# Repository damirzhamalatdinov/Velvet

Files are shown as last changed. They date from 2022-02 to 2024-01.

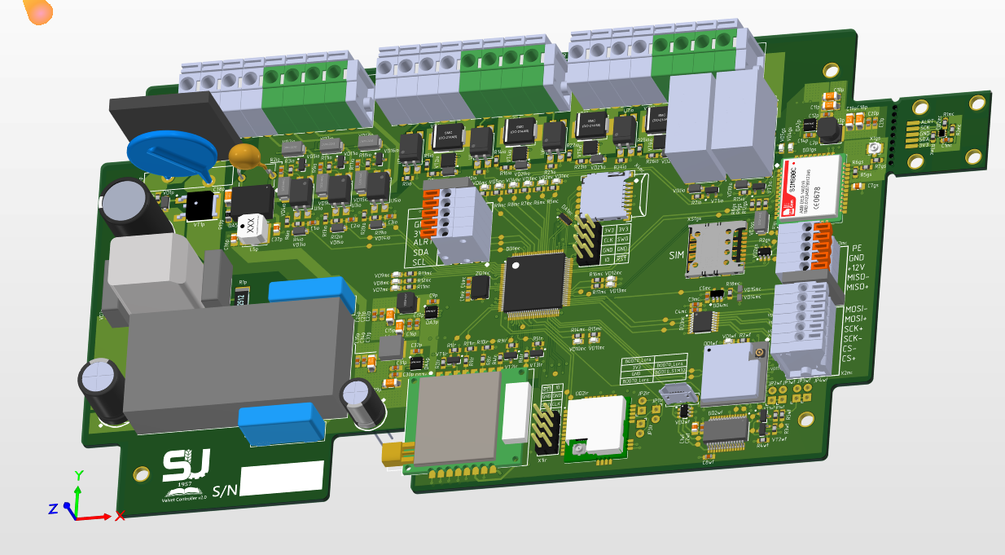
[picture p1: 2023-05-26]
Hardware_fabrication/Velvet Controller v2.0/3dview.png

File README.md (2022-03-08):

# Velvet
Репозиторий с файлами системы бесстресового взвешивания на базе STM32 (Далее: Velvet)
___
## 3D
Содержит 3D модели и сборки для системы бесстрессового взв.
* Velvet ADC - 3D модели и сборки АЦП Velvet.
* Velvet Controller - 3D модели и сборки контроллера Velvet
___
## Docs
Содержит сопутствующую проектам документацию.
* Velvet ADC - документация касающаяся АЦП Velvet
* Velvet Controller - документация касающаяся контроллера Velvet
___
## Software
Содержит исходные коды для контроллера
* Velvet Controller - исходные коды прошивки контроллера Velvet
___
## Software_release
Содержит бинарные файлы для прошивки контроллера Velvet
* Velvet Controller vX.X dd.mm.yyyy - бинарные файлы
___
## Hardware
Cодержит проекты печатных плат.
* Velvet_v1.1-2021(revised for PCB) - переработанный проект платы контроллера бестрессового взвешивания. 
    >Основная цель - актуальная библиотека компонентов. 
* Velvet ADC - проект схемы АЦП Velvet.
* Velvet Controller - проект схемы контроллера Velvet
___
## Hardware_release
Содержит файлы для производства и заказа печатных плат.
* Velvet ADC vX.X dd.mm.yyyy - файлы для производства АЦП Velvet
    * Velvet ADC Gerber vX.X dd.mm.yyyy - Gerber и NC Drill файлы
    * Velvet ADC BOM vX.X dd.mm.yyyy - список компонентов для закупа
* Velvet Controller vX.X dd.mm.yyyy - файлы для производства контроллера Velvet
    * Velvet Controller Gerber vX.X dd.mm.yyyy - Gerber и NC Drill файлы
    * Velvet Controller BOM vX.X dd.mm.yyyy - список компонентов для закупа
___
*При необходимости следует добавить папку "3D" для хранения исходных кодов*

*При необходимости следует добавить папку "Software" для хранения исходных кодов*

*При необходимости следует добавить папку "Файлы для производства и заказа" для хранения файлов для производства ПП и заказа комплектующих*

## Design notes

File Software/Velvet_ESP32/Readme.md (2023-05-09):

### Velvet_ESP32_STM_UART
   Проект ESP32_STM_UART предназначен для реализации протокола общения между микроконтроллерами ESP32 и STM32
с использованием интерфейса UART. Проект содержит файлы ESP32_STM_UART.h и Settings_ESP.h.
Структура проекта
 *main.cpp*
 *ESP32_STM_UART.h*
 *ESP32_STM_UART.cpp*
 *Settings_ESP.h*

**Протокол общения**
    Протокол общения между устройствами STM и ESP32 описан в документации проекта.
Протокол общения между устройствами представляет собой набор команд, передаваемых по UART. Команды от STM32
содержат определенные значения, указывающие на тип команды и ее параметры. Команды от ESP32 являются ответами на
соответствующие команды от STM32 и содержат информацию о выполнении команды и ее результатах.
В библиотеке ESP32_STM_UART реализованы методы для обработки входящих команд, отправки их на STM32, а также для
обработки ответов от STM32. Кроме того, библиотека содержит дополнительные методы для работы с UART, такие как
настройка скорости передачи данных и установка пинов для подключения интерфейса UART.
Для работы с библиотекой необходимо создать объект класса ESP32_STM_UART и вызвать методы для обработки команд и
отправки ответов. Подробная документация по каждому методу доступна в соответствующих файлах с исходным кодом.

## Инструкция к проекту.
    Для того чтобы собрать проект первым делом необходимо установить PlatformIO IDE. 
Если вы используете VSC установите расширение **PlatformIO IDE**. По завершению установки 
в левой боковой панели должна появиться иконка *PlatformIO IDE*. Кликните и откройте папку с проектом 
**Open project** или **Pick Folder**.
Если сделано правильно в нижней панели появится галочка **PlatformIO:Build Project**. Нажмите на нее и по завершению 
сборки проекта появиться сообщение 
============================== [SUCCESS] Took 12.48 seconds ========================== 

## Doxygen
# Инструкция по запуску doxygen
    Для начала необходимо установить doxygen на ОС. Если вы используете Ubunutu введите следующие команды в терминал:
*sudo apt update*
*sudo apt install doxygen*
    После этого откройте файл **Velvet_ESP32_STM_UART/docs/doxygen/doxygen_confing_2**
Замените следующие строки 
INPUT     = "**/full/path/to/project**/Velvet_ESP32_STM_UART"
OUTPUT_DIRECTORY       = "**/full/path/to/project**/Velvet_ESP32_STM_UART/docs/doxygen/output"
Как замена пути к проекту будет произведена перейдите в Velvet_ESP32_STM_UART/docs/doxygen/ 
и запустите команду в терминале **doxygen doxygen_confing_2**. В результате выполнения команды 
создается папка Velvet_ESP32_STM_UART/docs/doxygen/output. Перейдите в неё, затем в папку html. 
Запуститt файл index.html в браузере.

    Ссылка к инструкции по установке Doxygen https://www.doxygen.nl/manual/install.html

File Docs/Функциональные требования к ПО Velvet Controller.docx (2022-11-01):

# 1 ВВЕДЕНИЕ

Peggy Tracker создаётся для отслеживания геолокации крупного скота во время выпаса

## 1.1 Назначение данного документа

Данный документ определяет требования к встраиваемому программному обеспечению системы Velvet Controller, для исключения ошибок проектирования программного обеспечения, которые могут вызвать систематические отказы. Данный документ является входной информацией для документов «Архитектура программного обеспечения», «Описание программного обеспечения» и для непосредственной реализации программного обеспечения.

## 1.2 Термины, определения и сокращения

Встраиваемое программное обеспечение - программное обеспечение, непосредственно реализующее функции управления устройством, как правило, записанное в энергонезависимое ПЗУ устройства и заменяемое с помощью специальных программно-аппаратных средств.

ПО – программное обеспечение.

МК – микроконтроллер.

ТЗ – техническое задание.

ЦСМ – централизованная система мониторинга.

## 1.3 Рекомендации к ознакомлению

Перед ознакомлением данного документа рекомендуется изучить техническое задание (Техническое задание Velvet) и технические проекты (Технический проект Velvet Controller, технический проект Velvet ADC) на устройство Velvet Controller и Velvet ADC, а также следующие ссылки:

## 1.4 Назначение разработки

ПО разрабатывается для Velvet Controller на базе микроконтроллера STM32F407.

Структурная схема устройства Velvet Controller представлена на рисунке 1.

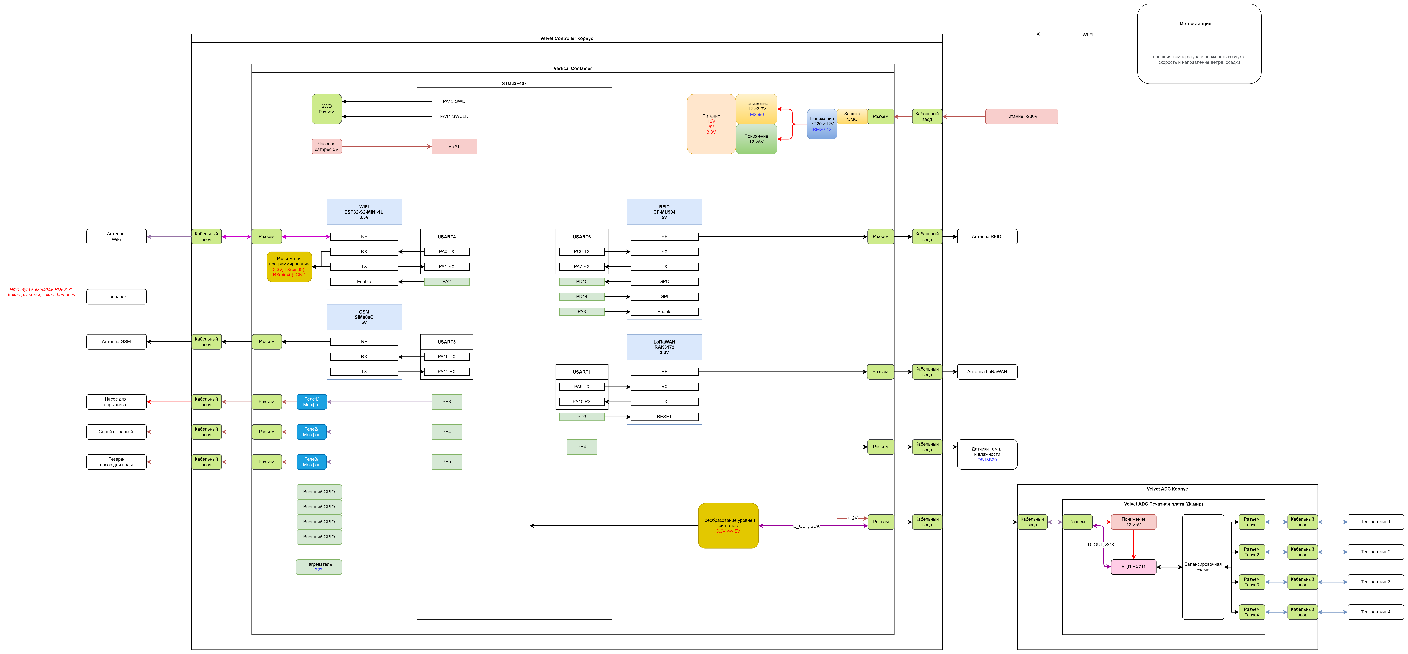
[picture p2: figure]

Рисунок 1.1 - Структурная схема устройства Peggy Tracker

МК STM32F407 содержит в себе ядро ARM Cortex M4. МК содержит до 1MБ Flash памяти программ и до 192КБ ОЗУ, 12 битный АЦП, SPI, I2C, I2S, UART интерфейсы.

# 2 Общие характеристики устройства

Задачей системы является идентификация КРС по RFID метке, фиксация веса КРС и отправка по протоколам Wi-Fi/GSM/LoRa, опрыскивание КРС по заданному алгоритму, мониторинг питания и климат контроль устройства Velvet. Первоначальный запуск системы осуществляется с участием человека, а дальнейшая работа происходит автоматически.

## 2.1 Функции, выполняемые устройством

Удаленное обновление ПО устройства.

Идентификация КРС при помощи RFID меток.

Измерение веса КРС при помощи дополнительного модуля АЦП Velvet ADC.

Опрыскивание КРС медицинскими препаратами.

Опрыскивание КРС краской.

Взаимодействие с сервером посредством Wi-Fi.

Взаимодействие с сервером посредством LoRa.

Взаимодействие с сервером посредством GSM.

Управление подогревом устройства.

## 2.2 Основные ограничения

1) Язык программирования C. Ограничение среды программирования применяемых МК.

## 2.3 Зависимости и влияние

Среда разработки STM32 Cube IDE или любая другая совместимая с микроконтроллерами STM32.

Для программирования МК может быть применен любой софт поддерживающий программатор ST-Link v2 или J-Link.

# 3 Определение требований

1) Программный код должен гарантированно выполняться за определённое время.
1) Необходимо обеспечить надежный алгоритм доставки сообщений до сервера.
2) Необходимо предусмотреть автоматическую перезагрузку устройства в случае зависания.
3) Необходимо предусмотреть удаленное обновление прошивки микроконтроллера.

## 3.1 Требования к функционированию МК

### 3.1.1 Удаленное обновление ПО устройства

Т.к. основной алгоритм ПО Velvet Controller исполняется на контроллере STM32F407 необходимо предусмотреть удаленное обновление ПО данного контроллера посредством Wi-Fi. ПО контроллера должно загружаться с удаленного сервера по HTTP протоколу. После получения бинарного файла необходимо подсчитать контрольную сумму CRC во избежание ошибок при передаче. Полученный файл должен быть загружен во Flash память контроллера STM32F407.

### 3.1.2 Идентификация КРС при помощи RFID меток

Для считывания RFID меток устройство имеет на борту модуль RFID CF-MU904.

Данный модуль подключен к МК STM32F407 через интерфейс USART6 и 3 GPIO. Один из GPIO управляет питанием модуля, два других используются для обмена событиями между контроллером и модулем.

Когда животное входит в зону видимости антенны RFID метка должна быть считана. Контроллер должен расшифровать ID животного и проверить CRC.

### 3.1.3 Измерение веса КРС при помощи дополнительного модуля Velvet ADC

Когда животное встает на платформу тензометрические датчики изменяют сигнал на своих выходах. Данный выходной сигнал оцифровывается высокоточных 24-х битным АЦП встроенным в Velvet ADC. Velvet Controller должен постоянно опрашивать значение сигнала на выходе Velvet ADC. Если животное было верно идентифицировано модулем RFID, вес можно считать корректным. Возможно применение дополнительных ограничивающих факторов для наиболее полной валидации данных Velvet ADC.

### 3.1.4 Опрыскивание КРС медицинскими препаратами / краской.

Когда животное на платформе корректно идентифицировано и взвешено, необходимо запросить с сервера информацию об опрыскивании. Сервер должен вернуть тип опрыскивания: краска или препарат; объём препарата / краски для опрыскивания. Если сервер вернул эти данные, то необходимо начать опрыскивание. Необходимо постоянно проверять валидно ли взвешивание животного и не вылит ли заданный объём препарата. Если опрыскивание прервано по одному из условий, то необходимо отправить на сервер объём вылитого препарата / краски.

### 3.1.5 Взаимодействие с сервером посредством Wi-Fi.

Для взаимодействия с сервером на борту Velvet Controller установлен модуль ESP32-S2-MINI-1U. Данный модуль связан с МК STM32F407 по интерфейсу USART4. МК STM32F407 может перезагрузить модуль ESP32-S2-MINI-1U при помощи входа ENABLE модуля.

Обмен данными с сервером реализуется по протоколу HTTP.

ESP32-S2-MINI-1U должен иметь возможность обновить ПО STM32F407.

### 3.1.6 Взаимодействие с сервером посредством LoRa.

Для взаимодействия с сервером на борту так же имеется модуль RAK3172. Модуль подключен к МК через интерфейс USART1. Модуль может быть выключен и включен входом RESET модуля. Модуль RAK3172 может быть использован только для отправки данных на сервер. При этом необходимо наличие шлюза LoRa внутри радиуса действия передатчика RAK3172. Шлюз должен выполнять функцию инкапсуляции данных полученных по LoRa в пакеты для сервера.

Пакеты LoRa должны обязательно содержать аппаратную контрольную сумму CRC. CRC должен проверяться на стороне шлюза.

### 3.1.7 Взаимодействие с сервером посредством GSM.

Для взаимодействия с сервером на борту также имеется модуль GSM SIM800C. Модуль подключен к контроллеру по USART3. Модуль поддерживает взаимодействие с сервером по сотовому протоколу 2G. Обмен данными может быть двусторонним.

### 3.1.8 Управление подогревом устройства.

На борту Velvet Controller присутствует датчик температуры DS18B20 и реле для управления нагревательным элементом. Данные датчика температуры должны считываться раз в минуту, должна производиться проверка CRC. В зависимости от показаний датчика включается или выключается нагреватель.

Температура внутри корпуса не должна опускаться ниже -20⁰C. с гистерезисом +-2⁰С.

# 4 ЛИСТ РЕГИСТРАЦИИ ИЗМЕНЕНИЙ

№ п/п | Пункт и вносимое изменение | Ф.И.О. внесшего изменения | Подп. | Дата
1 | Инициация | Байгуаныш С. | | 06.06.2022г.

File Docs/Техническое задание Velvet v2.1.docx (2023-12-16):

СОДЕРЖАНИЕ

# 1 Назначение

Предназначен для применения в составе системы автономного взвешивания и опрыскивания крупного рогатого скота Санта-Барбара.

# 2 Требования к функциональному составу

Возможность подключения от одного до четырех мостовых тензометрических датчиков.

Возможность балансировки сопротивления датчиков.

Вход для антенны WIFI диапазон 2.4ГГц.

Вход для антенны GSM.

Вход для антенны RFID 868МГц.

Вход для антенны LoRa 868МГц.

2 выхода для коммутации нагрузки постоянного тока 9-36В, 10А.

2 выхода для коммутации нагрузки переменного тока 220В 2А.

2 входа для подключения датчиков типа геркон.

Вход для подключения датчика дальности.

Система подогрева печатной платы.

Вход для питания от источника постоянного тока 9-36В.

Вход для программирования микроконтроллера STM32.

Вход для программирования микроконтроллера ESP32.

Слот для подключения micro SIM карты.

Слот для подключения micro SD карты.

3 светодиодных индикатора для программных задач.

Индикация наличия питания 9-36В.

ЭМС по ГОСТ 30804.6.1-2013.

# 3 Требования к интерфейсам

Отсутствуют.

# 4 Требования к цепям измерения и управления

## 4.1 Аналоговые входы

К аналоговым входам должны подключаться до четырех мостовых тензометрических датчика. Схема подключения приведена ниже:

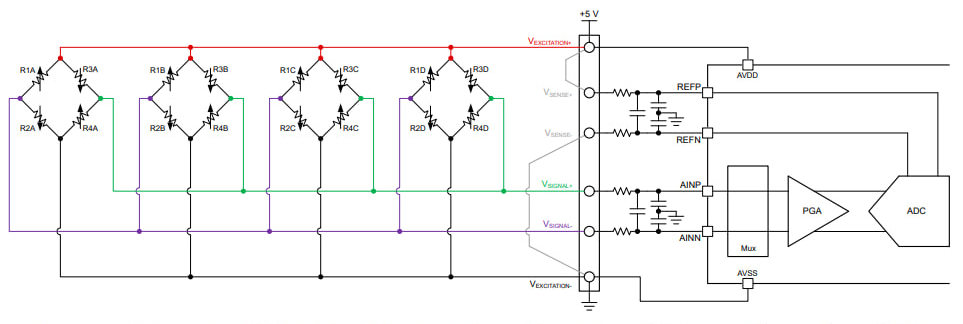
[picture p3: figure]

Рисунок 1 – схема подключения тензометрических датчиков

К аналоговых входам будут подключаться тензометрические датчики Zemic H8C-C3-500KG. Необходимо учесть возможность подключения датчиков по 4-ёх и по 6-ти проводной схеме подключения

## 4.2 Дискретные выходы:

Параметры дискретных выходов для коммутации нагрузки постоянного напряжения: напряжение нагрузки 9-36В, ток нагрузки продолжительно 10А, максимальная частота переключения 0.5Гц.

Параметры дискретных выходов для коммутации нагрузки переменного напряжения: номинальное действующее напряжение 220В, ток 2А, максимальная частота переключения 0.5Гц.

## 4.3 Дискретные входы

Логический ноль 0…4В

Логическая единица 9…24В

Диапазон питающего постоянного напряжения 9-36В.

# 5 Требования к схемотехническим решениям

Схемотехника изделия должна быть разработана согласно блок схеме на рисунке ниже.

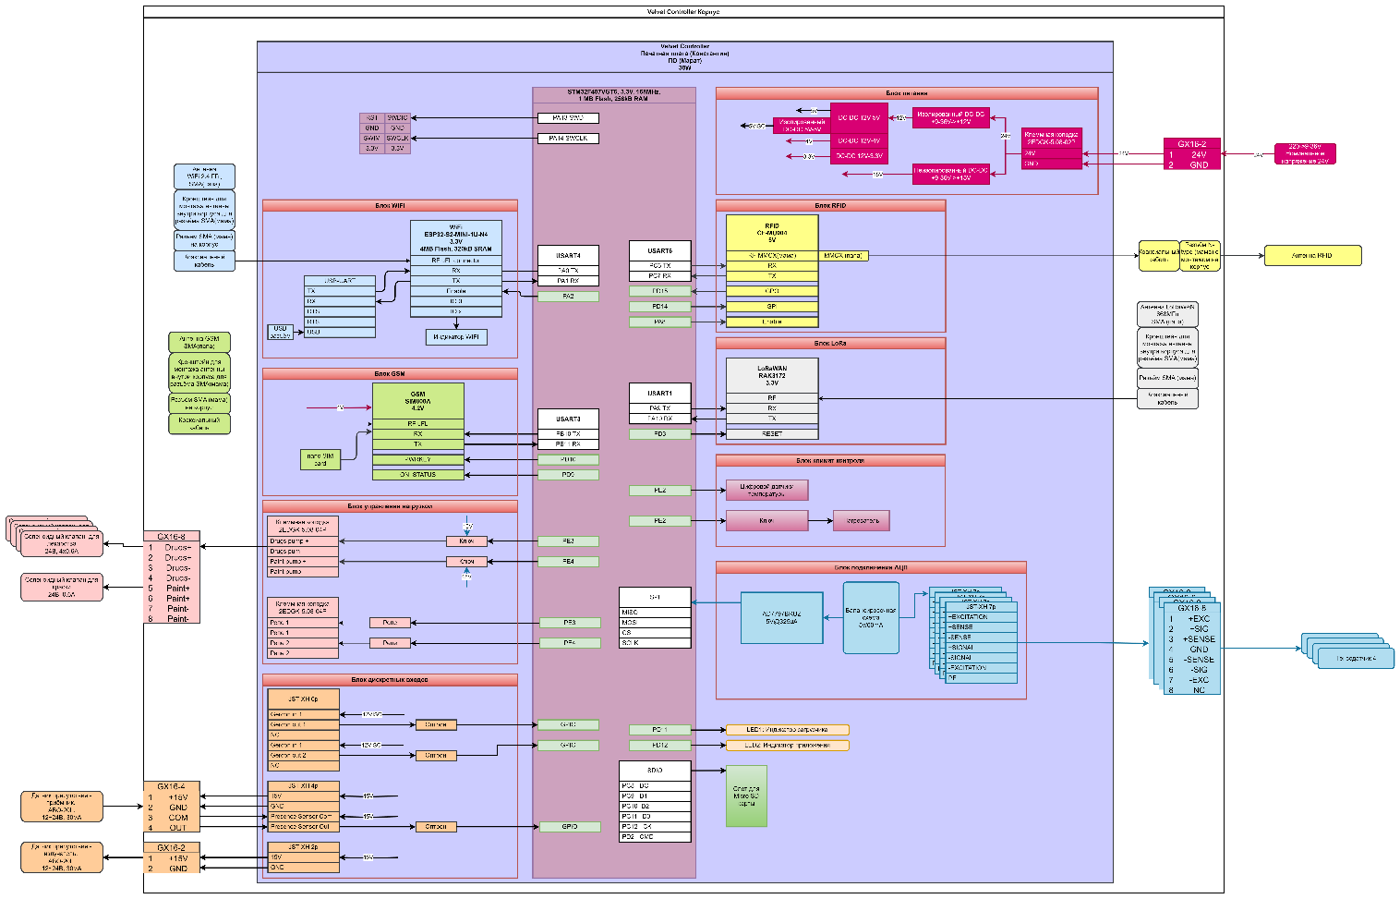
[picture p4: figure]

Рисунок 2 – Структурная схема Velvet v2.1

## 4.4 Питание

Питание может осуществляться от источника постоянного напряжения 9-36В.

Вход для источника постоянного напряжения должен быть защищен от обратного включения полярности. Вход питания 9-36В должен быть защищен от помех как порт электропитания постоянного тока по ГОСТ 30804.6.1-2013.

Наличие питания должно отображаться светодиодным индикатором зеленого цвета.

Подключение питания к корпусу должно осуществляться через разъём GX16-2. Питание от корпуса должно подключаться кабелем к печатной плате при помощи клеммной колодки типа 2EDGK-5.08-02P прямого типа.

Цепи питания МК1 и МК2 должны быть изолированы от цепи питания 9-36В.

Для работы Velvet необходимо обеспечить следующие уровни напряжения: 3.3В, 4В, 5В, дополнительная изолированная цепь питания 5В, 15В для питания датчика присутствия, 24В для питания соленоидов.

## 4.5 Блок микроконтроллера

В качестве основного контроллера должен быть использован МК STM32F407VGT6 (далее МК1).

Для программирования МК должен использоваться интерфейс SWD. Разъём совместимый с TSW-104-07-F-D. При виде сверху распиновка разъёма должна соответствовать приведенной на рисунке ниже:

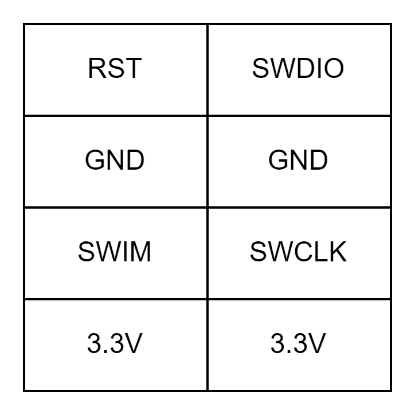
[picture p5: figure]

Рисунок 3 – разъём SWD для программирования МК1

Интерфейс SWD должен быть защищен как сигнальный порт по ГОСТ 30804.6.1-2013.

На передней панели необходимо вывести светодиодные индикаторы для отображения работы загрузчика (жёлтый) и основного приложения (красный).

## 4.6 Блок WIFI

Для подключения к сети интернет по технологии WIFI необходимо использовать модуль ESP32-S2-MINI-1U (далее МК2).

Необходимо обеспечить индикацию для модуля светодиодным индикатором, подключенным к свободному выходу общего назначения.

МК1 и МК2 должны быть соединены по интерфейсу UART.

Протокол передачи данных описан в документе «Протокол передачи данных ESP-STM».

Блок WIFI должен быть снабжён коаксиальным кабелем uFL <-> SMA (мама) для соединения с антенной, антенной с разъёмом SMA (папа).

МК1 должен иметь возможность перезагрузить МК2.

Для загрузки в память МК2 управляющей программы необходимо использовать преобразователь USB-UART с дополнительными сигналами DTR, RTS.

Предусмотреть возможность ручной установки уровней сигналов EN, IO0 МК2.

Необходимо установить вертикальный разъём типа Micro USB type B для подключения кабеля Micro-USB. Разъём представлен на рисунке ниже.

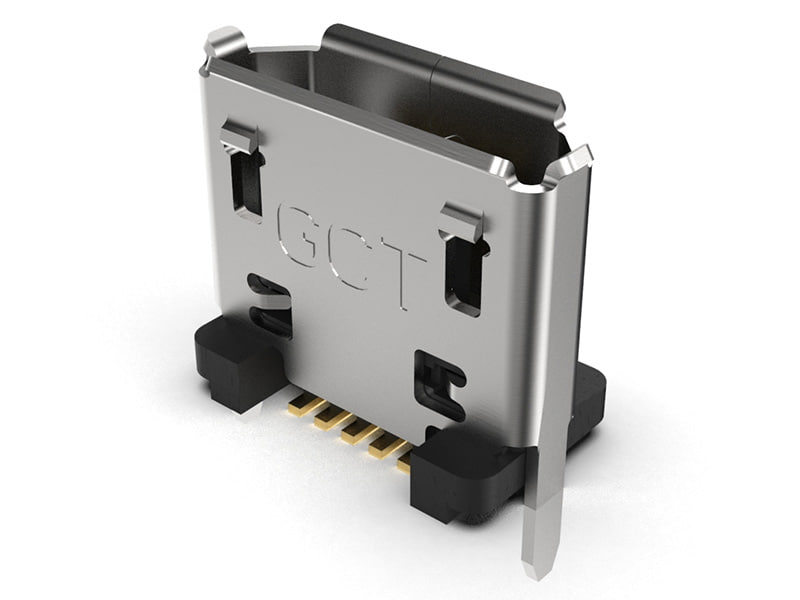
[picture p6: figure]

Рисунок 4 – разъём Micro USB type B

USB порт должен быть защищен как сигнальный порт по ГОСТ 30804.6.1-2013.

## 4.7 Блок GSM

Необходимо использовать модуль GSM SIM800A (далее модуль GSM).

Должна быть возможность установки SIM карты формата NANO.

SIM карта должна устанавливаться и выниматься без извлечения платы из корпуса.

МК1 должен быть подключен к GSM по протоколу UART. Сигналы модуля GSM должны быть согласованы с сигналами МК1. МК1 должен иметь возможность перезагружать модуль GSM.

Блок GSM должен включать антенну GSM с разъёмом SMA (папа) и кабельную сборку с разъёмами uFL и SMA (мама),

Слот подключения SIM карты должен быть защищен как сигнальный порт по ГОСТ 30804.6.1-2013.

## 4.8 Блок управления нагрузкой

Блок управления нагрузкой используется для коммутации питания соленоидных вентилей и опциональной нагрузки переменного тока.

Соленоидные вентили используются для подачи лекарства и краски под давлением через специальные форсунки. Клапаны нормально закрытые. Для открытия необходимо подать напряжение на их контакты. Питание для соленоидов должно подаваться через печатную плату Velvet. Силовые линии должны быть изолированы от внутренних сигнальных цепей и цепей питания МК1 и МК2 Velvet.

Напряжение питания соленоидов должно быть в диапазоне от 12В до 36В постоянного тока до 1А. Максимальная частота переключения 0.5Гц. На один выход может быть подключено до 4-ёх соленоидов параллельно. Общий максимальный ток при этом может достигать 4А.

Соленоиды должны подключаться к корпусу при помощи разъёмов GX16-8. Сигналы от корпуса к печатной плате должны подключаться кабелем с клеммной колодкой типа 2EDGK-5.08-4P.

В качестве опциональной нагрузки могут также использоваться двигатели переменного тока. Необходимо установить 2 дополнительных независимых релейных выхода для коммутации номинального переменного напряжения 220В, ток 2А с максимальной частотой переключения 0.5Гц. Подключение нагрузки к релейному выходу должно осуществляться через клеммную колодку типа 2EDG.

## 4.9 Блок дискретных входов

Контроллер должен иметь возможность считывать данные с 3-х цифровых датчиков:

- 2 геркона

- 1 датчик прерывания луча.

Подключение герконов к печатной плате должно осуществляться при помощи разъёма JST-XH 6pin.

В качестве датчика прерывания луча для детектирования животного в зоне действия используется датчик ABO-20L состоящий из излучателя и приемника. Напряжение питания датчика 12~24В, максимальный ток потребления 30мА. Для подключения излучателя к корпусу Velvet должен используется разъём GX16-2. Для подключения приемника должна использоваться кабельная сборка с разъёмом GX16-6 и разъёмом JST-XH. Приемник имеет релейный выход (режим работы NC/NO можно выбрать при помощи перемычек в датчике).

Схема включения датчиков прерывания луча:

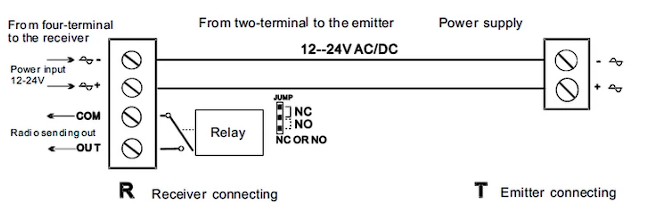
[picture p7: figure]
10pair/lot Access control system Anti-rain (fog) Active Infrared outdoor Beam Sensor With anti-RFI / EMI capability ABO-20L | AliExpress и еще 10 страниц — Личный: Microsoft Edge

Рисунок 5 – Схема включения датчика прерывания луча

Порты должны быть защищены от статики как сигнальные порты по ГОСТ 30804.6.1-2013.

## 4.10 Блок карты памяти

Для хранения логов и другой информации необходимо использовать съёмный накопитель информации - карту типа MicroSD.

Карта должна устанавливаться без извлечения печатной платы из корпуса.

Объём карты памяти до 4 ГБ класс 6.

Порт для установки карты должен быть защищен от статики как сигнальный порт по ГОСТ 30804.6.1-2013.

## 4.11 Блок климат контроля

Для обеспечения рабочего режима температуры модуля RFID требуется добавить систему климат контроля внутри корпуса.

Для измерения температуры должен использоваться цифровой датчик с максимальной абсолютной погрешностью измерения ±1⁰С.

Микроконтроллер должен иметь возможность сбрасывать работу датчика температуры.

Для обогрева воздуха используется нагреватель, устанавливаемый на печатной плате.

## 4.12 Блок LoRa

Блок LoRa построен на базе модуля RAK3172. Блок должен управляться при помощи UART интерфейса МК1. МК1 должен иметь возможность сбрасывать работу модуля LoRa.

Необходима возможность переключения уровней напряжения сигнала BOOT модуля RAK3172.

Подключение антенны к модулю аналогично блоку WIFI при помощи коаксиального кабеля uFL <-> SMA (мама).

## 4.13 Блок RFID

В основе блока RFID должен быть использован модуль CF-MU904 (868MHz).

Для подведения радиочастотного сигнала от корпуса к модулю должен использоваться коаксиальный кабель с разъёмами MCX (папа) <-> N-type (папа).

Сигналы модуля RFID должны быть согласованы с сигналами МК1

МК1 должен иметь возможность сбрасывать работу модуля.

МК1 должен иметь возможность задействовать дополнительные входы и выходы общего назначения модуля (GPI, GPO).

## 4.14 Блок АЦП

Блок АЦП должен обеспечивать подключение от одного до четырёх тензометрических датчиков по четырёхпроводной или шестрипроводной схеме.

Тензометрические датчики должны подключаться к устройству кабельной сборкой с разъёмом GX16-8 и разъёмом JST-XH.

В качестве АЦП рекомендуется использовать микросхему AD7797BRUZ.

Входы должны быть защищен от статики как сигнальные порты по ГОСТ 30804.6.1-2013.

# 6 Требования к конструктиву

В качестве корпуса устройства требуется использовать корпус Xiamen Yingxin Electric Technology Co., LTD YX-F10. Чертеж и общий вид представлены на рисунке ниже.

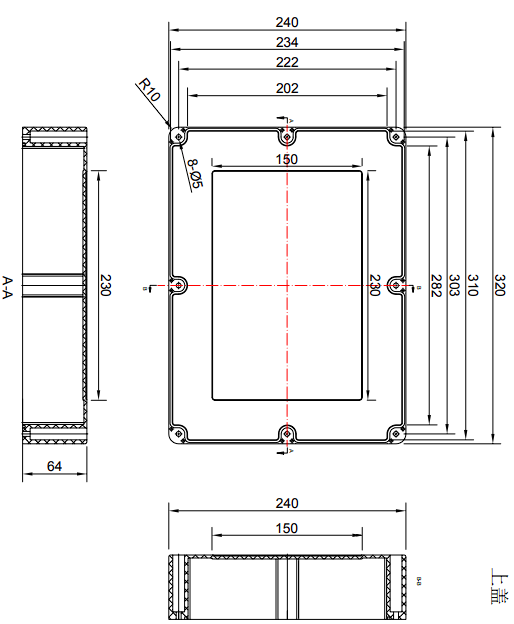
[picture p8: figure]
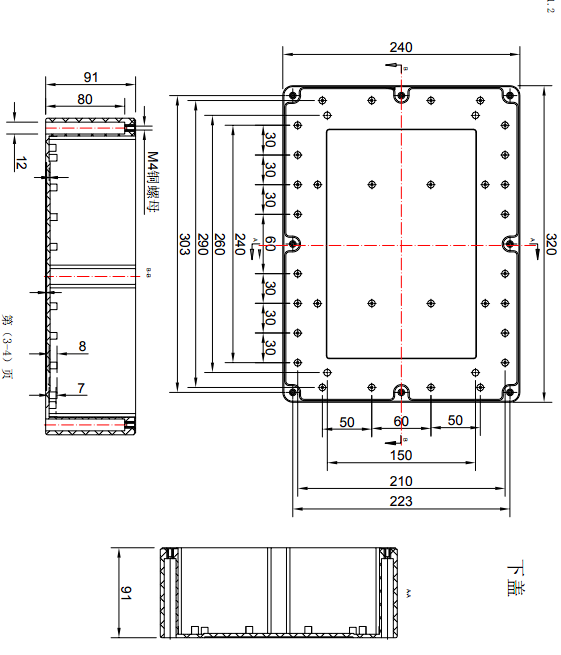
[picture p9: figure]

Рисунок 6 – корпус Velvet YX-F10

Печатная плата должна крепиться к основанию корпуса с использованием предусмотренных в корпусе углублений для винтов. Печатная плата должна монтироваться при помощи 6-ти винтов.

Velvet v2.1 должен включать в себя:

- печатная плата 1,
- корпус 1,
- комплект метизов для закрепления печатной платы в корпусе,
- кабельная сборка для подключения питания с разъёмом GX16-6 и клеммной колодкой 2EDGK-5.08-02P,
- кабельная сборка для подключения соленоидных клапанов с разъёмом GX16-8 и клеммной колодкой 2EDGK-5.08-04P,
- кабельная сборка для подключения приемника датчика присутствия с разъёмом GX16-4 и разъёмом JST-XH 4pin
- кабельная сборка для подключения излучателя датчика присутствия с разъёмом GX16-2 и разъёмом JST-XH 2pin
- 4 кабельные сборки для подключения тензометрических датчиков с разъёмом GX16-8 и JST-XH 7pin
- Радиочастотная кабельная сборка с разъёмом N-type (мама) и разъёмом MMCX (папа) для подключения антенны RFID
- 3 радиочастотные кабельные сборки с разъёмом SMA (мама) и разъёмом uFL для подключения антенн LORA, WIFI и GSM,
- 3 кронштейна для монтажа антенн с разъёмом SMA внутри корпуса
- антенна GSM 1,
- антенна LORA 1,
- антенна WIFI 1,

Разъёмы питания, датчика присутствия (приемник и излучатель), соленоидов, тензометрических датчиков должны располагаться по длинной стороне корпуса. Антенны необходимо располагать ближе к противоположной стенке.

На рисунке ниже представлена монтажная схема устройства:

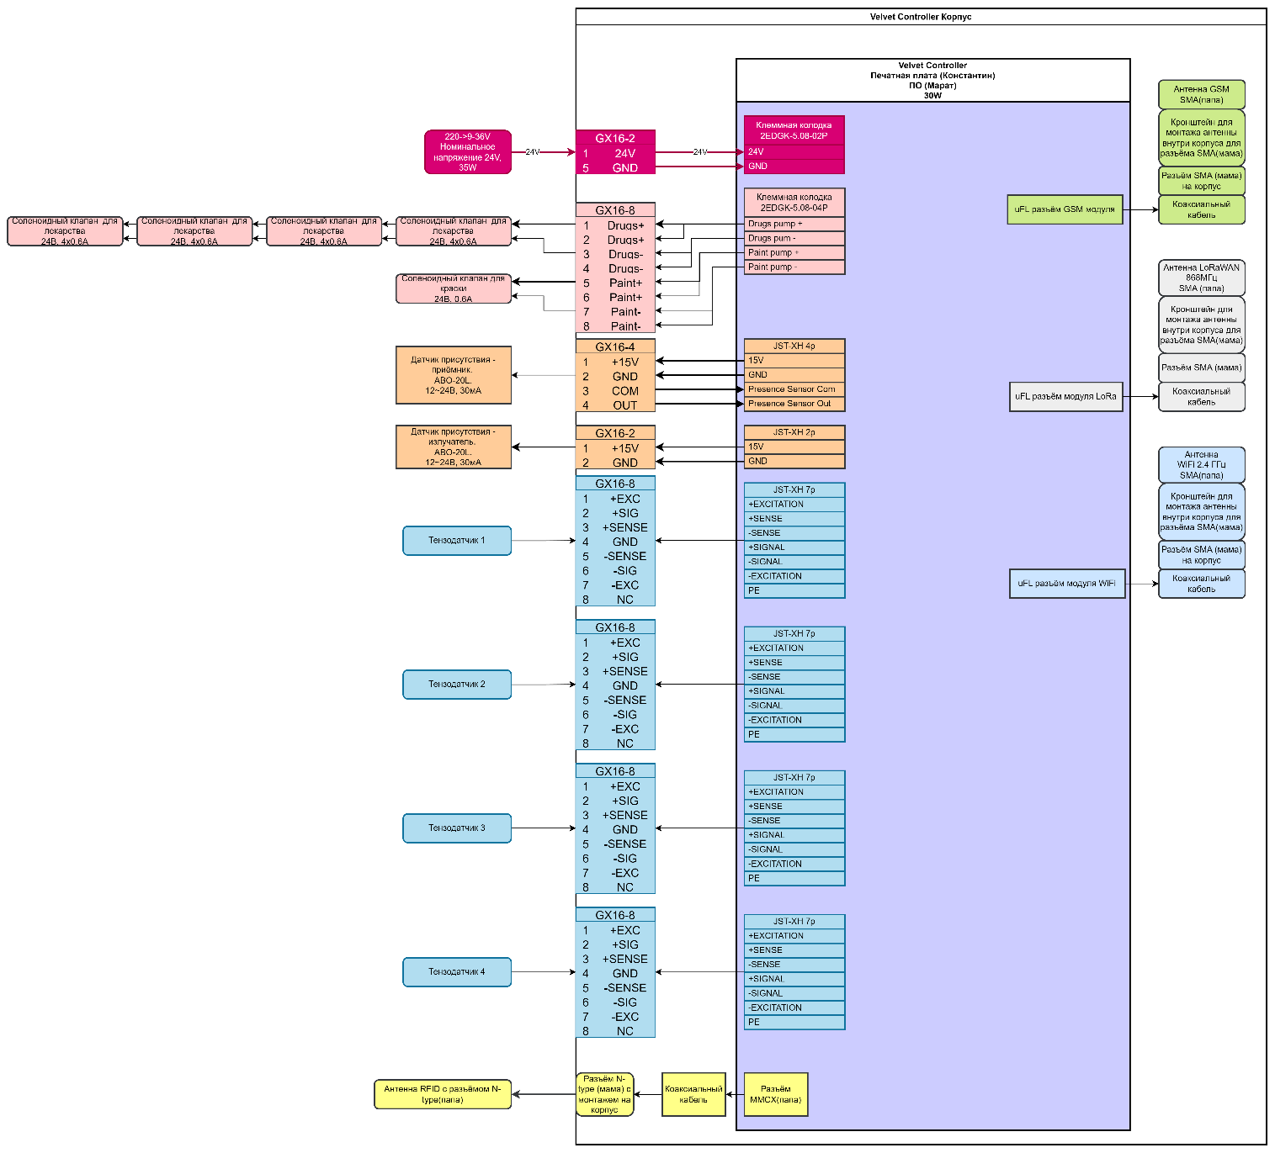
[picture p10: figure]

Рисунок 7 – монтажная схема Velvet

Для подключения тензодатчиков, датчиков присутствия и питания к корпусу рекомендовано использовать разъёмы типа GX16.

Для подключения сигналов тензодатчиков и датчиков присутствия от разъёмов GX16 к печатной плате рекомендовано использовать кабельную сборку с разъёмом типа JST-XH на одном конце.

Для подключения сигналов управления соленоидами и питания от разъёмов GX16 необходимо использовать провода с клеммными колодками типа 2EDGK-5.08.

В качестве антенн GSM, WIFI и LoRa необходимо использовать антенны с разъёмом типа SMA (папа) с внутренней резьбой. Для подключения антенн к печатной плате необходимо использовать кабельную сборку с разъёмом uFL и SMA (мама). Антенны должны фиксироваться внутри корпуса. Способ крепления антенн внутри корпуса на усмотрение инженера. Крепление должно обеспечивать простой демонтаж антенн в целях ремонтопригодности.

Для подключения антенны RFID необходимо использовать кабельную сборку типа RF316-03RP1-06BJ2-0152 с разъёмом N-type (мама) на одном и MMCX (папа) на другом конце. Разъём N-type должен быть вмонтирован в корпус устройства.

Требования к печатной плате:

1. Класс точности не выше 4
2. Толщина ПП 1.6мм
3. Количество слоёв не больше 4
4. Печатные платы, геометрия контактных площадок, а также взаимное расположение КП относительно друг друга должно быть оптимизировано под автоматический монтаж
5. Компоненты размещать на верхней стороне ПП, при необходимости возможно размещение компонентов, монтируемых автоматически на одной из сторон, а монтируемых вручную - на верхней или обеих сторонах. Допускается так же монтаж SMD компонентов на обеих сторонах ПП при условии примерно равного по плотности размещения компонентов на каждой из сторон ПП
6. Свободные от сигнальных цепей площади ПП на нижней стороне должны быть залиты полигоном, подключенным к заземляющей клемме внешнего питания модуля (PE).
7. На лицевой стороне печатной платы необходимо разместить изображение герба КазАТУ им.С.Сейфуллина.
8. Разъёмы на печатной плате должны быть промаркированы, контакты подписаны.

# 7 Требования к проектированию и сдаче проекта заказчику

1. 3 действующих, отлаженных образца изделия.
2. Комплект конструкторской документации, состоящий из:
  a. Схема электрическая принципиальная Э3 (PDF)
  b. Перечень элементов ПЭ3 (в формате XLSX – Microsoft Excel)
  c. Проект в Altium Designer с исходными файлами принципиальной схемы и печатной платы (Altium PCB project, Schematic documents, PCB document)
  d. Технический проект с описанием инженерных решений и обоснованием выбранных компонентов
  e. Файлы для производства печатной платы в формате Gerber и NCDrill
  f. 3d визуализация печатной платы в формате STEP в корпусе без крышки
  g. 3d визуализация печатной платы без корпуса в формате STEP и 2d проекции в формате JPG
  h. Изображение слоёв печатной платы в формате PDF
  i. Опционально в случае использования средств моделирования необходимо предоставить: симуляционные модели, результаты моделирования в виде графиков (JPG, PDF) либо другой подтверждающей документации
  j. 5 устройств Velvet Controller v2.1 в заявленной комплектации, готовые к монтажу на объекте.
  k. Сборочный чертеж печатной платы в формате PDF
  l. Сборочный чертеж устройства в формате PDF
  m. Руководство пользователя в формате DOCX – Microsoft Word

# 8 ЛИСТ РЕГИСТРАЦИИ ИЗМЕНЕНИЙ

№ п/п | Пункт и вносимое изменение | Ф.И.О. внесшего изменения | Подп. | Дата
1 | Инициация | Байгуаныш С.Б. | | 16.01.2023
2 | Внесение корректировок для Velvet v2.1 | Байгуаныш С.Б. | | 14.12.2023

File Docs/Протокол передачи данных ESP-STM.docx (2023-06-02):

Протокол передачи данных ESP-STM32

№ | Название команды, название запроса(ответа) | Направление передачи | Содержимое команды {номер команды, код ответа – 8 байт*} *- за исключением передачи прошивки ESP->STM и отправки массива данных с весами STM->ESP | Период отправки
1 | Check FW CMD | STM->ESP | {0x01, Version0, Version1, 0x00, 0x00, 0x00, 0x00, 0x00} | 60 с
| Check FW RSP, Restart STM | ESP->STM | {0x01, 0x01, 0X00, 0x00, 0x00, 0x00, 0x00, 0x00} | По запросу от STM
| Check FW RSP, Connection Error | ESP->STM | {0x01, 0x02, 0X00, 0x00, 0x00, 0x00, 0x00, 0x00} | По запросу от STM
| Check FW RSP, Response no update | ESP->STM | {0x01, 0x03, 0X00, 0x00, 0x00, 0x00, 0x00, 0x00} | По запросу от STM
2 | Bootloader ready CMD | STM->ESP | {0x02, 0x01, 0X00, 0x00, 0x00, 0x00, 0x00, 0x00} | При запуске Bootloader
| Bootloader ready RSP, Size of FW | ESP->STM | {0x02, 2B Size of FW, 0x00, 0x00, 0x00, 0x00, 0x00} | По запросу от STM
3 | Ready to receive data CMD | STM->ESP | {0x03, 0x01, 0X00, 0x00, 0x00, 0x00, 0x00, 0x00} | Запущен процесс прошивки
| Transmit data RSP | ESP->STM | {0x03, 256B FW Data, 1B Data Sum*} for(i=0;i<257;i++) sum+=data[i] | По запросу от STM
| Receive data error RSP | STM->ESP | {0x03, 0xFF, 0X00, 0x00, 0x00, 0x00, 0x00, 0x00} | Данные от ESP получены с ошибкой запрос повторной передачи
4 | Send Weight CMD Transmit prepare | STM->ESP | {0x04, 0x01, 0X00, 0x00, 0x00, 0x00, 0x00, 0x00} | После вставания коровы на весы. Каждую минуту
| Send Weight RSP Transmit prepare OK | ESP->STM | {0x04, 0x02, 0X00, 0x00, 0x00, 0x00, 0x00, 0x00} | По запросу от STM
5 | Send Weight CMD Transmit weight array | STM->ESP | {0x05, 8B cow ID, 4B ts – unix epoch 4B x 60 - weight float} | По приходу Send Weight RSP Transmit prepare OK
| Send Weight RSP Response OK | ESP->STM | {0x05, 0x01, 0X00, 0x00, 0x00, 0x00, 0x00, 0x00} | После успешной отправки данных на сервер
| Send Weight RSP Transmit Wifi error | ESP->STM | {0x05, 0x02, 0X00, 0x00, 0x00, 0x00, 0x00, 0x00} | После неудачной отправки данных на сервер
6 | Get Timestamp CMD | STM->ESP | {0x06, 0x01, 0X00, 0x00, 0x00, 0x00, 0x00, 0x00} | После инициализации STM
| Get Timestamp RSP Response OK | ESP->STM | {0x06, 4B ts – unix epoch 0x00, 0x00, 0x00} x – timestamp (uint32) | По запросу от STM
| Get Timestamp RSP Response Error | ESP->STM | {0x06, 0x02, 0X00, 0x00, 0x00, 0x00, 0x00, 0x00} | По запросу от STM

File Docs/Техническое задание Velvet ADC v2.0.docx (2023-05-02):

СОДЕРЖАНИЕ

# 1 Назначение

Предназначен для применения в составе системы автономного взвешивания крупного рогатого скота массой от 50кг до 2000кг с погрешностью ±2кг.

# 2 Требования к функциональному составу

Вход для подключения Velvet Controller совмещенный с линией питания 12В

Возможность подключения до четырёх мостовых тензометрических датчика

Возможность балансировки сопротивления датчиков.

Индикация наличия питания 12В

ЭМС по ГОСТ 30804.6.1-2013

# 3 Требования к интерфейсам

SPI интерфейс для подключения Velvet ADC

1. Скорость передачи данных не менее 1кБит/с
2. Максимальная длина кабеля 10м
3. Защита от статического электричества по ГОСТ 30804.6.1-2013
4. Транспортный интерфейс LVDS

# 4 Требования к цепям измерения и управления

## 1. Аналоговые входы:

К аналоговым входам должны подключаться до четырех мостовых тензометрических датчика. Схема подключения приведена ниже:


Рисунок 1 – схема подключения тензометрических датчиков

# 5 Требования к схемотехническим решениям

Схемотехника изделия должна быть разработана согласно блок схеме на рисунке ниже.

# 5.1 Питание

Питание может осуществляться от источника постоянного напряжения 12В.

Наличие питания должно сопровождаться индикацией наличия напряжения 12В. Цвет светодиодного индикатора – зеленый.

Подключение питания должно осуществляться через подпружиненную клеммную колодку. Кабель в корпус должен заводиться через кабельный сальниковый ввод с защитой от пыли и влаги.

Вход питания должен быть защищен от помех как сигнальный порт по ГОСТ 30804.6.1-2013.

Цепи питания микросхемы АЦП должны быть изолированы от цепи питания 12В.

Для работы Velvet ADC необходимо обеспечить следующие уровни напряжения: 5В для питания цифровой части АЦП, 5В для питания датчиков, 3.3В.

## 5.2 Блок АЦП

В качестве микросхемы АЦП должна использоваться микросхема AD7797BRUZ. Управление микросхемой осуществляется по интерфейсу SPI.

Управляющие сигналы подводятся к АЦП через блок подключения Velvet Controller. Для балансировки питания и снижения влияния проводов на результат измерения питание тензодатчиков должно балансироваться при помощи балансировочных резисторов. Необходима возможность установки подстроечных резисторов и резисторов с фиксированным номиналом в балансировочную схему. Необходима возможность измерения по четырех и шести проводной схеме подключения тензометрических датчиков.

# 5.3 Блок подключения Velvet Controller

Блок подключения Velvet Controller должен быть изолирован от внутренних сигнальных и силовых цепей Velvet ADC.

Блок подключения Velvet Controller должен обеспечивать связь по кабелю длиной до 10м.

Сигналы АЦП должны передаваться в Velvet Controller в виде дифференциальных сигналов.

Вместе с сигнальными жилами через кабель должно передаваться изолированное питание для Velvet ADC 12В

Кабель заводится в корпус через кабельный ввод, защищенный от влаги и пыли. Кабель подключается к печатной плате через винтовую либо подпружиненную клеммную колодку.

Интерфейс должен быть защищен как сигнальный порт по ГОСТ 30804.6.1-2013.

При реализации транспортного интерфейса рекомендуется следовать следующему руководству: Extending the SPI bus for long-distance communication (https://www.ti.com/lit/an/slyt441/slyt441.pdf) (Texas Instruments)

# 5.4 Блок подключения тензорезистивных датчиков

Блок должен обеспечивать возможность подключения до 4-ёх тензорезистивных мостовых датчиков.

Номинальное сопротивление каждого датчика составляет 350Ом.

Питание датчиков должно обеспечиваться опорным источником питания.

Абсолютная погрешность при измерении веса не должна превышать ±20кг (±1%) при температуре окружающей среды 20⁰C.

Максимальный измеряемый вес 2000кг.

Необходима возможность индивидуальной подстройки сопротивления каждого датчика.

# 6 Требования к конструктиву

В качестве корпуса устройства требуется использовать пластиковый герметический корпус Gainta G212MF. Схема приведена ниже.

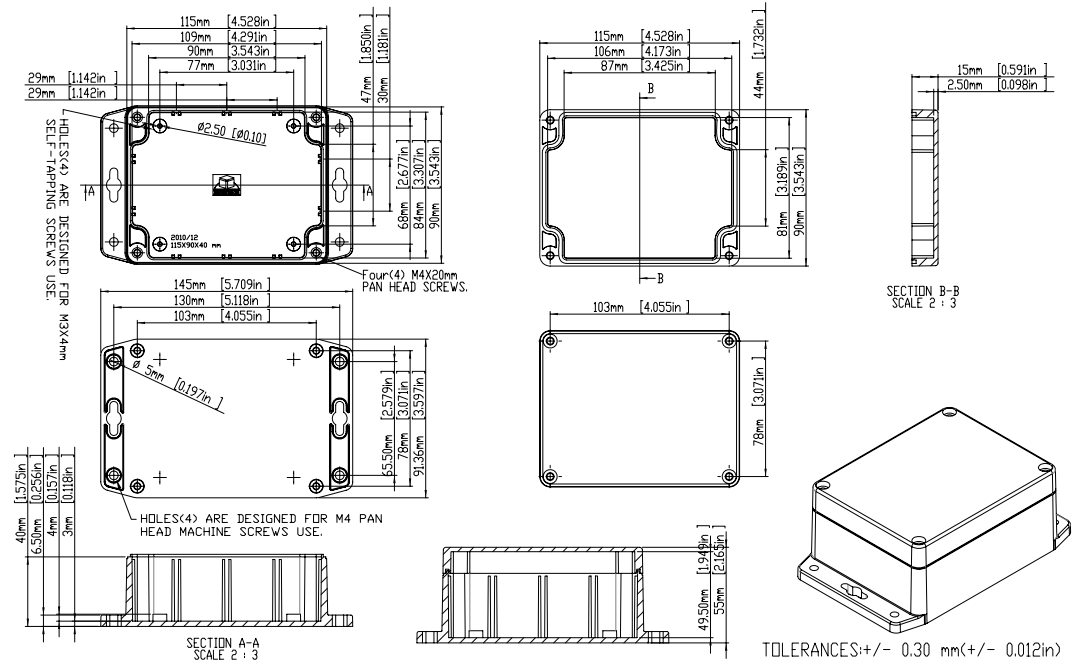
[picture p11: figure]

Рисунок 2 – корпус Velvet ADC

Печатная плата должна крепиться к основанию корпуса с использованием предусмотренных в корпусе углублений для винтов.

Velvet ADC должен включать себя одну печатную плату.

Для подключения тензорезистивных датчиков, кабеля для передачи данных и питания рекомендуется использовать авиационные разъёмы серии GX16.

GX16-8 для подключения тензорезистивных датчиков и цифрового интерфейса.

GX16-2 для подключения питания

Для подключения сигналов от разъёмов на корпусе к печатной плате рекомендуется использовать разъёмы серии 640456 или аналогичные. Чертеж вилки на плату представлен на рисунке ниже

Рисунок 3. Вилка на плату серии 640456

Требования к печатной плате:

1. Класс точности не выше 4
2. Толщина ПП 1.6мм
3. Количество слоёв не больше 4
4. Печатные платы, геометрия контактных площадок, а также взаимное расположение КП относительно друг друга должно быть оптимизировано под автоматический монтаж
5. Компоненты размещать на верхней стороне ПП, при необходимости возможно размещение компонентов, монтируемых автоматически на одной из сторон, а монтируемых вручную - на верхней или обеих сторонах. Допускается так же монтаж SMD компонентов на обеих сторонах ПП при условии примерно равного по плотности размещения компонентов на каждой из сторон ПП
6. Свободные от сигнальных цепей площади ПП на нижней стороне должны быть залиты полигоном, подключенным к заземляющей клемме внешнего питания модуля (PE)Для подключения цифровых
7. На лицевой или тыльной стороне печатной платы необходимо разместить изображение герба КазАТУ им.С.Сейфуллина.

# 7 Требования к проектированию и сдаче проекта заказчику

1. 3 действующих, отлаженных образца изделия.
2. Комплект конструкторской документации, состоящий из:

Схема электрическая принципиальная Э3 (Altium schdoc)

Проект трассированной ПП (Altium pcbdoc)

Перечень элементов ПЭ3 (MS Word)

# 8 ЛИСТ РЕГИСТРАЦИИ ИЗМЕНЕНИЙ

№ п/п | Пункт и вносимое изменение | Ф.И.О. внесшего изменения | Подп. | Дата
1 | Инициация | Байгуаныш С.Б. | | 17.03.2023

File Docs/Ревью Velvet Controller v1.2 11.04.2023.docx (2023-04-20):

# Диод VD2p

При 9В питании через диод потечет ток

(9В-2В) / 5600Ом = 1,25мА

Возможно слишком тусклое свечение

Установил резистор 1.8кОм мощностью 2Вт.

Ток будет составлять от 5мА до 20мА

# Входной фильтр питания

Хотелось бы посмотреть симуляцию в LTSpice при воздействии помех.

Кондуктивные:

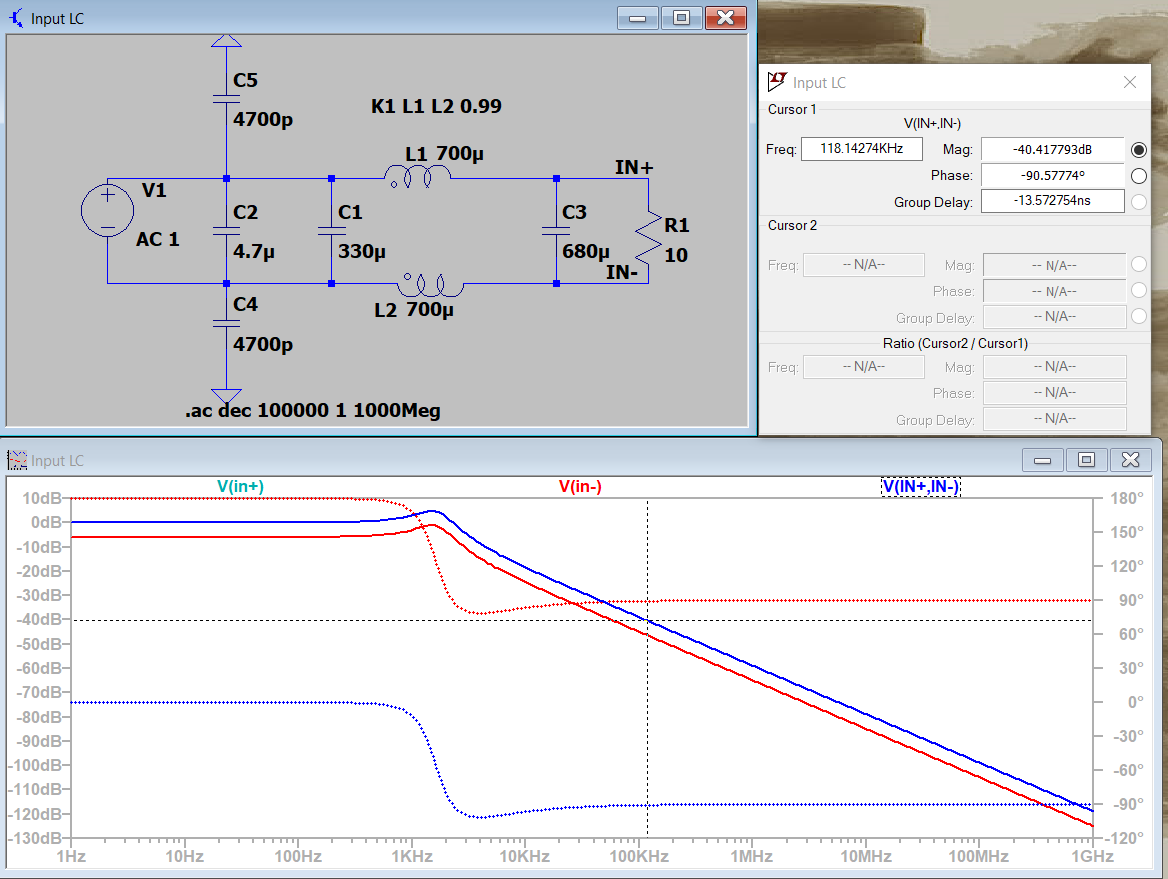
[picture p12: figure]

Входные:

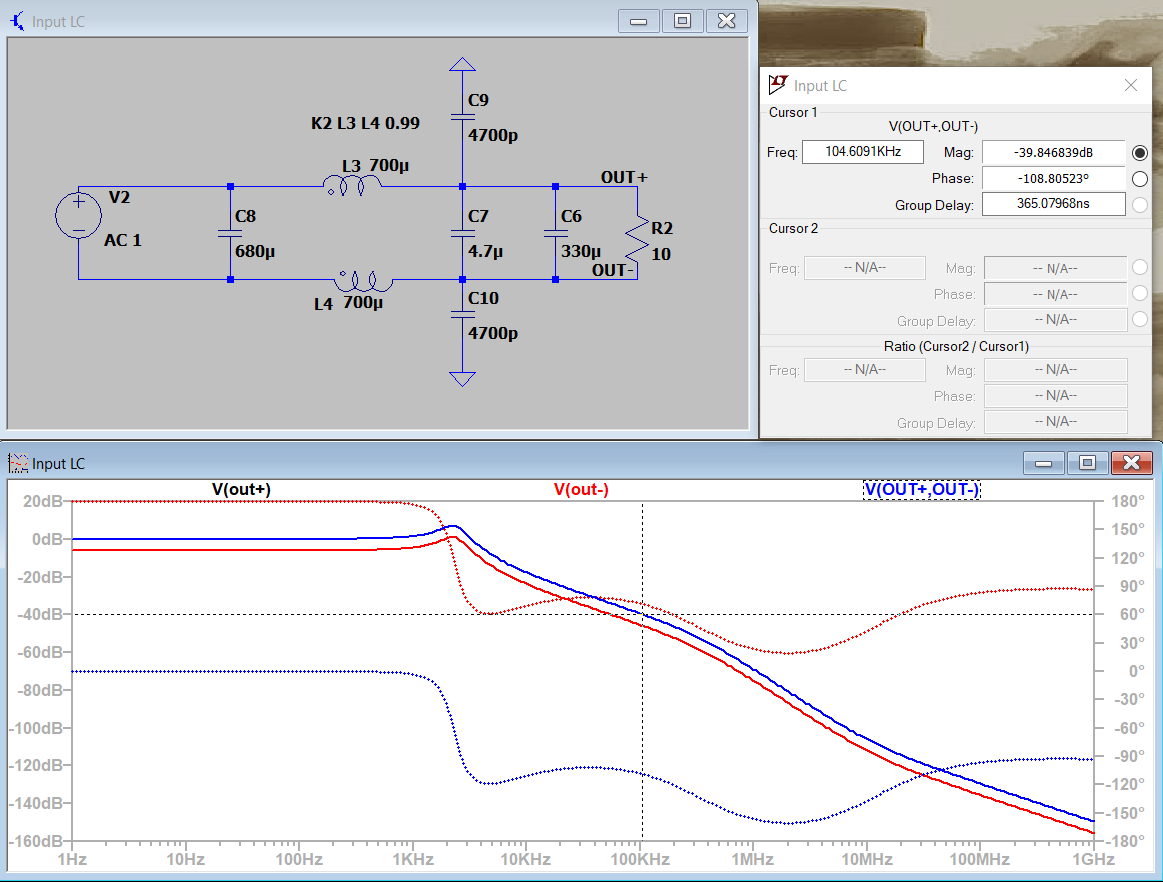
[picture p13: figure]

Компоненты фильтра рекомендованы производителем изолированного DC-DC, разрабатывал я его не сам.

# Конденсатор C25p

Не указан номинал

Обновил GRM1885C1H152JA01D

# Конденсатор C15p

Для DA2p были установлены 2 входных конденсатора -по 10мкФ, а для DA3p один, хотя отношение вход/выход у DA3p выше, чем у DA2p. Входные пульсации в схеме с DA2p будут в 2 раза меньше, чем в схеме DA3p.

Тоже самое справедливо для DA4p.

Нет, ты не прав. Номинал конденсаторов зависит от тока нагрузки. Чем больше ток нагрузки, тем выше номинал. Посмотри даташит на установленные DC-DC. Рассмотрим DC/DC 3.3V:

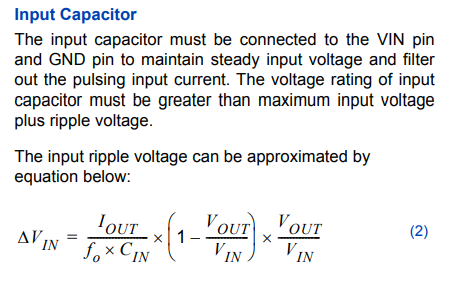
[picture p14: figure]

Вырезка из даташита к AOZ6663DI

Входное напряжение 12В, выходное 3.3В, частота DC-DC 750кГц, ток нагрузки 1А. Тогда при конденсаторе 10мкФ пульсации составят:

Давай поменяем входные данные: напряжение 4В, ток 2.5А. Тогда при том же конденсаторе получим пульсации:

Теперь понятна логика расстановки конденсаторов ?

# Конденсатор С39p

Не указан номинал

GRM1885C1H182JA01D

# Разъём X3mc

В структурной схеме указывали питание АЦП 9-36В, в ПЭ указано 12В с изолированное питание контроллера 12В. Это правильно?

Да, до АЦП пойдут изолированные 12В.

# C31r, C51r, C3wf, C4wf, C2wf, R1gs, C3gs, C7gs, C1io, C2io, C3io

Лишние точки соединения. Возможно не попадание в сетку

# Транзисторы VT2io, VT4io, VT5io, VT6io

Если на DOx_PWR будет подано максимальное допустимое напряжение 36В, то напряжение Vgs составит 18В. Максимальное допустимое напряжение Vgs для данных транзисторов составляет 20В. Возможно запас по напряжению недостаточен учитывая индуктивный характер нагрузки. Либо нужно защитить переход GS от скачков напряжения.

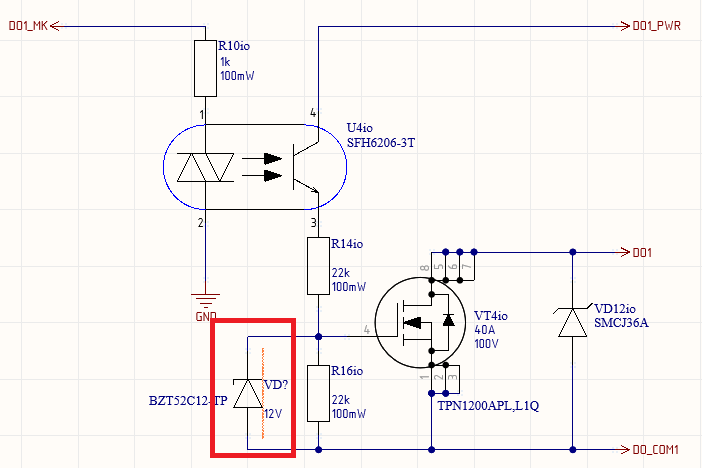
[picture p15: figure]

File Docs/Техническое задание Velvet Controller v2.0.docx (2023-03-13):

СОДЕРЖАНИЕ

# 1 Назначение

Предназначен для применения в составе системы автономного взвешивания крупного рогатого скота.

# 2 Требования к функциональному составу

Вход для подключения Velvet ADC совмещенный с линией питания 9-36V

Вход для антенны WIFI диапазон 2.4ГГц

Вход для антенны GSM

Вход для антенны RFID 868МГц

Вход для антенны LoRa 868МГц

2 выхода для коммутации нагрузки постоянного тока 9-36В, 10А

2 выхода для коммутации нагрузки переменного тока 220В 2А.

2 входа для подключения датчиков типа геркон

Вход для подключения датчика дальности

Система подогрева печатной платы

Вход для питания от источника постоянного тока 9-36В

Вход для программирования микроконтроллера STM32

Вход для программирования микроконтроллера ESP32

Слот для подключения micro SIM карты

Слот для подключения micro SD карты

3 светодиодных индикатора для программных задач

Индикация наличия питания 9-36В

ЭМС по ГОСТ 30804.6.1-2013

# 3 Требования к интерфейсам

SPI интерфейс для подключения Velvet ADC

1. Скорость передачи данных не менее 1кБит/с
2. Максимальная длина кабеля 10м
3. Защита от статического электричества
4. Транспортный интерфейс LVDS

# 4 Требования к цепям измерения и управления

## 4.1 Дискретные выходы:

Параметры дискретных выходов для коммутации нагрузки постоянного напряжения: напряжение нагрузки 9-36В, ток нагрузки продолжительно 10А, максимальная частота переключения 0.5Гц.

Параметры дискретных выходов для коммутации нагрузки переменного напряжения: номинальное действующее напряжение 220В, ток 2А, максимальная частота переключения 0.5Гц.

## 4.2 Дискретные входы

Логический ноль 0…4В

Логическая единица 9…24В

Диапазон питающего постоянного напряжения 9-36В.

# 5 Требования к схемотехническим решениям

Схемотехника изделия должна быть разработана согласно блок схеме на рисунке ниже.

## 4.3 Питание

Питание может осуществляться от источника постоянного напряжения 9-36В.

Вход для источника постоянного напряжения должен быть защищен от обратного включения полярности.

Наличие питания должно сопровождаться индикацией наличия напряжения 9-36В. Цвет светодиодного индикатора – зеленый.

Подключение питания должно осуществляться через винтовую клеммную колодку. Кабель в корпус должен заводиться через кабельный ввод с защитой от пыли и влаги.

Вход питания 12В должен быть защищен от помех как порт электропитания постоянного тока по ГОСТ 30804.6.1-2013.

Цепи питания контроллера должны быть изолированы от цепи питания 9-36В.

Для работы контроллера необходимо обеспечить следующие уровни напряжения: 3.3В, 4В, 5В, дополнительная изолированная цепь питания 5В.

## 4.4 Блок микроконтроллера

В качестве основного контроллера должен быть использован МК STM32F407VGT6 (далее МК1).

Для программирования МК должен использоваться интерфейс SWD. Разъём совместимый с TSW-104-07-F-D. При виде сверху сигналы на разъёме должны соответствовать приведенным на рисунке ниже:


Рисунок 1 – разъём SWD для программирования МК1

Интерфейс SWD должен быть защищен как сигнальный порт по ГОСТ 30804.6.1-2013.

На передней панели необходимо вывести светодиодные индикаторы для отображения работы загрузчика (жёлтый) и основного приложения (красный).

## 4.5 Блок WIFI

Необходимо использовать модуль ESP32-S2-MINI-1U (далее МК2).

Необходимо обеспечить индикацию для модуля светодиодным индикатором, подключенным к свободному выходу общего назначения.

МК2 должен быть снабжён коаксиальным кабелем uFL<->SMA(мама) для соединения с антенной устанавливаемой на корпус устройства.

МК1 должен иметь возможность перезагрузить МК2.

Для загрузки в память МК2 управляющей программы необходимо использовать преобразователь USB-UART с дополнительными сигналами DTR, RTS.

Предусмотреть возможность ручной установки уровней сигналов EN, IO0 МК2.

Для подключения кабеля USB необходимо установить вертикальный разъём типа Micro USB type B. Разъём представлен на рисунке ниже.


Рисунок 2 – разъём Micro USB type B

USB порт должен быть защищен как сигнальный порт по ГОСТ 30804.6.1-2013.

## 4.6 Блок GSM

Необходимо использовать модуль GSM SIM800C (далее модуль GSM).

Должна быть возможность установки SIM карты формата NANO.

SIM карта должна устанавливаться и выниматься без извлечения платы из основания корпуса.

Сигналы модуля GSM должны быть согласованы с сигналами МК1.

МК1 должен иметь возможность перезагружать модуль GSM

Подключение антенны к модулю GSM аналогично блоку WIFI.

Слот подключения SIM карты должен быть защищен как сигнальный порт по ГОСТ 30804.6.1-2013.

## 4.7 Блок управления нагрузкой

Блок управления нагрузкой используется для коммутации питания двигателей постоянного тока. Данные двигатели используются для приведения в движение насосов, перекачивающих жидкость из баков с краской и препаратом через форсунки.

Питание для насосов должно поступать на контроллер через отдельный разъём. Силовые сигналы должны быть изолированы от внутренних сигнальных цепей и цепей питания Velvet Controller.

Схема коммутации должна быть рассчитана на постоянное напряжение до 72В с током до 13А. Максимальная частота переключения 0.5Гц.

Нагрузка должна подключаться к печатной плате через винтовую клеммную колодку. Кабель в корпус должен заводиться через кабельный ввод с защитой от пыли и влаги.

В качестве нагрузки могут использоваться двигатели переменного тока. Необходимо установить 2 дополнительных независимых релейных выхода для коммутации номинального переменного напряжения 220В, ток 2А с максимальной частотой переключения 0.5Гц.

## 4.8 Блок дискретных входов

Контроллер должен иметь возможности считывать данные с 3-х цифровых датчиков:

- 2 геркона для определения наличия жидкости в ёмкостях с препаратом и краской.

- 1 датчик прерывания луча для детектирования животного в зоне действия.

Входные сигналы должны быть изолированы от внутренних сигнальных цепей и цепей питания Velvet Controller

Необходимо обеспечить питание датчиков изолированным от контроллера питанием +9-36В.

Датчики должны подключаться к печатной плате через винтовую клеммную колодку. Кабель в корпус должен заводиться через кабельный ввод с защитой от пыли и влаги.

Порты должны быть защищены от статики как сигнальные порты по ГОСТ 30804.6.1-2013.

## 4.9 Блок карты памяти

Для хранения логов и другой информации необходимо использовать съёмный накопитель информации - карту типа MicroSD.

Карта должна устанавливаться без извлечения печатной платы из основания корпуса.

Объём карты памяти до 4ГБ класс 6.

Порт для установки карты должен быть защищен от статики как сигнальный порт по ГОСТ 30804.6.1-2013.

## 4.10 Блок подключения АЦП

Блок подключения АЦП должен обеспечивать связь по кабелю длиной до 10м.0

Блок должен обеспечивать питание АЦП номинальным напряжением 12В.

В качестве микросхемы АЦП в Velvet ADC используется микросхема AD7797BRUZ управляемая по SPI интерфейсу. Сигналы АЦП передаются в виде дифференциальных сигналов.

Вместе с сигнальными жилами через кабель должно передаваться изолированное питание для Velvet ADC

Кабель заводится в корпус через кабельный ввод, защищенный от влаги и пыли. Кабель подключается к печатной плате через винтовую клеммную колодку.

Интерфейс должен быть защищен как сигнальный порт по ГОСТ 30804.6.1-2013.

При реализации транспортного интерфейса рекомендуется следовать следующему руководству: Extending the SPI bus for long-distance communication (https://www.ti.com/lit/an/slyt441/slyt441.pdf) (Texas Instruments)

## 4.11 Блок климат контроля

Для обеспечения рабочего режима температуры модуля RFID требуется добавить систему климат контроля внутри корпуса.

Для измерения температуры должен использоваться цифровой датчик с максимальной погрешностью измерения ±1⁰С.

Микроконтроллер должен иметь возможность сбрасывать работу датчика температуры.

Для обогрева воздуха используется нагреватель, устанавливаемый на печатной плате

## 4.12 Блок LoRa

Блок LoRa построен на базе модуля RAK3172. Блок должен управляться при помощи UART интерфейса МК1. МК1 должен иметь возможность сбрасывать работу модуля LoRa.

Необходима возможность переключения уровней напряжения сигнала BOOT модуля RAK3172

Подключение антенны к модулю аналогично блоку WIFI.

## 4.13 Блок RFID

В основе блока RFID должен быть использован модуль CF-MU904 (868MHz).

Для подведения радиочастотного сигнала от корпуса к модулю должен использоваться коаксиальный кабель с разъёмами MCX(папа)<->N-type(папа).

Сигналы модуля RFID должны быть согласованы с сигналами МК1

МК1 должен иметь возможность сбрасывать работу модуля.

МК1 должен иметь возможность задействовать дополнительные входы и выходы общего назначения модуля (GPI, GPO).

# 6 Требования к конструктиву

В качестве корпуса устройства требуется использовать корпус Gainta G373. Чертеж и общий вид представлены на рисунке ниже.

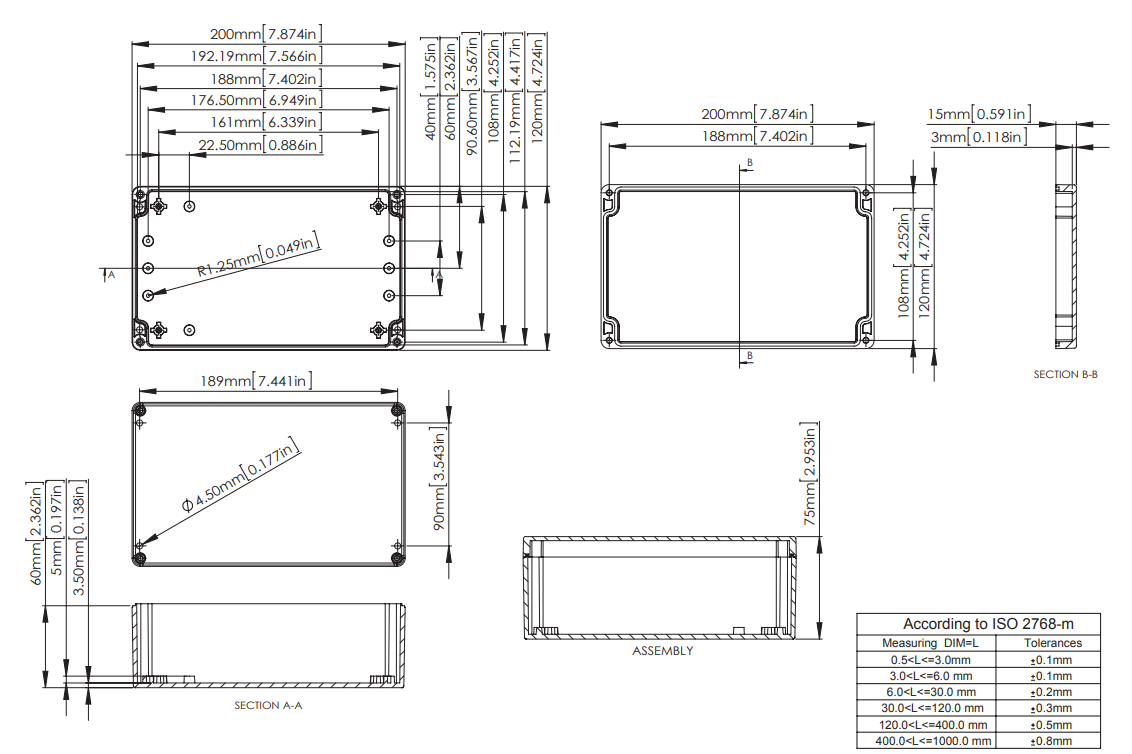
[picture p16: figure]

Рисунок 3 – корпус Velvet Controller Gainta G373

Печатная плата должна крепиться к основанию корпуса с использованием предусмотренных в корпусе углублений для шурупов.

Velvet controller должен включать себя одну печатную плату.

Для подключения источников к цифровым дискретным входам, датчиков температуры и АЦП рекомендовано использовать клеммные колодки с подпружиненными контактами типа KF141V.

Для подключения питания и потребителей к дискретным выходам рекомендовано использовать клеммные колодки типа KF142V.

Требования к печатной плате:

1. Класс точности не выше 4
2. Толщина ПП 1.6мм
3. Количество слоёв не больше 4
4. Печатные платы, геометрия контактных площадок, а также взаимное расположение КП относительно друг друга должно быть оптимизировано под автоматический монтаж
5. Компоненты размещать на верхней стороне ПП, при необходимости возможно размещение компонентов, монтируемых автоматически на одной из сторон, а монтируемых вручную - на верхней или обеих сторонах. Допускается так же монтаж SMD компонентов на обеих сторонах ПП при условии примерно равного по плотности размещения компонентов на каждой из сторон ПП
6. Свободные от сигнальных цепей площади ПП на нижней стороне должны быть залиты полигоном, подключенным к заземляющей клемме внешнего питания модуля (PE)Для подключения цифровых
7. На лицевой стороне печатной платы необходимо разместить изображение герба КазАТУ им.С.Сейфуллина.

# 7 Требования к проектированию и сдаче проекта заказчику

1. 3 действующих, отлаженных образца изделия.
2. Комплект конструкторской документации состоящий из:
3. Схема электрическая принципиальная Э3 (Altium schdoc)
4. Проект страссированной ПП (Altium pcbdoc)
5. Перечень элементов ПЭ3 (MS Word)

# 8 ЛИСТ РЕГИСТРАЦИИ ИЗМЕНЕНИЙ

№ п/п | Пункт и вносимое изменение | Ф.И.О. внесшего изменения | Подп. | Дата
1 | Инициация | Байгуаныш С.Б. | | 16.01.2023

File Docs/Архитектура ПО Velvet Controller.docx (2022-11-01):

# 1 Общие сведения

Для реализации автоматизированной системы взвешивания крупного рогатого скота Velvet Controller (далее Velvet) необходимо выполнить ряд требований:

- идентифицировать КРС при помощи RFID меток;
- измерять вес КРС при помощи дополнительного аппаратного модуля АЦП Velvet ADC;
- Опрыскивание КРС медицинскими препаратами.
- Опрыскивание КРС краской.
- Взаимодействие с сервером посредством Wi-Fi.
- Взаимодействие с сервером посредством LoRa.
- Взаимодействие с сервером посредством GSM.
- Управление подогревом устройства.

В требованиях к устройству нет пунктов, относящихся к обеспечению функциональной безопасности.

Программа для МК относится к встраиваемому программному обеспечению

Перед ознакомлением с данным документом рекомендуется изучить Техническое задание, Технический проект, электрические принципиальные схемы

# 2 Область применения

Данный документ определяет архитектуру встраиваемого программного обеспечения для МК, установленного в плате Velvet Controller, для исключения ошибок проектирования программного обеспечения, которые могут вызвать систематические отказы. Разработка данного документа упростит написание последующих документов, ускорит процесс разработки и поддержки программного обеспечения для МК.

# 3 Термины, определения и сокращения

Встраиваемое программное обеспечение - программное обеспечение, непосредственно реализующее функции управления устройством железнодорожной автоматики и телемеханики, как правило, записанное в энергонезависимое ПЗУ устройства и заменяемое с помощью специальных программно-аппаратных средств.

БПР – бесконтактное поляризованное реле;

ОЗУ/RAM – оперативное запоминающее устройство;

ПЗУ – постоянное запоминающее устройство;

ПО – программное обеспечение;

МК - микроконтроллер;

ТЗ – техническое задание.

# 4 Ссылочные нормативные документы

# 1 Аппаратные средства

Программное обеспечение предназначено для микроконтроллера STM32F407 фирмы ST Microelectronics. Это 32-ух битный микроконтроллер, с напряжениями питания от 1,8 В до 3.6 В, с флэш-памятью программ в 1МБ, модулями таймера, компаратора и др. Для подробного ознакомления с микроконтроллером рекомендуется изучить документ «STM32F405xx STM32F407xx Datasheet».

Взаимодействие с компонентами платы производится через порты ввода-вывода. Максимальный вытекающий ток – 25 мА.

Для программирования МК используется интерфейс SWDIO.

# 2 Внешние интерфейсы

ПО взаимодействует со следующими аппаратными интерфейсами и периферийными модулями МК: цифровой ввод-вывод с входным буфером на триггере Шмитта, таймер, UART. Также ПО взаимодействует со следующими элементами схемы Velvet Controller, подключенными к пинам МК: контакты реле (управление транзисторами через драйверы), светодиодная индикация, Wifi модуль ESP32-S2-MINI-1U, GSM модуль SIM800C, LoraWAN модуль RAK3172, RFID модуль CF-MU904.

Цифровой вывод используется для управления транзисторами выходных контактов и светодиодной индикацией, управления сбросом внешних модулей.

# 5 Логическая структура

## 1.1 Части программного обеспечения и их взаимосвязь

Проект состоит из основоного си-файла и нескольких библиотек. Основной Си-файл называется «main.c».

Непосредственно к main.c подключаются библиотеки weight (считывание веса), spray (управление опрыскивателем), climate (климат контроль), net (взаимодействие с сетью), rfid (считывание RFID меток).

Кроме полностью программных библиотек присутствуют библиотеки для работы с аппартной частью: adc (АЦП), gpio (порты ввода вывода), uart (последовательные порты).

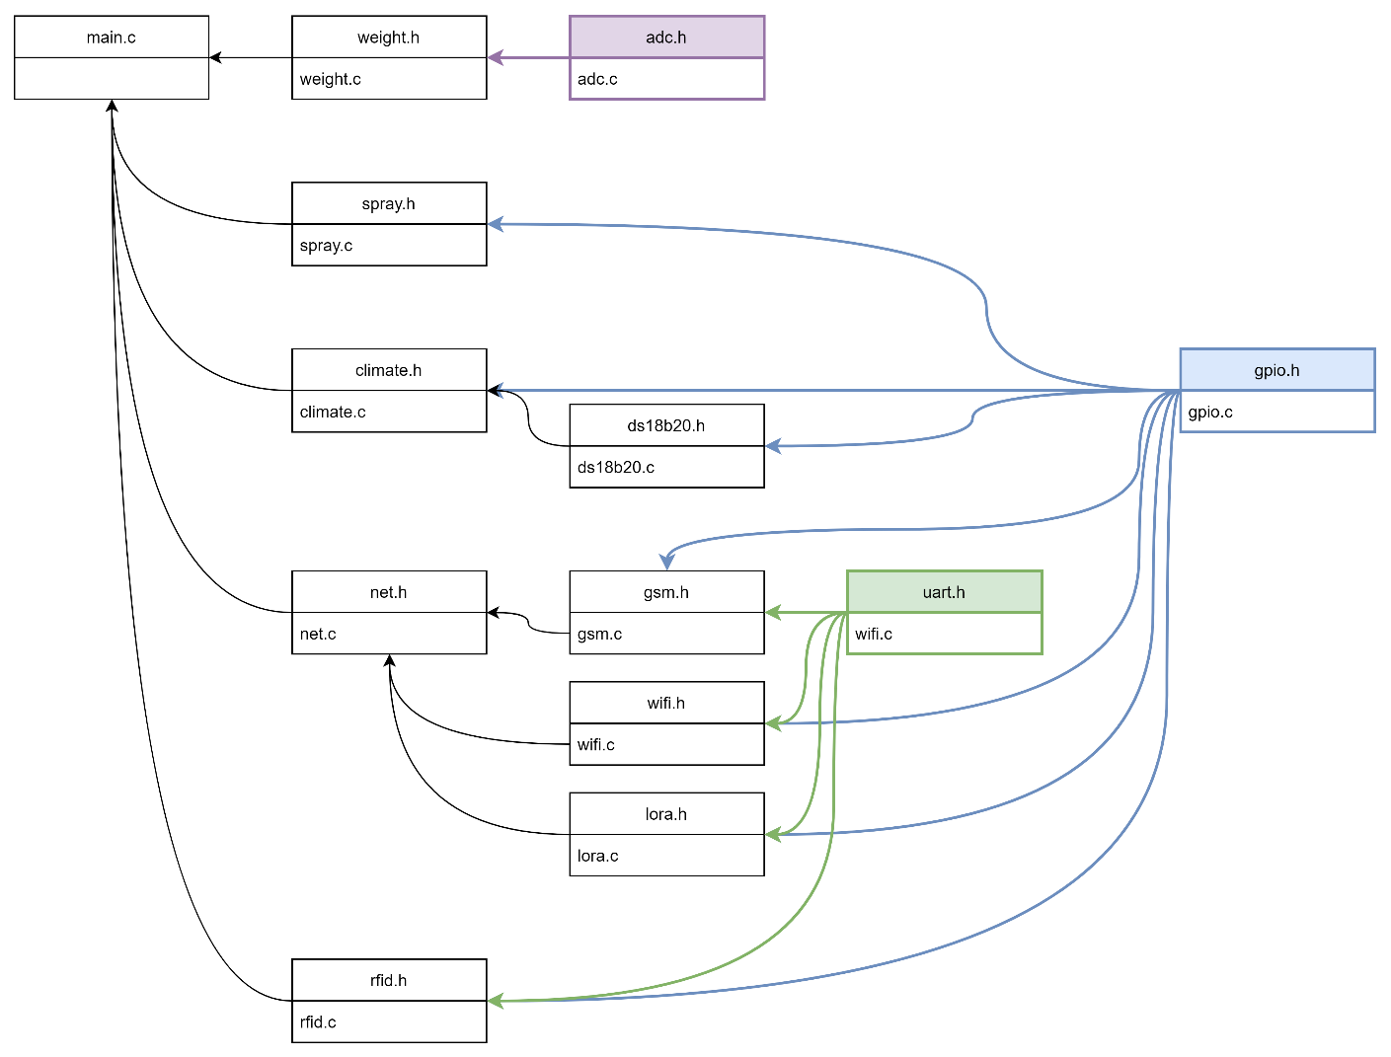
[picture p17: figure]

Рисунок 1 – части ПО Velvet Controller

Общий алгоритм работы программы реализован в функции main.

Алгоритм функции main приведен на рисунке ниже:

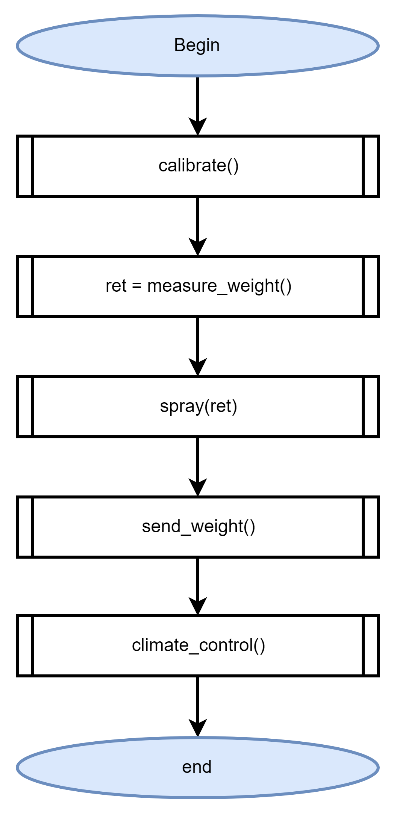
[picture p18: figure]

Рисунок 2 – алгоритм функции main

В функции main вызывается несколько библиотечных функций.

Функция measure_weight() – функция для получения веса. Алгоритм приведен ниже:

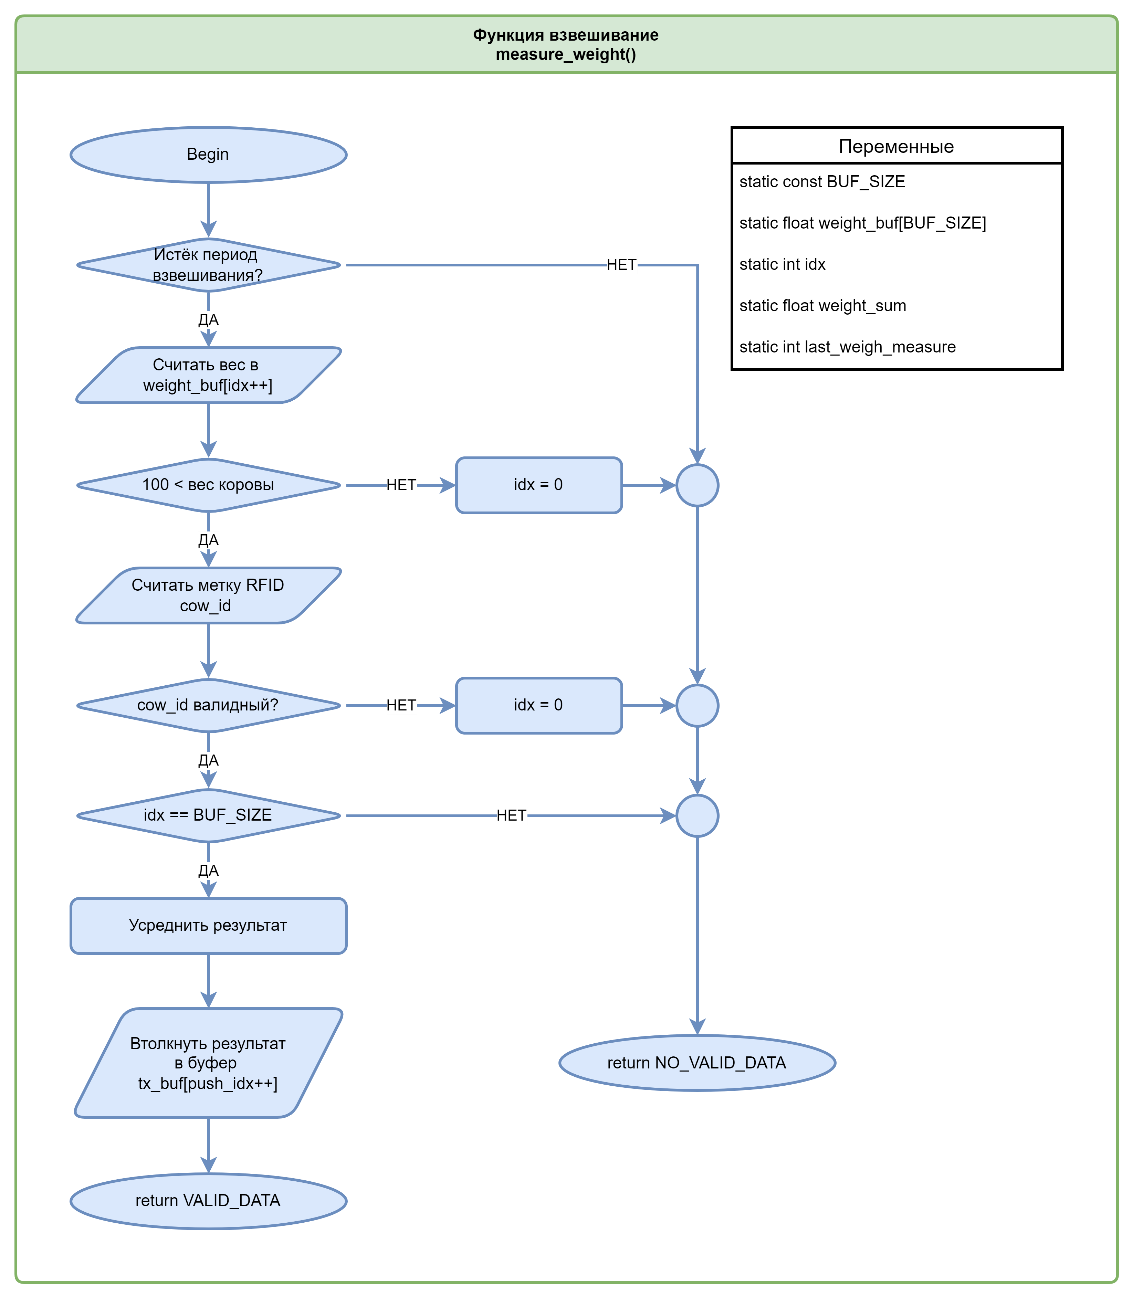
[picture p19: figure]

Рисунок 3 – алгоритм функции взвешивания measure_weight()

Функция spray() – функция для осуществления опрыскивания. Алгоритм приведен ниже:

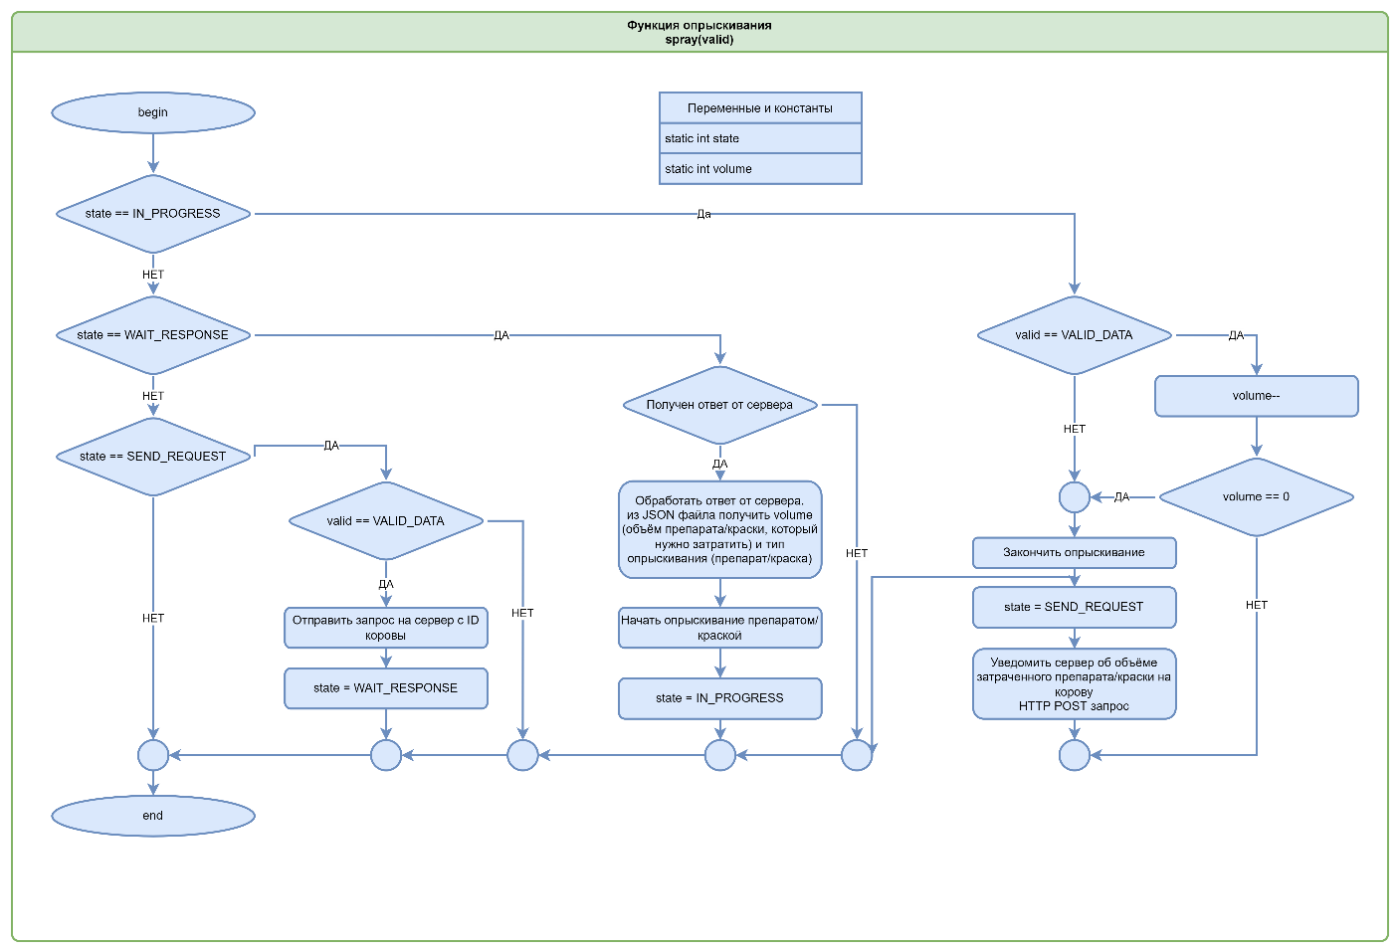
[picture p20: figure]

Рисунок 4 – алгоритм функции опрыскивания spray()

Функция climate_control() – управляет климатическими параметрами. Алгоритм climate_control() приведен ниже:

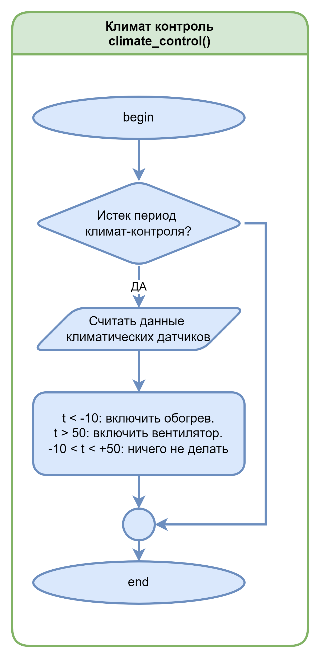
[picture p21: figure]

Рисунок 5 – Алгоритм функции climate_control()

Функция send_weight() – функция для отправки веса на сервер. Алгоритм функции представлен на рисунке ниже:

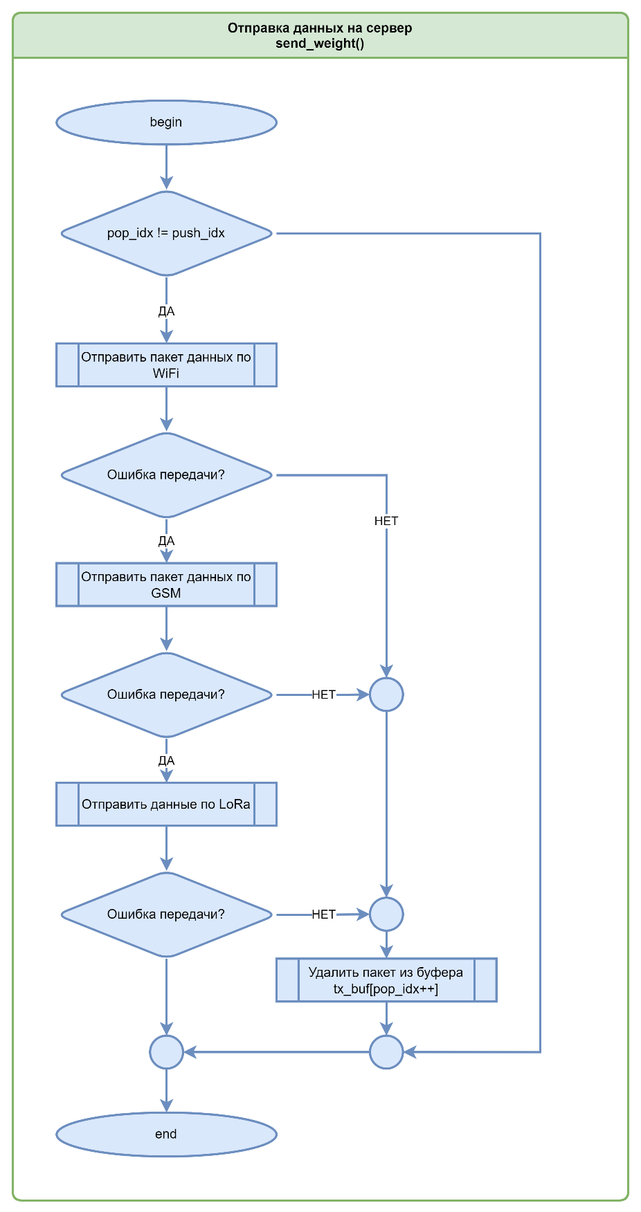
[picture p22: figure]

Рисунок 6 – алгоритм функции send_weight()

# Лист регистрации изменений

№ п/п | Пункт и вносимое изменение | Ф.И.О. внесшего изменения | Подп. | Дата
1 | Инициация | Байгуаныш С.Б. | | 04.10.2022

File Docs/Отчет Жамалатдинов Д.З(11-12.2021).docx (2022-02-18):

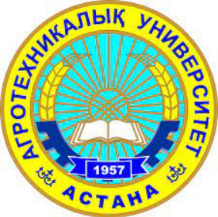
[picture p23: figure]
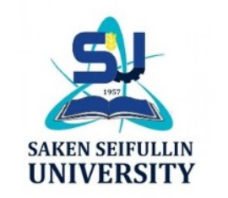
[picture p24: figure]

Казахский агротехнический университет

имени С.Сейфуллина “КАТУ”

Краткий отчет о текущей работе по проекту

Поставленные задачи:

1. Произвести анализ рынка и осуществить подбор аккумуляторных батарей для носимого трекера.
2. Разработка крепежных элементов, монтаж оборудования в имеющиеся корпуса, для сборки старой версии контроллера.
3. Разработка переходной платы между платой Arduino Uno и платой-модулем HX711 для подключения весов.
4. Разработка и печать герметичного корпуса для платы Arduino Uno с установленной на нее платой-модулем HX711.
5. Подготовка посадочных мест для всех компонентов принципиальных схем главной платы контроллера безстрессового взвешивания.

Результаты выполненных работ:

1. Произведен подбор аккумуляторных батарей разных типов и было выбрано несколько экземпляров для дальнейшего закупа и тестирования.
2. Были разработаны крепежные элементы, посредством их произведен монтаж компонентов в корпуса. 3D вид сборки показан на рисунке 1.

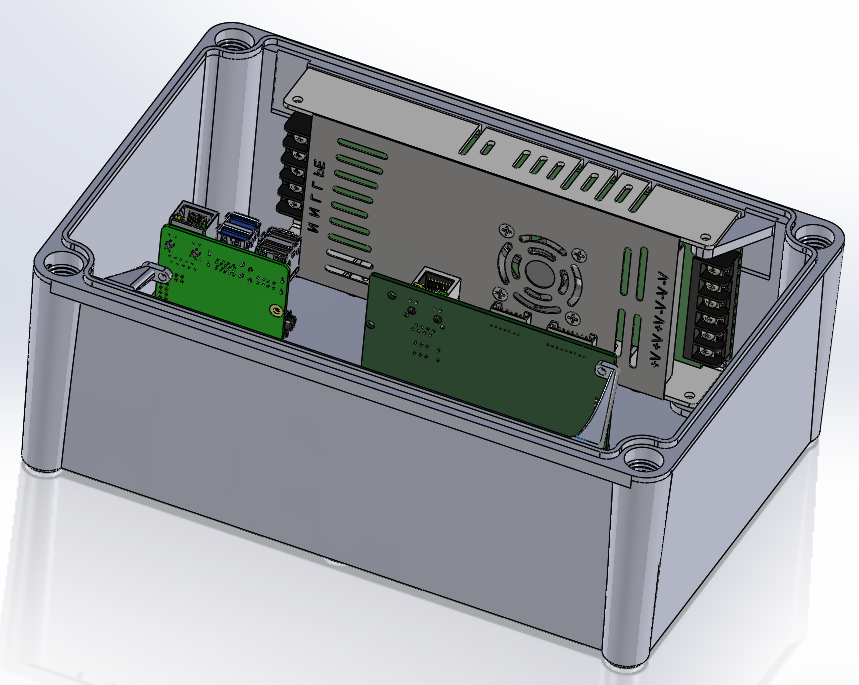
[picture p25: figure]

Рисунок 1 – 3D вид сборки контроллера старой версии

Фотография собранного контроллера показана на рисунке 2.


Рисунок 2 – собранный контроллер старой версии

3. Была разработана переходная плата, показана на рисунке 3.


Рисунок 3 – 3D вид переходной платы

4. Разработан и распечатан герметичный корпус для платы Arduino Uno и переходной платы. Общий вид в сборе показан на рисунке 4.


Рисунок 4 – 3D вид герметичного корпуса для плат Arduino Uno и HX711.

5. В настоящий момент ведутся работы по поиску, рисовке, формированию библиотеки с посадочными местами для компонентов принципиальной схемы контроллера безстрессового взвешивания, с целью их дальнейшего применения при разработке платы. По мере работы также перерисовываются принципиальные схемы с целью приближения к стандартам ГОСТ, а также однообразия изображений компонентов на схемах.

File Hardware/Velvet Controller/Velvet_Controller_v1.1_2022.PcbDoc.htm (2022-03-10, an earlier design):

Reporting Options

# File in Newer Format

Date | : | 09.03.2022
Time | : | 23:46:52
Filename | : | E:\User Data\Desktop\PROJECTS\Velvet_Controller_v1.1_2022 (09.03.2022 23-31-21)\Velvet_Controller_v1.1_2022.PcbDoc

Version | Warning
Release 17.1 | CAUTION - Support of waived violations
Release 17.1 | CAUTION - Support of object specific keepouts
Release 20.0 | CAUTION - Support of propagation delay for primitives

This file was generated by a later version of the software

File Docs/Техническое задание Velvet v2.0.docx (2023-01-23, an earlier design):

СОДЕРЖАНИЕ

# 1 НАИМЕНОВАНИЕ, ОСНОВАНИЕ, РАЗРАБОТЧИК И СРОК РАЗРАБОТКИ

1.1 Контроллер автоматизированной системы взвешивания крупного рогатого скота Velvet Controller (Далее по тексту «Velvet Contorller»).
1.2 Принятые сокращения:

АПК –аппаратно-программный комплекс;

МК – микроконтроллер;

КРС – крупный рогатый скот

АЦП – аналогово-цифровой преобразователь

# 2 ЦЕЛЬ РАЗРАБОТКИ, НАИМЕНОВАНИЕ И ОБЛАСТЬПРИМЕНЕНИЯ

2.1 Цель разработки: автоматизированный сбор данных о массе и управление опрыскивателем.
2.2 Полное наименование разработки – «Контроллер автоматизированной системы взвешивания крупного рогатого скота Velvet Controller» (далее по тексту «Velvet Controller»).
2.3 Velvet Contoller предназначен для считывания данных о весе КРС с АЦП «Velvet ADC».
2.4 Областью применения Velvet Controller являются автоматические весы и кормушки, оснащенные тензометрическими датчиками на животноводческих фермах.

# 3 ТЕХНИЧЕСКИЕ ТРЕБОВАНИЯ

# 3.1 Состав изделия

3.1.1 В состав Velvet Controller в общем случае должны входить:

- Плата Velvet Controller;

- Корпус Velvet Controller;

- Паспорт Velvet Controller.

3.1.2 Наличие в составе документации определяется договором поставки.

# 3.2 Требования назначения

3.2.1 Velvet Controller должен быть разработан для автоматических весов и кормушек оснащенных тензометрическими датчиками.
3.2.2 Velvet Controller должен включать:

а) Блок микроконтроллера (БМК) – предназначенный для работы часов реального времени; связи с внешними устройствами по протоколу WiFi, Lora, GSM, RFID;

б) Блок ввода-вывода (БВВ) – предназначен для подключения внешних устройств ввода вывода.

В) Блок съёмного носителя информации (БВН) – предназначен для хранения информации

в) Блок подключения к АЦП (БПАЦП) – предназначен для подключения «Velvet ADC»;

г) Блок управления питанием (БУП) – предназначенный для обеспечения питанием всех блоков Velvet Controller;

3.2.3 Упрощенная структурная схема Mary приведена в приложении А.

# 3.3 Требования к функциональной совместимости

3.3.1 Velvet Controller должен быть совместим с «Velvet ADC».
3.3.2 Корпус Velvet Controller должен иметь крепления совместимые c существующими автоматическими весами и кормушкой, для возможности монтажа в них.
3.3.3 Velvet Controller должен иметь выведенный на корпус разъём питания переменного тока 220В±10%.
3.3.4 Velvet Controller должен иметь возможность считывать RFID метки в частотном диапазоне 902~928МГц.
3.3.5 Velvet Controller должен иметь возможность считывать данные с АЦП «Velvet ADC».
3.3.6 Velvet Controller должен иметь возможность считывать данные с датчика типа «Геркон» для определения наличия жидкости в ёмкости в количестве 2 штук.
3.3.7 Velvet Controller должен иметь возможность управлять нагрузкой постоянного тока 24В 10А количестве 2 штук.
3.3.8 Velvet Controller должен иметь возможность считывать данные с датчика разрыва луча для детектирования появления КРС в зоне действия антенны RFID
3.3.9 Velvet Controller должен иметь индикатор на корпусе для отображения наличия питания.
3.3.10 Velvet Controller должен иметь индикатор работы модуля WiFi
3.3.11 Velvet Controller должен иметь индикатор для отображения работы загрузчика. При попадании в загрузчик индикатор должен включаться. При выходе из загрузчика выключаться.
3.3.12 Velvet Controller должен иметь индикатор для отображения работы основной программы. Индикатор будет использоваться программистом для отладки.
3.3.13 Velvet Controller должен хранить уникальный идентификационный номер (далее ID) и данные по беспроводному каналу должны сопровождаться c указанием ID и текущего времени.
3.3.14 Радиообмен сигналами может происходить в открытом виде.
3.3.15 На корпусе Velvet Controller должна быть скрытая кнопка принудительной перезагрузки.

# 3.4 Требования стойкости к внешним воздействиям

3.4.1 По воздействию климатических факторов при эксплуатации Velvet Controller, должен относиться к классу, в соответствии с Таблицей 1, и быть устойчивым к воздействию климатических факторов в соответствии с ГОСТ 15150-69.

Таблица 1 – Классификация оборудования по климатическим факторам

Наименование оборудования | Климатическое исполнение по ГОСТ 15150 | Виды и нормы воздействий климатических факторов
| | Верхнее значение рабочей температуры, С | Верхнее значение предельной рабочей температуры, С | Нижнее значение рабочей температуры, С | Нижнее значение предельной рабочей температуры, С | Характер изменения температуры предельной рабочей | Верхнее значение относительной влажности воздуха, % при температуре 25°С
Velvet Controller | У1.1 | 45 | 45 | Минус 40 | Минус 45 | Постепенное | 100%

3.4.2 Mary должен быть устойчивым к воздействию механических нагрузок в соответствии с таблицей 2.

Таблица 2 – Классификация оборудования по механическим факторам

Наименование оборудования | Диапазон частот, Гц | Виды и нормы воздействий механических факторов
| | Вибрация
| | Амплитудное значение ускорения, м/с, в направлении воздействия
| | Вертикальном | Горизонтальном
Velvet Controller | 1-55 | 2 | 2

3.4.3 Степень защиты, обеспечиваемая корпусом, по ГОСТ 14254– не менее IP54.
3.4.4 Mary должен быть стойким к воздействию электромагнитных помех с критерием функционирования «B» и соответствовать ГОСТ 30804.6.1.

# 3.5 Требования надежности, готовности и ремонтопригодности

3.5.1 Средняя наработка Velvet Controller (включая ПО) на отказ не менее 720ч (1 месяц) непрерывной работы.
3.5.2 Velvet Controller должен функционировать в непрерывном длительном режиме.
3.5.3 Средний срок службы до списания не менее 5 лет.
3.5.4 Среднее время восстановления работоспособного состояния не более 40 мин.

# 3.6 Требования безопасности

# 3.6.1 Требования к электробезопасности

3.6.1.1 По электробезопасности оборудование Velvet Controller должен относиться к II классу по ГОСТ МЭК 61140.
3.6.1.2 Электрическая изоляция электрических цепей Velvet Controller должна соответствовать требованиям ГОСТ Р МЭК 60664.1-2012.
3.6.1.3 Velvet Controller должен эксплуатироваться в соответствии с «Правилами техники безопасности при эксплуатации электроустановок потребителем».

# 3.6.2 Требования к функциональной безопасности

3.6.2.1 Требования к функциональной безопасности не предъявляются.

# 3.6.3 Требования к пожарной безопасности

3.6.3.1 Применяемые материалы должны быть трудногорючими по ГОСТ 12.1.044.
3.6.3.2 Уровень обеспечения пожарной безопасности людей в соответствии с п.1.2 ГОСТ 12.1.004.

# 3.7 Требования эргономики и технической эстетики

    3.7.1 Эргономика и техническая эстетика Velvet Controller должна соответствовать ГОСТ 20.39.108.
    3.7.2 Velvet Controller должен работать в полностью автоматическом режиме. Обслуживающий персонал должен участвовать только в устранении неисправностей и отказов.
    3.7.3 Конструкция Velvet Controller должна обеспечивать удобный монтаж.
    3.7.4 Устройства визуального контроля должны обеспечивать четкое и однозначное восприятие информации обслуживающим персоналом.
    3.7.5 Надписи должны иметь хорошо читаемые символы и быть контрастными.
    3.7.6 Металлические детали должны иметь защитные антикоррозионные покрытия (за исключением деталей, выполняющих функцию теплоотвода).
    3.7.7 Металлические детали, не имеющие гальванических покрытий, должны иметь лакокрасочные покрытия.
    3.7.8 На плате должен быть размещен герб КазАТУ им. С.Сейфуллина.

# 3.8 Требования к эксплуатации, хранению, удобству технического обслуживания и ремонта

# 3.8.1 Требования к условиям эксплуатации

  3.8.1.1 Технически Velvet Controller должен быть реализован без использования оборудования, требующего регулярной периодической замены.
  3.8.1.2 Окружающая среда не взрывоопасная.
  3.8.1.3 Гарантийный срок эксплуатации Mary должен быть не менее 1 года.
  3.8.1.4 Требуется описать процесс калибровки для достижения заявленных ТТХ.

# 3.8.2 Требования к хранению

  3.8.2.1 Условия хранения должны соответствовать в части воздействия климатических факторов «5» (ОЖ4) по ГОСТ 15150.
  3.8.2.2 Гарантийный срок хранения 1 год.

# 3.8.3 Требования к техническому обслуживанию

  3.8.3.1 БМК должен иметь собственные часы реального времени.

# 3.8.4 Требование к ремонтопригодности

  3.8.4.1 На месте эксплуатации Velvet Controller должен восстанавливаться путем замены на новый.
  3.8.4.2 В Velvet Controller должна быть исключена возможность разъединения при воздействии внешних факторов и (или) возможность неправильного соединения с периферийными устройствами.

# 3.9 Требования транспортабельности

3.9.1 Условия транспортирования должны соответствовать в части воздействия:

- механических факторов – группе «Ж» по ГОСТ 23216;

- климатических факторов – группе «5» (ОЖ4) по ГОСТ 15150.

# 3.10 Требования безопасности и охраны здоровья

  3.10.1 Общие требования безопасности должны соответствовать ГОСТ 12.2.007.0.
  3.10.2 При производстве должны выполняться требования техники безопасности по ГОСТ 12.3.008.
  3.10.3 Обеспечение специальной защитной одеждой, средствами индивидуальной защиты ног (специальная обувь) и другими предохранительными средствами согласно требованиям ГОСТ 12.4.011 и ГОСТ 12.4.103.
  3.10.4 Санитарно-гигиенические требования рабочей зоны должны соответствовать ГОСТ 12.1.005.
  3.10.5 Общие требования пожарной безопасности в производственных помещениях должны соответствовать Техническому регламенту «Общие требования к пожарной безопасности» и ГОСТ 12.1.004.

# 3.11 Требования стандартизации, унификации и каталогизации

  3.11.1 Комплектующие изделия Velvet Controller должны быть серийно производимые.
  3.11.2 Должна быть разработана карта замены, допускающая замену элементов одной серии или производителя на изделия другой серии или производителя.

# 3.12 Требования технологичности

  3.12.1 Обеспечить технологичность Velvet Conroller в соответствии с ГОСТ 14.201.
  3.12.2 Монтаж Velvet Controller должен производиться в соответствии с разработанным технологическим процессом на сборку МИ.

# 3.13 Конструктивные требования

  3.13.1 Конструкция Velvet Controller должна обеспечивать:

- удобство осуществления монтажа изделия;

- индикацию работоспособности в процессе эксплуатации.

- Масса Velvet Controller не должна превышать 3кг.

# 3.14 Требования охраны окружающей среды

  3.14.1 Контроль вредных выбросов при производстве Velvet Controller должен производиться по ГОСТ 17.2.3.02.
  3.14.2 ПДК загрязняющих веществ в атмосферном воздухе должно быть в соответствии с ГН 2.1.6.1338-03.

# 3.15 Требования к утилизации

  3.15.1 Перед утилизацией производится разукомплектование и демонтаж комплектующих изделий в соответствии с ведомостью оценки и технического состояния, представляемой вместе с актом на списание.
  3.15.2 После снятия с эксплуатации, изделия не представляют опасности для жизни, здоровья людей и окружающей среды.
  3.15.3 Утилизация по ГОСТ Р 53692.

# 4 ТЕХНИКО-ЭКОНОМИЧЕСКИЕ ТРЕБОВАНИЯ

4.1 Себестоимость Velvet Controller не должна превышать 50000тг.
4.2 Предполагаемый объем выпуска не менее 50шт.

# 5 ТРЕБОВАНИЯ К ВИДАМ ОБЕСПЕЧЕНИЯ

# 5.1 Требования к метрологическому обеспечению

  5.1.1 В качестве средств измерений и контроля параметров при проверке должны использоваться средства измерений и контроля общего применения.
  5.1.2 Должен быть разработан перечень средств измерений и контроля.
  5.1.3 Годность указанных средств должна быть подтверждена сопроводительными документами или клеймами, и они должны быть аттестованы или поверены в установленном порядке.

# 5.2 Требования к диагностическому обеспечению

  5.2.1 Velvet Controller должен иметь беспроводной интерфейс WiFi, GSM, Lora, RFID
  5.2.2 Данные о весе КРС или весе корма должны отправляться с периодичностью не более 1с.
  5.2.3 Velvet Controller должен иметь возможность отправлять всю необходимую диагностическую информацию в центральную систему мониторинга.

# 5.3 Требования к нормативно-техническому обеспечению

  5.3.1 На Velvet Controller должна быть разработана следующая документация:

- принципиальные схемы;

- монтажные схемы;

- руководство по эксплуатации;

- чертежи и схемы установки и монтажа;

- сводная ведомость;

- методика испытаний;

- программная документация.

  5.3.2 Документация должна быть выполнена на русском языке.

# 5.4 Требования к математическому, программному и информационно-лингвистическому обеспечению

  5.4.1 Для БМК в составе Velvet Controller необходимо разработать встраиваемое программное обеспечение.
  5.4.2 Программное обеспечение БМК в составе Velvet Controller должно соответствовать ГОСТ Р 51904.
  5.4.3 К встраиваемому программному обеспечению предъявляются следующие требования:

- цикл разработки и документирование ПО должен осуществляться по ГОСТ Р 51904;

- должны быть произведены испытания программного обеспечения.

  5.4.4 Вся представляемая и выводимая информация должна быть на русском языке.

# 6 ТРЕБОВАНИЯ К СЫРЬЮ, МАТЕРИАЛАМ И КОМПЛЕКТУЮЩИМ ИЗДЕЛИЯМ

6.1 Применяемые комплектующие изделия и материалы должны быть допущены к применению на территории стран Таможенного союза.
6.2 Подлежащие обязательной сертификации комплектующие изделия и материалы должны иметь действующие на территории стран Таможенного союза сертификаты.

# 7 ТРЕБОВАНИЯ К МАРКИРОВКЕ И УПАКОВКЕ

7.1 Маркировка и упаковка Velvet Controller должна соответствовать ТР ТС 003/2011.
7.2 На внешней стороне Velvet Controller должна быть наклеена самоклеящаяся этикетка, в которой на государственном и русском языках должны быть указаны:

- наименование Velvet Controller;

- наименование и (или) товарный знак предприятия-изготовителя;

- класс защиты от поражения электрическим током;

- заводской номер Velvet Controller;

- дата изготовления (месяц и год изготовления);

- надпись «Сделано в Республике Казахстан».

7.3 Маркировка должна быть разборчивой, легко читаемой.
7.4 Маркировка не должна осыпаться, расплываться и выцветать в течение всего срока эксплуатации.
7.5 Транспортная маркировка должна соответствовать ГОСТ 14192.
7.6 На упаковку должна быть наклеена самоклеящаяся этикетка, на которой на государственном и русском языках должны быть указаны:

- наименование Velvet Controller;

- товарный знак предприятия-изготовителя;

- наименование предприятия-изготовителя;

- юридический адрес предприятия-изготовителя;

- обозначение нормативного документа, в соответствии с которым произведен Velvet Controller;

- заводской номер Velvet Controller;

- дата изготовления (месяц и год изготовления);

- масса брутто/нетто в килограммах;

- надпись «Сделано в Республике Казахстан».

7.7 Упаковка должна обеспечивать сохранность при транспортировке и хранении. Упаковку разработать в соответствии с ГОСТ 23216 и требованиями п.3.9 настоящего технического задания.

# 8 ТРЕБОВАНИЯ К СРЕДСТВАМ ОБУЧЕНИЯ

8.1 Так как сборка будет осуществляться силами сотрудников проекта, технологический процесс на сборку не требуется
8.2 Для обучения персонала эксплуатирующей организации должна быть разработана презентация.

# 9 СПЕЦИАЛЬНЫЕ ТРЕБОВАНИЯ

# 9.1 Требования к патентной чистоте и патентоспособности

9.1.1 Требования к патентной чистоте в отношении Velvet Controller не предъявляются.

# 9.2 Требования разработки средств обеспечения испытаний изделия

9.2.1 Проверка работоспособности Velvet Controller будет производиться в полевых условиях после установки на автоматические весы

# 9.3 Требования к сертификации и декларированию

9.3.1 Требований к сертификации и декларированию изделия не предъявляется.

# 10 ЭТАПЫ ВЫПОЛНЕНИЯ РАЗРАБОТКИ

10.1 Этапы разработки согласно ГОСТ Р 15.301-2016.
10.2 Должно быть изготовлено 5 образцов Velvet Controller для проведения испытаний.
10.3 Необходимо определить место проведения эксплуатационных испытаний.
10.4 Необходимо разработать эксплуатационную документацию.
10.5 После установки и проведения полевых испытаний процесс разработки считается завершенным.

# 11 ПОРЯДОК ВЫПОЛНЕНИЯ И ПРИЕМКИ ЭТАПОВ РАЗРАБОТКИ

11.1 Порядок разработки согласно ГОСТ Р 15.301-2016.
11.2 Изготовленный образец должен пройти эксплуатационные испытания.
11.3 Разрабатываемая документация должна быть выполнена в соответствии с требованиями стандартов Единой системы конструкторской документации.
11.4 Порядок выполнения согласно таблице 3.

Таблица 3 – Порядок выполнения этапов разработки

№ | Наименование | Код
| Реестр документов | VELVETCTR4.000ДР
| Техническое задание | VELVETCTR.001ТЗ
| Технический проект | VELVETCTR.005ТП
| Электрическая принципиальная схема | VELVETCTR.006Э3
| Монтажная схема | VELVETCTR.040Э4
| Схема подключения | VELVETCTR.042Э5
| Сборочный чертеж | VELVETCTR.043СБ
| Паспорт | VELVETCTR.016ПС

# 12 ПРЕДПОЛАГАЕМЫЙ РАЗРАБОТЧИК И ПОЛИГОН ВНЕДРЕНИЯ ПРОДУКЦИИ

12.1 Разработчик Velvet Controller – АО «КАТУ им. С.Сейфуллина
12.2 Полигон внедрения –

# ПРИЛОЖЕНИЕ А. Упрощенная структурная схема Mary


Рисунок А1 - Упрощенная структурная схема Velvet Controller

# ПРИЛОЖЕНИЕБ. Список использованной нормативной документации

1 При разработке настоящего технического задания учитывались требования следующих документов:

- ГОСТ 12.1.004-91 «Система стандартов безопасности труда. Пожарная безопасность. Общие требования»;

- ГОСТ 12.1.005-88 «Система стандартов безопасности труда. Общие санитарно-гигиенические требования к воздуху рабочей зоны»;

- ГОСТ 12.1.044-2018 «Система стандартов безопасности труда. Пожаровзрывоопасность веществ и материалов. Номенклатура показателей и методы их определения»;

- ГОСТ 12.2.007.0-75 «Система стандартов безопасности труда. Изделия электротехнические. Общие требования безопасности»;

- ГОСТ 12.3.008-75 «Система стандартов безопасности труда. Производство покрытий металлических и неметаллических неорганических. Общие требования безопасности»;

- ГОСТ 12.4.011-89 «Система стандартов безопасности труда. Средства защиты работающих. Общие требования и классификация»;

- ГОСТ 12.4.103-83 «Система стандартов безопасности труда. Одежда специальная защитная, средства индивидуальной защиты ног и рук. Классификация»;

- ГОСТ 14.201-83 «Обеспечение технологичности конструкций изделий. Общие требования»;

- ГОСТ 15.012-84 «Система разработки и постановки продукции на производство. Патентный формуляр»;

- ГОСТ 17.2.3.02-2014 «Правила установления допустимых выбросов загрязняющих веществ промышленными предприятиями»;

- ГОСТ 20.39.108-85 «Комплексная система общих технических требований. Требования по эргономике, обитаемости и технической эстетике. Номенклатура и порядок выбора»;

- ГОСТ 14192-96 «Маркировка грузов»;

- ГОСТ 14254-2015 «Степени защиты, обеспечиваемые оболочками (Код IP)».

- ГОСТ 15150-69 «Машины, приборы и другие технические изделия. Исполнения для различных климатических районов. Категории, условия эксплуатации, хранения и транспортирования в части воздействия климатических факторов внешней среды»;

- ГОСТ 18620-86 «Изделия электротехнические. Маркировка»;

-ГОСТ 23216-78 «Изделия электротехнические. Хранение, транспортирование, временная противокоррозионная защита, упаковка. Общие требования и методы испытаний»;

- ГОСТ 30804.6.1-2013 «Устойчивость к электромагнитным помехам технических средств, применяемых в жилых, коммерческих зонах и производственных зонах с малым энергопотреблением»;

- ГОСТ Р 51904-2002 «Программное обеспечение встроенных систем. Общие требования к разработке и документированию»;

- ГОСТ МЭК 61140-2012 «Защита от поражения электрическим током. Общие положения для электроустановок и электрооборудования»;

- Гигиенические нормативы ГН 2.1.6.1338-03 «Предельно допустимые концентрации (ПДК) загрязняющих веществ в атмосферном воздухе населенных мест».

# ЛИСТ РЕГИСТРАЦИИ ИЗМЕНЕНИЙ

№ п/п | Пункт и вносимое изменение | Ф.И.О. внесшего изменения | Подп. | Дата
1 | Инициация | Байгуаныш С.Б. | | 16.01.2023

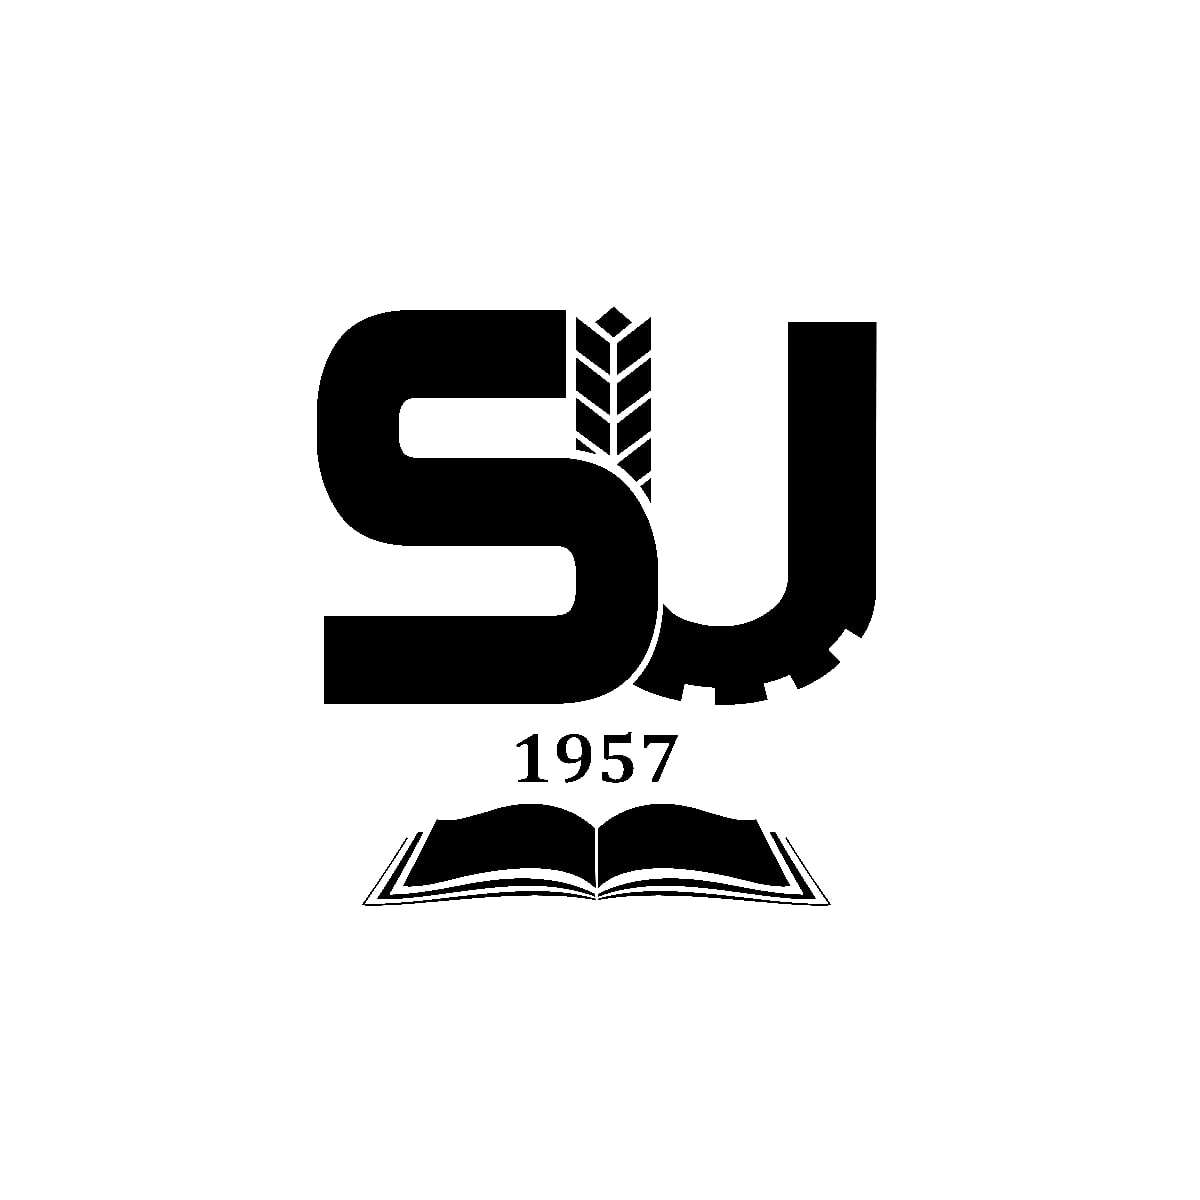
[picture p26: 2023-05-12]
Hardware/казату лого.jpg

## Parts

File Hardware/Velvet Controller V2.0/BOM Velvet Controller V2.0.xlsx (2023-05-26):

 | Velvet_Controller_V2.0_2023.PrjPcb
 | Set: | 1
# | Designator | Description | Name | Footprint | Supplier 1 | Supplier Part Number 1 | Manufacturer Part Number 1 | Manufacturer 1 | Quantity | Total Quantity | Supplier Stock 1 | Supplier Unit Price 1 | Total Price
1 | FU1p | PTC RESET FUSE 60V 5A RADIAL | 0ZRP0500FF2A | 0ZRP0500FF2A | Digi-Key | 507-0ZRP0500FF2ACT-ND | 0ZRP0500FF2A | Bel | 1 | 1 | 25130 | 1.16 | 1.16
2 | VD1io, VD3io, VD8io, VD10io, VD14io | DIODE GEN PURP 100V 150MA SOD123 | 1N4148W-TP | SOD-123 (Marked) | Digi-Key | 1N4148WTPMSCT-ND | 1N4148W-TP | MCC | 5 | 5 | 7535666 | 0.12 | 0.6
3 | C4p | CAP ALUM 680UF 20% 50V RADIAL | 50PX680MEFC12.5X20 | CAP RADIAL D12.5 L20.0 P5.0 | Digi-Key | 565-EKYC500ELL681MK20S-ND | EKYC500ELL681MK20S | United Chemi-Con | 1 | 1 | 8937 | 1.37 | 1.37
4 | X4mc | CONN MICRO SD CARD PUSH-PULL R/A | 114-00841-68 | 114-00841-68 | Digi-Key | 114-00841-68-1-ND | 114-00841-68 | Amphenol Communications Solutions | 1 | 1 | 24795 | 1.66 | 1.66
5 | R1p | RES SMD 1.8K OHM 1% 2W 2512 | 35211K8FT | RES 2512 IPC MAX | Digi-Key | A116038CT-ND | 35211K8FT | TE Connectivity | 1 | 1 | 32445 | 0.58 | 0.58
6 | X1gs | CONN UMCC JACK STR 50OHM SMD | 1909763-1 | 1909763-1 | Digi-Key | A118077CT-ND | 1909763-1 | TE Connectivity AMP | 1 | 1 | 27596 | 0.6 | 0.6
7 | XS1gs | CONN SMART CARD | 693023010811 | 693023010811 | Digi-Key | 732-5956-1-ND | 693023010811 | Wurth Electronics | 1 | 1 | 5867 | 2.42 | 2.42
8 | ZQ1mc | CRYSTAL 8.0000MHZ 18PF SMD | ABM3-8.000MHZ-D2Y-T | ABM3-8.000MHZ-D2Y-T | Digi-Key | 535-10630-1-ND | ABM3-8.000MHZ-D2Y-T | Abracon | 1 | 1 | 31013 | 0.55 | 0.55
9 | K1io, K2io | RELAY GEN PURPOSE SPDT 10A 12V | ALQ112 | ALQ112 | Digi-Key | 255-3562-ND | ALQ112 | Panasonic | 2 | 2 | 87773 | 1.4 | 2.8
10 | DA2p, DA3p, DA4p | IC REG BUCK ADJ 3A 8DFN | AOZ6663DI | DFN 3x3-8L | Digi-Key | 785-1855-1-ND | AOZ6663DI | Alpha & Omega Semiconductor | 3 | 3 | 417392 | 0.61 | 1.83
11 | L3p | FIXED IND 10UH 1.5A 100 MOHM SMD | ASPI-4030S-100M-T | ASPI-4030S | Digi-Key | 535-12314-1-ND | ASPI-4030S-100M-T | Abracon | 1 | 1 | 137388 | 0.41 | 0.41
12 | VD5io, VD11io, VD16io | DIODE ZENER ARRAY 4.7V 300MW SOT23 | AZ23C4V7-HE3-08 | SOT-23-3 | Digi-Key | AZ23C4V7-HE3-08GICT-ND | AZ23C4V7-HE3-08 | Vishay | 3 | 3 | 14960 | 0.33 | 0.99
13 | DA5p | DC DC CONVERTER 5V 1W | B0505MT-1WR4 | B0505MT-1WR4 | Digi-Key | 2725-B0505MT-1WR4CT-ND | B0505MT-1WR4 | MORNSUN | 1 | 1 | 34252 | 1.6 | 1.6
14 | C1p, C7p | CAP FILM 1200PF 5% 2KVDC RADIAL | B32672L8122J000 | CAP RADIAL L18.0 W5.0 H10.5 P15.0 | Digi-Key | 495-3220-ND | B32672L8122J000 | TDK EPCOS | 2 | 2 | 3305 | 0.65 | 1.3
15 | RU1p | VARISTOR 47V 2KA DISC 20MM S20K30 | B72220S0300K101 | B72220S0300K101 | Digi-Key | 495-2405-ND | B72220S0300K101 | TDK EPCOS | 1 | 1 | 6847 | 0.94 | 0.94
16 | VT1gs, VT1io, VT1lr, VT1wf, VT2gs, VT2lr, VT2wf, VT3gs, VT3io, VT3lr | MOSFET N-CH 50V 220MA SOT23 | BSS138-TP | SOT-23-3 | Digi-Key | BSS138-TPMSCT-ND | BSS138-TP | MCC | 10 | 10 | 22121 | 0.193 | 1.93
17 | VD1p, VD19io, VD20io, VD21io, VD22io | DIODE ZENER 12V 200MW SOD123 | BZT52C12-TP | SOD-123 (Marked) | Digi-Key | BZT52C12-TPMSCT-ND | BZT52C12-TP | MCC | 5 | 5 | 114703 | 0.12 | 0.6
18 | C3gs | CAP SMD CER 33PF 50V C0G/NP0 0603 | C0603C330J5GAC7867 | CAP 0603 IPC MAX | Digi-Key | 399-C0603C330J5GAC7867CT-ND | C0603C330J5GACTU | KEMET | 1 | 1 | 1204013 | 0.14 | 0.14
19 | C40p | CAP SMD CER 47PF 6KV SL RADIAL | CC45SL3JD470JYVNA | CC45SL3JD470JYVNA | Digi-Key | 445-CC45SL3JD470JYVNACT-ND | CC45SL3JD470JYVNA | TDK | 1 | 1 | 7747 | 0.43 | 0.43
20 | C4gs | CAP SMD CER 10PF 50V C0G/NP0 0603 | CC0603JRNPO9BN100 | CAP 0603 IPC MAX | Digi-Key | 311-1058-1-ND | CC0603JRNPO9BN100 | Yageo | 1 | 1 | 1045264 | 0.1 | 0.1
21 | C6gs, C6mc, C9mc | CAP SMD CER 22PF 50V NP0 0603 | CC0603JRNPO9BN220 | CAP 0603 IPC MAX | Digi-Key | 311-1062-1-ND | CC0603JRNPO9BN220 | Yageo | 3 | 3 | 1006342 | 0.1 | 0.3
22 | C26p | CAP SMD CER 560PF 50V X7R 0603 | CC0603KRX7R9BB561 | CAP 0603 IPC MAX | Digi-Key | 311-1079-1-ND | CC0603KRX7R9BB561 | Yageo | 1 | 1 | 408628 | 0.1 | 0.1
23 | C1io, C2io, C3io, C5mc, C13mc, C14mc | CAP SMD CER 10000PF 50V X7R 0603 | CL10B103KB8NNNC | CAP 0603 IPC MAX | Digi-Key | 1276-1009-1-ND | CL10B103KB8NNNC | Samsung | 6 | 6 | 7015143 | 0.025 | 0.15
24 | C1wf, C2gs, C6p, C6wf, C7gs, C22mc, C36p, C37p | CAP SMD CER 4.7UF 50V X5R 0805 | CL21A475KBQNNNE | CAP 0805 IPC MAX | Digi-Key | 1276-1248-1-ND | CL21A475KBQNNNE | Samsung | 8 | 8 | 405738 | 0.156 | 1.248
25 | C1lr, C3lr, C3wf, C4wf, C10p, C11p, C15p, C18p, C19p, C22p, C29p, C33p, C38p | CAP SMD CER 10UF 25V X7R 1206 | CL31B106KAHNNNE | CAP 1206 IPC MAX | Digi-Key | 1276-1804-1-ND | CL31B106KAHNNNE | Samsung | 13 | 13 | 5472514 | 0.177 | 2.301
26 | DD2wf | IC USB-SERIAL PART 28SSOP | CY7C65213-28PVXI | TSSOP-28 | Digi-Key | CY7C65213-28PVXI-ND | CY7C65213-28PVXI | Infineon | 1 | 1 | 8297 | 3.74 | 3.74
27 | VT4lr | MOSFET N-CH 20V 4.2A SOT23-3 | DMG2302U-7 | SOT-23-3 | Digi-Key | DMG2302U-7DICT-ND | DMG2302U-7 | Diodes | 1 | 1 | 399433 | 0.37 | 0.37
28 | DD3mc | IC DRIVER LVDS FULL 4/0 16TSSOP | DSLVDS1047PWR | TSSOP-16 | Digi-Key | 296-50740-1-ND | DSLVDS1047PWR | Texas Instruments | 1 | 1 | 901 | 1.93 | 1.93
29 | C3p | CAP ALUM 100UF 20% 50V RADIAL | ECA-1HM101B | CAP RADIAL D8.0 L12.0 P5.0 | Digi-Key | P5182-ND | ECA-1HM101 | Panasonic | 1 | 1 | 93314 | 0.47 | 0.47
30 | C5p | CAP ALUM 330UF 20% 50V RADIAL | ECA-1HM331B | CAP RADIAL D10.0 L17,0 P5.0 - duplicate | Digi-Key | P5184-ND | ECA-1HM331 | Panasonic | 1 | 1 | 37651 | 0.69 | 0.69
31 | DA1mc | FILTER RC(PI) 45 OHM/20PF SMD | EMIF06-MSD02N16 | 16-UFDFN Exposed Pad | Digi-Key | 497-8751-1-ND | EMIF06-MSD02N16 | STMicroelectronics | 1 | 1 | 63348 | 1.11 | 1.11
32 | VD2gs, VD2wf | TVS DIODE 5VWM SOT23-6 | ESDA6V1BC6 | SOT-23-6 | Digi-Key | 497-6635-1-ND | ESDA6V1BC6 | STMicroelectronics | 2 | 2 | 139592 | 0.44 | 0.88
33 | DD1wf | SMD MODULE, ESP32-S2FN4R2 WITH WIFI 802.11B/G/N TRANCEIVER MODULE 2.4GHZ | ESP32-S2-MINI-1U-N4R2 | ESP32-S2-MINI-1U | Digi-Key | 1965-ESP32-S2-MINI-1U-N4R2CT-ND | ESP32-S2-MINI-1U-N4R2 | Espressif Systems | 1 | 1 | 3738 | 2.32 | 2.32
34 | R13p | RES SMD 220 OHM 1% 0.4W 0805 | ESR10EZPF2200 | RES 0805 IPC MAX | Digi-Key | RHM220AECT-ND | ESR10EZPF2200 | Rohm | 1 | 1 | 611114 | 0.21 | 0.21
35 | DD4mc | IC RECEIVER LVDS 0/1 SOT23-5 | FIN1002M5X | SOT-23-5 | Digi-Key | FIN1002M5XCT-ND | FIN1002M5X | ON Semiconductor / Fairchild | 1 | 1 | 44181 | 0.87 | 0.87
36 | VT1p | MOSFET P-CH 40V 12A TO-252 | G12P04K | TO-252 (D-PAK) | Digi-Key | 3141-G12P04KCT-ND | G12P04K | GoFord | 1 | 1 | 4442 | 0.55 | 0.55
37 | C3mc | CAP SMD CER 1000PF 50V X7R 0603 | GCM188R71H102KA37D | CAP 0603 IPC MAX | Digi-Key | 490-4777-1-ND | GCM188R71H102KA37D | Murata | 1 | 1 | 6857460 | 0.19 | 0.19
38 | C1mc, C2mc, C2wf, C4mc, C5gs, C5lr, C5wf, C6lr, C7lr, C7wf, C9p, C13p, C14p, C15mc, C16mc, C17mc, C17p, C18mc, C19mc, C20mc, C21mc, C21p, C24mc, C24p, C31p, C32p, C35p | CAP SMD CER 0.1UF 50V X7R 0603 | GCM188R71H104KA57D | CAP 0603 IPC MAX | Digi-Key | 490-4779-1-ND | GCM188R71H104KA57D | Murata | 27 | 27 | 15368699 | 0.184 | 4.968
39 | C7mc, C8mc, C12mc | CAP SMD CER 2.2UF 25V X5R 0603 | GRM188R61E225KA12D | CAP 0603 IPC MAX | Digi-Key | 490-10731-1-ND | GRM188R61E225KA12D | Murata | 3 | 3 | 1082890 | 0.14 | 0.42
40 | C25p | CAP SMD CER 1500PF 50V C0G/NP0 0603 | GRM1885C1H152JA01D | CAP 0603 IPC MAX | Digi-Key | 490-1455-1-ND | GRM1885C1H152JA01D | Murata | 1 | 1 | 1725678 | 0.1 | 0.1
41 | C39p | CAP SMD CER 1800PF 50V C0G/NP0 0603 | GRM1885C1H182JA01D | CAP 0603 IPC MAX | Digi-Key | 490-1457-1-ND | GRM1885C1H182JA01D | Murata | 1 | 1 | 268710 | 0.1 | 0.1
42 | VD1mc, VD1wf, VD2mc, VD2p, VD3mc, VD4gs, VD4mc, VD5gs, VD5mc, VD6mc, VD7mc, VD8mc, VD9mc, VD10mc, VD11mc, VD12mc, VD13mc | LED GREEN CLEAR SMD R/A | LTST-S220GKT | 0805 DIODE | Digi-Key | 160-1218-1-ND | LTST-S220GKT | Vishay Lite-On | 17 | 17 | 300893 | 0.133 | 2.261
43 | VD1gs | DIODE ZENER 5.1V 500MW SOD123 | MMSZ5231B-E3-08 | SOD-123 (Marked) | Digi-Key | MMSZ5231B-E3-08CT-ND | MMSZ5231B-E3-08 | Vishay | 1 | 1 | 10998 | 0.27 | 0.27
44 | JP1lr, JP1wf, JP2lr, JP2wf, JP3lr, JP3wf, JP4wf | CONN HEADER VERT 2POS 2.54MM | PREC002SAAN-RC | 2P TH 2.54mm | Digi-Key | S1012EC-02-ND | PREC002SAAN-RC | Sullins | 7 | 7 | 22112 | 0.06 | 0.42
45 | C2p, C8p | CAP FILM 4700PF 20% 1KVDC RAD | R474F147050A1M | CAP RADIAL L13.0 W4.0 H9.1 P10.0 | Digi-Key | 399-13727-ND | R474F147050A1M | KEMET | 2 | 2 | 9531 | 0.41 | 0.82
46 | R1mc, R2mc, R3mc, R18lr, R19lr, R20lr | RES SMD 4.99K OHM 1% 1/10W 0603 | RC0603FR-074K99L | RES 0603 IPC MAX | Digi-Key | 311-4.99KHRCT-ND | RC0603FR-074K99L | Yageo | 6 | 6 | 4003857 | 0.019 | 0.114
47 | R1io, R8gs, R8lr, R9gs, R9lr, R10io, R16lr, R21io, R24io | RES SMD 1K OHM 1% 1/10W 0603 | RMCF0603FT1K00 | RES 0603 IPC MAX | Digi-Key | RMCF0603FT1K00CT-ND | RMCF0603FT1K00 | Stackpole Electronics | 9 | 9 | 10120910 | 0.015 | 0.135
48 | R2io, R9io, R17io | RES SMD 1.5K OHM 1% 1/10W 0603 | RMCF0603FT1K50 | CAP 0603 IPC MAX | Digi-Key | RMCF0603FT1K50CT-ND | RMCF0603FT1K50 | Stackpole Electronics | 3 | 3 | 448131 | 0.015 | 0.045
49 | R10lr, R11lr | RES SMD 2K OHM 1% 1/10W 0603 | RMCF0603FT2K00 | RES 0603 IPC MAX | Digi-Key | RMCF0603FT2K00CT-ND | RMCF0603FT2K00 | Stackpole Electronics | 2 | 2 | 1757808 | 0.015 | 0.03
50 | R1gs | RES SMD 4.7k OHM 1% 1/10W 0603 | RMCF0603FT4K70 | RES 0603 IPC MAX | Digi-Key | RMCF0603FT4K70CT-ND | RMCF0603FT4K70 | Stackpole Electronics | 1 | 1 | 3663901 | 0.1 | 0.1
51 | R6io, R12gs, R13io, R20io | RES SMD 5.6K OHM 1% 1/10W 0603 | RMCF0603FT5K60 | RES 0603 IPC MAX | Digi-Key | RMCF0603FT5K60CT-ND | RMCF0603FT5K60 | Stackpole Electronics | 4 | 4 | 322596 | 0.015 | 0.06
52 | R9p, R10p, R15p | RES SMD 15K OHM 1% 1/10W 0603 | RMCF0603FT15K0 | RES 0603 IPC MAX | Digi-Key | RMCF0603FT15K0CT-ND | RMCF0603FT15K0 | Stackpole Electronics | 3 | 3 | 671317 | 0.015 | 0.045
53 | R5io, R8io, R8p, R14io, R16io, R22io, R23io, R25io, R26io | RES SMD 22K OHM 1% 1/10W 0603 | RMCF0603FT22K0 | RES 0603 IPC MAX | Digi-Key | RMCF0603FT22K0CT-ND | RMCF0603FT22K0 | Stackpole Electronics | 9 | 9 | 635364 | 0.015 | 0.135
54 | R2p | RES SMD 27K OHM 1% 1/10W 0603 | RMCF0603FT27K0 | RES 0603 IPC MAX | Digi-Key | RMCF0603FT27K0CT-ND | RMCF0603FT27K0 | Stackpole Electronics | 1 | 1 | 348430 | 0.1 | 0.1
55 | R14p | RES SMD 33K OHM 1% 1/10W 0603 | RMCF0603FT33K0 | RES 0603 IPC MAX | Digi-Key | RMCF0603FT33K0CT-ND | RMCF0603FT33K0 | Stackpole Electronics | 1 | 1 | 695555 | 0.1 | 0.1
56 | R2gs, R3gs, R4gs | RES SMD 51 OHM 1% 1/10W 0603 | RMCF0603FT51R0 | RES 0603 IPC MAX | Digi-Key | RMCF0603FT51R0CT-ND | RMCF0603FT51R0 | Stackpole Electronics | 3 | 3 | 553641 | 0.015 | 0.045
57 | R7p | RES SMD 59K OHM 5% 1/10W 0603 | RMCF0603FT59K0 | RES 0603 IPC MAX | Digi-Key | RMCF0603FT59K0CT-ND | RMCF0603FT59K0 | Stackpole Electronics | 1 | 1 | 288207 | 0.1 | 0.1
58 | R6p | RES SMD 68K OHM 1% 1/10W 0603 | RMCF0603FT68K0 | RES 0603 IPC MAX | Digi-Key | RMCF0603FT68K0CT-ND | RMCF0603FT68K0 | Stackpole Electronics | 1 | 1 | 155287 | 0.1 | 0.1
59 | R5p | RES SMD 86.6K OHM 5% 1/10W 0603 | RMCF0603FT86K6 | RES 0603 IPC MAX | Digi-Key | RMCF0603FT86K6CT-ND | RMCF0603FT86K6 | Stackpole Electronics | 1 | 1 | 233731 | 0.1 | 0.1
60 | R3p, R3wf, R4p, R4wf, R11p, R13gs, R14gs, R15gs | RES SMD 100K OHM 5% 1/10W 0603 | RMCF0603FT100K | RES 0603 IPC MAX | Digi-Key | RMCF0603FT100KCT-ND | RMCF0603FT100K | Stackpole Electronics | 8 | 8 | 6105469 | 0.015 | 0.12
61 | R18mc | RES SMD 100 OHM 1% 1/10W 0603 | RMCF0603FT100R | RES 0603 IPC MAX | Digi-Key | RMCF0603FT100RCT-ND | RMCF0603FT100R | Stackpole Electronics | 1 | 1 | 5585670 | 0.1 | 0.1
62 | R12p | RES SMD 110K OHM 1% 1/10W 0603 | RMCF0603FT110K | RES 0603 IPC MAX | Digi-Key | RMCF0603FT110KCT-ND | RMCF0603FT110K | Stackpole Electronics | 1 | 1 | 182102 | 0.1 | 0.1
63 | R1lr, R1wf, R2lr, R3io, R3lr, R4io, R4lr, R4mc, R5lr, R5wf, R6lr, R7io, R7lr, R11io, R12io, R15io, R17lr, R18io, R19io | RES SMD 10K OHM 5% 1/10W 0603 | RMCF0603JT10K0 | RES 0603 IPC MAX | Digi-Key | RMCF0603JT10K0CT-ND | RMCF0603JT10K0 | Stackpole Electronics | 19 | 19 | 18393008 | 0.014 | 0.266
64 | R2wf | RES 510 OHM 5% 1/10W 0603 | RMCF0603JT510R | RES 0603 IPC MAX | Digi-Key | RMCF0603JT510RCT-ND | RMCF0603JT510R | Stackpole Electronics | 1 | 1 | 172038 | 0.1 | 0.1
65 | R5mc, R6mc, R7mc, R8mc, R9mc, R10gs, R10mc, R11gs, R11mc, R12mc, R13mc, R14mc, R15mc, R16mc, R17mc | RES SMD 510 OHM 5% 1/10W 0603 | RMCF0603JT510R | RES 0603 IPC MAX | Digi-Key | RMCF0603JT510RCT-ND | RMCF0603JT510R | Stackpole Electronics | 15 | 15 | 172038 | 0.014 | 0.21
66 | R5gs | RES SMD 0 OHM 1% 1/10W 0603 | RMCF0603ZT0R00 | RES 0603 IPC MAX | Digi-Key | RMCF0603ZT0R00CT-ND | RMCF0603ZT0R00 | Stackpole Electronics | 1 | 1 | 17193506 | 0.1 | 0.1
67 | R12lr, R13lr, R14lr, R15lr | RES SMD 18 OHM 5% 1/2W 1210 | RMCF1210JT18R0 | RES 1210 | Digi-Key | RMCF1210JT18R0CT-ND | RMCF1210JT18R0 | Stackpole Electronics | 4 | 4 | 9145 | 0.11 | 0.44
68 | L1p | COMMON MODE CHOKE 700UH 4A 2LN TH | RN212-4-02-0M7 | FIXED IND RN212-4-02-0M7 | Digi-Key | 817-2176-ND | RN212-4-02-0M7 | Schaffner | 1 | 1 | 10613 | 2.19 | 2.19
69 | VD4io, VD9io, VD15io | DIODE GEN PURP 1KV 1A SMA | S1M | DO-214AC Unidirectional | Digi-Key | S1MFSCT-ND | S1M | ON Semiconductor / Fairchild | 3 | 3 | 890 | 0.39 | 1.17
70 | U1io, U2io, U3io, U4io, U5io, U6io, U7io | OPTOISOLATOR 5.3KV TRANS 4-SMD | SFH6206-3T | 11-5L106 | Digi-Key | SFH6206-3TCT-ND | SFH6206-3T | Vishay Semiconductors | 7 | 7 | 22234 | 0.672 | 4.704
71 | VD3gs | TVS DIODE 5VWM 9.2VC DO214AC | SMAJ5.0CA | DO-214AC Bidirectional | Digi-Key | SMAJ5.0CABCT-ND | SMAJ5.0CA | Bourns | 1 | 1 | 54096 | 0.41 | 0.41
72 | VD2io, VD7io, VD13io | TVS DIODE 36VWM 58.1VC DO214AC | SMAJ36CA | DO-214AC Bidirectional | Digi-Key | SMAJ36CALFCT-ND | SMAJ36CA | Littelfuse | 3 | 3 | 48333 | 0.42 | 1.26
73 | VD6io, VD12io, VD17io, VD18io | TVS DIODE 36VWM 58.1VC DO214AB | SMCJ36A | DO214-AB (SMC) L3.2W1.52 | Digi-Key | SMCJ36ALFCT-ND | SMCJ36A | Littelfuse | 4 | 4 | 77916 | 0.51 | 2.04
74 | VD14mc, VD15mc, VD16mc, VD17mc, VD18mc, VD19mc, VD20mc, VD21mc | TVS DIODE 3.3VWM 9VC 2DFN | SP1103C-01UTG | 2-DFN 1.6x1.0 | Digi-Key | F10154CT-ND | SP1103C-01UTG | Littelfuse | 8 | 8 | 230877 | 0.53 | 4.24
75 | L2p | FIXED IND 4.7UH 3.1A 35 MOHM SMD | SRN5040-4R7M | SRN5040 | Digi-Key | SRN5040-4R7MCT-ND | SRN5040-4R7M | Bourns | 1 | 1 | 125076 | 0.51 | 0.51
76 | C2lr, C4lr, C8wf, C10mc, C11mc, C12p, C16p, C20p, C23mc, C23p, C27p, C28p, C30p, C34p, C41p | CAP SMD CER 1UF 25V X5R 0603 | TMK107BJ105KA-T | CAP 0603 IPC MAX | Digi-Key | 587-1248-1-ND | TMK107BJ105KA-T | Taiyo | 15 | 15 | 5287467 | 0.07 | 1.05
77 | DD2mc, DD3lr | SOT-563 TEMPERATURE SENSORS ROHS | TMP112AIDRLR | SOT-563 | Digi-Key | 296-38578-1-ND | TMP112AIDRLR | Texas Instruments | 2 | 2 | 32271 | 2.7 | 5.4
78 | VT2io, VT4io, VT5io, VT6io | MOSFET N-CH 100V 42A MLPAK33 | TPN1200APL,L1Q | 8-PowerVDFN | Digi-Key | 264-TPN1200APLL1QCT-ND | TPN1200APL,L1Q | Toshiba | 4 | 4 | 4039 | 0.85 | 3.4
79 | C1gs | CAP SMD TANT 100UF 20% 10V 2917 | TPSD107M010R0050 | CAP 2917 (D) | Digi-Key | 478-4095-1-ND | TPSD107M010R0050 | Kyocera AVX | 1 | 1 | 19128 | 1.58 | 1.58
80 | X1lr, X1mc | CONN HEADER VERT 8POS 2.54MM 2ROWx4 | TSW-104-07-F-D | HEADER 2.54mm 2ROW 8PIN | Digi-Key | SAM8996-ND | TSW-104-07-F-D | Samtec | 2 | 2 | 73889 | 0.97 | 1.94
81 | L4p | FIXED IND 22UH 1.1A 226 MOHM SMD | TYS5020220M-10 | TYS5020 | Digi-Key | 240-2706-1-ND | TYS5020220M-10 | Laird Steward | 1 | 1 | 221111 | 0.49 | 0.49
82 | DA1p | DC DC CONVERTER 12V 30W | URB2412LD-30WR3 | URB2412LD-30WR3 | Digi-Key | 2725-URB2412LD-30WR3-ND | URB2412LD-30WR3 | MORNSUN | 1 | 1 | 2170 | 17.08 | 17.08
83 | X1wf | MICRO B SKT, VERTICAL, TH, 30", | USB3131-30-0230-A | USB3131-30-0230-A | Digi-Key | 2073-USB3131-30-0230-ACT-ND | USB3131-30-0230-A | GCT | 1 | 1 | 14897 | 0.81 | 0.81
84 | L5p | FIXED IND 6.8UH 3.6A 36 MOHM SMD | VLS6045EX-6R8M | VLS6045EX | Digi-Key | 445-173057-1-ND | VLS6045EX-6R8M | TDK | 1 | 1 | 344082 | 0.46 | 0.46
85 | ANT1wf, ANT2lr | WATERPROOF SMA TO IPEX FOR 1.13 | CA-DKCA0-152L0-AJI0-O |  |  |  | CA-DKCA0-152L0-AJI0-O | Adam Equipment | 2 | 2 |  |  | 0
86 | DD1lr | UHF RFID Reader Module | CF-MU904 | CF-MU904 |  |  | CF-MU904 | ChaFon | 1 | 1 |  |  | 0
87 | R6gs, R7gs | RES SMD/TH ?R (&K) OHM ?% ?W (PACKAGE) | DNP | RES 0603 IPC MAX |  |  |  |  | 2 | 2 |  |  | 0
88 | X3mc, X5mc | TERMINAL BLOCK 5 PIN 2.54mm 2A 150V T/H | KF141V-2.54-5P | KF141V-2.54-5P |  |  | KF141V-2.54-5P | CIXI KEFA ELECTRONICS CO.,LTD. | 2 | 2 |  |  | 0
89 | X2mc | TERMINAL BLOCK 6 PIN 2.54mm 2A 150V T/H | KF141V-2.54-6P | KF141V-2.54-6P |  |  | KF141V-2.54-6P | CIXI KEFA ELECTRONICS CO.,LTD. | 1 | 1 |  |  | 0
90 | X1io, X2io, X3io | TERMINAL BLOCK 8 PIN 5.08mm 15A 250V T/H | KF142V-5.08-8P | KF142V-5.08-8P |  |  | KF142V-5.08-8P | CIXI KEFA ELECTRONICS CO.,LTD. | 3 | 3 |  |  | 0
91 | ANT1lr | MCX-Male to SMA RF 15cm connector | MCX-SMA |  |  |  | - | DexMRtiC | 1 | 1 |  |  | 0
92 | DD2lr | MODULE FOR LORAWAN RAK3172 | RAK3172-P3 RUI | RAK3172 |  |  | RAK3172-P3 RUI | RAKwireless Technology Limited | 1 | 1 |  |  | 0
93 | DD1gs | GSM/GPRS Module | SIM800C | SIM-800C |  |  | SIM800C | SIMCom | 1 | 1 |  |  | 0
94 | DD1mc | IC MCU 32BIT 1MB FLASH 100LQFP | STM32F407VGT6 | LQFP50P1600X1600X160-100M |  |  | STM32F407VGT6 | STMicroelectronics | 1 | 1 |  |  | 0
95 | X2gs | CABLE ASSY 6" SMA FM TO I-PEX | W9006M |  |  |  | W9006M | PULS | 1 | 1 |  |  | 0
 |  |  |  |  |  |  |  |  |  |  |  |  | 100.177

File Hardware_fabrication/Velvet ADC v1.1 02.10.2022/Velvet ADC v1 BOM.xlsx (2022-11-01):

 | Velvet ADC module.PrjPcb
 | Set: | 6
# | Designator | Description | Supplier Part Number 1 | Manufacturer Part Number 1 | Manufacturer Part Number 2 | Total Quantity
1 | C4, C12 |  | 1276-1264-1-ND | CL31B225KOHNNNE |  | 12
2 | L1 |  | 445-MLZ1608M6R8WT000CT-ND | MLZ1608M6R8WT000 |  | 6
3 | R5 |  | 311-8.20KHRCT-ND | RC0603FR-078K2L |  | 6
4 | R3 |  | 311-20.0KHRCT-ND | RC0603FR-0720KL |  | 6
5 | X1, X3, X5, X6, X8 |  | A98263-ND | 796690-5 |  | 30
6 | C1, C2, C9 | 4.7 µF ±10% 50V Ceramic Capacitor X5R 0805 (2012 Metric) | 445-5980-1-ND | C2012X5R1H475K125AB |  | 18
7 | VD1, VD2, VD3, VD4 | 7.5V (Typ) Clamp 5A (8/20µs) Ipp Tvs Diode Surface Mount SOD-882 | F5769CT-ND | SP3031-01ETG |  | 24
8 | R1, R2, R4, R6 | 50 Ohms 0.5W, 1/2W PC Pins Through Hole Trimmer Potentiometer Cermet 25.0 Turn Top Adjustment | 3296W-500LF-ND | 3296W-1-500LF | PV36W500C01B00 | 24
9 | R7, R8 | 100 Ohms ±1% 0.1W, 1/10W Chip Resistor 0603 (1608 Metric) Moisture Resistant Thick Film | 311-100HRCT-ND | RC0603FR-07100RL |  | 12
10 | DA1 | ADC for Weigh Scales | https://aliexpress.ru/item/1005002044866368.html?sku_id=12000018535124718 | HX711 |  | 6
11 | VT1 | Bipolar | MMSS8550-L-TPMSCT-ND | MMSS8550-L-TP |  | 6
12 | C3, C6 | Cap Ceramic 10uF 16V X7R 20% SMD 1206 125°C Embossed T/R | 1276-6641-1-ND | CL31B106MOHNNNE |  | 12
13 | U1 | Isolated Module DC DC Converter 1 Output 9V - - - 111mA 10.8V - 13.2V Input | 102-2970-1-ND | PDS1-S12-S9-M-TR |  | 6
14 | U2 | Linear Voltage Regulator IC Positive Fixed 1 Output 150mA SOT-25-5 | 893-1065-1-ND | XC6204B502MR-G | MCP1802T-5002I/OT | 6
15 | C5, C7, C8, C10, C11 | Surface Mount Ceramic Multilayer Capacitor 0.1uF 5% X7R 16V 0805 Paper T/R | 311-4266-1-ND | CC0805JRX7R7BB104 |  | 30

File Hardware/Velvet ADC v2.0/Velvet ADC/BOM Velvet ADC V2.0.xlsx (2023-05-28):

 | Velvet ADC.PrjPcb
 | Set: | 1
# | Designator | Description | Name | Footprint | Supplier 1 | Supplier Part Number 1 | Manufacturer Part Number 1 | Manufacturer 1 | Quantity | Total Quantity | Supplier Stock 1 | Supplier Unit Price 1 | Total Price
1 | X2c | TERMINAL BLOCK 2 PIN 2.54mm 2A 150V T/H | KF141V-2.54-2P | KF141V-2.54-2P | Aliexpress | 2P | 2P | QR Worldchips Store | 1 | 1 | 1000 | 2.38 | 2.38
2 | XP2c, XP3c, XP4c, XP5c | CONN RCPT 7POS IDC 24AWG TIN | 3-640441-7 |  | Digi-Key | A30983-ND | 3-640441-7 | TE Connectivity | 4 | 4 | 16580 | 0.61 | 2.44
3 | XP1c | CONN RCPT 8POS IDC 24AWG TIN | 3-640441-8 |  | Digi-Key | A30984-ND | 3-640441-8 | TE Connectivity | 1 | 1 | 34690 | 0.67 | 0.67
4 | X1a | CONN HEADER VERT 6POS 2.54MM | 640456-6 | 640456-6 | Digi-Key | A1923-ND | 640456-6 | TE Connectivity | 1 | 1 | 148953 | 0.38 | 0.38
5 | X1c, X4c, X5c, X12c | CONN HEADER VERT 7POS 2.54MM | 640456-7 | 640456-7 | Digi-Key | A19472-ND | 640456-7 | TE Connectivity | 4 | 4 | 11845 | 0.39 | 1.56
6 | X3c | CONN HEADER VERT 8POS 2.54MM | 640456-8 | 640456-8 | Digi-Key | A1924-ND | 640456-8 | TE Connectivity | 1 | 1 | 69971 | 0.47 | 0.47
7 | L1a | FERRITE BEAD 600 OHM 0603 1LN | 742792651 | IND 0603 IPC MAX | Digi-Key | 732-1593-1-ND | 742792651 | Wurth Electronics | 1 | 1 | 511968 | 0.18 | 0.18
8 | DA1a | IC ADC 24BIT SIGMA-DELTA 16TSSOP | AD7797BRUZ | TSSOP-16 | Digi-Key | 505-AD7797BRUZ-ND | AD7797BRUZ | Analog Devices | 1 | 1 | 16841 | 11.71 | 11.71
9 | DA4a | IC REG BUCK ADJ 3A 8DFN | AOZ6663DI | DFN 3x3-8L | Digi-Key | 785-1855-1-ND | AOZ6663DI | Alpha & Omega Semiconductor | 1 | 1 | 417392 | 0.61 | 0.61
10 | L3a | FIXED IND 10UH 1.5A 100 MOHM SMD | ASPI-4030S-100M-T | ASPI-4030S | Digi-Key | 535-12314-1-ND | ASPI-4030S-100M-T | Abracon | 1 | 1 | 137388 | 0.41 | 0.41
11 | DA2a | DC DC CONVERTER 12V 2W | B1212M-2WR3 | B1212M-2WR3 | Digi-Key | 2725-B1212M-2WR3-ND | B1212M-2WR3 | MORNSUN | 1 | 1 | 141 | 2.82 | 2.82
12 | C20a, C21a | CAP SMD CER 4.7UF 50V X5R 0805 | CL21A475KBQNNNE | CAP 0805 IPC MAX | Digi-Key | 1276-1248-1-ND | CL21A475KBQNNNE | Samsung | 2 | 2 | 399996 | 0.23 | 0.46
13 | C17a, C24a, C25a | CAP SMD CER 10UF 25V X7R 1206 | CL31B106KAHNNNE | CAP 1206 IPC MAX | Digi-Key | 1276-1804-1-ND | CL31B106KAHNNNE | Samsung | 3 | 3 | 5466402 | 0.26 | 0.78
14 | DD1a | IC RECEIVER LVDS FULL 0/4 16TSSOP | DSLVDS1048PWR | TSSOP-16 | Digi-Key | 296-51106-1-ND | DSLVDS1048PWR | Texas Instruments | 1 | 1 | 3014 | 1.93 | 1.93
15 | VD1a, VD12c | TVS DIODE 5VWM SOT23-6 | ESDA6V1BC6 | SOT-23-6 | Digi-Key | 497-6635-1-ND | ESDA6V1BC6 | STMicroelectronics | 2 | 2 | 139582 | 0.44 | 0.88
16 | DD3a | IC DRIVER LVDS 1/0 SOT23-5 | FIN1001M5X | SOT-23-5 | Digi-Key | FIN1001M5XCT-ND | FIN1001M5X | ON Semiconductor / Fairchild | 1 | 1 | 31185 | 1.35 | 1.35
17 | C4a, C5a, C6a, C7a, C9a, C11a, C12a, C13a, C15a, C16a, C23a | CAP SMD CER 0.1UF 50V X7R 0603 | GCM188R71H104KA57D | CAP 0603 IPC MAX | Digi-Key | 490-4779-1-ND | GCM188R71H104KA57D | Murata | 11 | 11 | 15367679 | 0.184 | 2.024
18 | C26a | CAP SMD CER 1500PF 50V C0G/NP0 0603 | GRM1885C1H152JA01D | CAP 0603 IPC MAX | Digi-Key | 490-1455-1-ND | GRM1885C1H152JA01D | Murata | 1 | 1 | 1722668 | 0.1 | 0.1
19 | DD2a | DIG ISO - MYNA - QUAD | ISO7741BDW | SOIC-16 IPC MAX | Digi-Key | 296-ISO7741BDW-ND | ISO7741BDW | Texas Instruments | 1 | 1 | 23 | 3.83 | 3.83
20 | VD2a | LED GREEN CLEAR SMD R/A | LTST-S220GKT | 0805 DIODE | Digi-Key | 160-1218-1-ND | LTST-S220GKT | Vishay Lite-On | 1 | 1 | 300793 | 0.25 | 0.25
21 | DA3a | IC REG LINEAR 5V 300MA TSOT23-5 | NCP718ASN500T1G | TSOT-23-5 | Digi-Key | NCP718ASN500T1GOSCT-ND | NCP718ASN500T1G | ON Semiconductor | 1 | 1 | 68766 | 0.69 | 0.69
22 | C22a | CAP FILM 270PF 5% 2KVDC RADIAL | PHE448SB3270JR06 | CAP RADIAL L18.0 W5.0 H10.5 P15.0 | Digi-Key | 399-PHE448SB3270JR06-ND | PHE448SB3270JR06 | KEMET | 1 | 1 | 1938 | 1.33 | 1.33
23 | R2c, R4c, R6c, R8c | TRIMMER 50 OHM 0.5W PC PIN TOP | PV36W500C01B00 | RES: 3296W | Digi-Key | 490-2886-ND | PV36W500C01B00 | Bourns | 4 | 4 | 3830 | 1.77 | 7.08
24 | R12a | RES SMD 2K OHM 1% 1/10W 0603 | RMCF0603FT2K00 | RES 0603 IPC MAX | Digi-Key | RMCF0603FT2K00CT-ND | RMCF0603FT2K00 | Stackpole Electronics | 1 | 1 | 1757558 | 0.1 | 0.1
25 | R4a, R5a | RES SMD 4.7k OHM 1% 1/10W 0603 | RMCF0603FT4K70 | RES 0603 IPC MAX | Digi-Key | RMCF0603FT4K70CT-ND | RMCF0603FT4K70 | Stackpole Electronics | 2 | 2 | 3563399 | 0.015 | 0.03
26 | R16a | RES SMD 15K OHM 1% 1/10W 0603 | RMCF0603FT15K0 | RES 0603 IPC MAX | Digi-Key | RMCF0603FT15K0CT-ND | RMCF0603FT15K0 | Stackpole Electronics | 1 | 1 | 691562 | 0.1 | 0.1
27 | R15a | RES SMD 22K OHM 1% 1/10W 0603 | RMCF0603FT22K0 | RES 0603 IPC MAX | Digi-Key | RMCF0603FT22K0CT-ND | RMCF0603FT22K0 | Stackpole Electronics | 1 | 1 | 635964 | 0.1 | 0.1
28 | R14a | RES SMD 68K OHM 1% 1/10W 0603 | RMCF0603FT68K0 | RES 0603 IPC MAX | Digi-Key | RMCF0603FT68K0CT-ND | RMCF0603FT68K0 | Stackpole Electronics | 1 | 1 | 155287 | 0.1 | 0.1
29 | R13a | RES SMD 100K OHM 5% 1/10W 0603 | RMCF0603FT100K | RES 0603 IPC MAX | Digi-Key | RMCF0603FT100KCT-ND | RMCF0603FT100K | Stackpole Electronics | 1 | 1 | 5992682 | 0.1 | 0.1
30 | R3a, R6a, R7a, R8a, R9a, R10a, R11a | RES SMD 100 OHM 1% 1/10W 0603 | RMCF0603FT100R | RES 0603 IPC MAX | Digi-Key | RMCF0603FT100RCT-ND | RMCF0603FT100R | Stackpole Electronics | 7 | 7 | 5517565 | 0.015 | 0.105
31 | R1a, R2a | RES SMD 0 OHM 1% 1/10W 0603 | RMCF0603ZT0R00 | RES 0603 IPC MAX | Digi-Key | RMCF0603ZT0R00CT-ND | RMCF0603ZT0R00 | Stackpole Electronics | 2 | 2 | 17106455 | 0.013 | 0.026
32 | VD1c, VD3c, VD13c, VD14c | TVS DIODE 5VWM 9.2VC DO214AC | SMAJ5.0CA | DO-214AC Bidirectional | Digi-Key | SMAJ5.0CABCT-ND | SMAJ5.0CA | Bourns | 4 | 4 | 54096 | 0.41 | 1.64
33 | VD2c | TVS DIODE 12VWM 25.3VC SMA | SMAJ12CA-TR | DO-214AC Bidirectional | Digi-Key | 497-2996-1-ND | SMAJ12CA-TR | STMicroelectronics | 1 | 1 | 67359 | 0.45 | 0.45
34 | VD4c, VD5c, VD6c, VD7c, VD8c, VD9c, VD10c, VD11c | TVS DIODE 3.3VWM 9VC 2DFN | SP1103C-01UTG | 2-DFN 1.6x1.0 | Digi-Key | F10154CT-ND | SP1103C-01UTG | Littelfuse | 8 | 8 | 230852 | 0.53 | 4.24
35 | C3a, C10a | CAP TANT 10UF 20% 35V 2917 | TAJD106M035RNJ | CAP 2917 (D) | Digi-Key | 478-3916-1-ND | TAJD106M035RNJ | Kyocera AVX | 2 | 2 | 159966 | 1 | 2
36 | C1a, C1c, C2a, C2c, C3c, C4c, C8a, C14a, C18a, C19a | CAP SMD CER 1UF 25V X5R 0603 | TMK107BJ105KA-T | CAP 0603 IPC MAX | Digi-Key | 587-1248-1-ND | TMK107BJ105KA-T | Taiyo | 10 | 10 | 5287417 | 0.07 | 0.7
37 | C27a | CAP SMD CER 1UF 25V X5R 0603 | TMK107BJ105KA-T | CAP 0603 IPC MAX | Digi-Key | 587-1248-1-ND | TMK107BJ105KA-T | Taiyo | 1 | 1 | 5287417 | 0.1 | 0.1
38 | L2a | FIXED IND 6.8UH 3.6A 36 MOHM SMD | VLS6045EX-6R8M | VLS6045EX | Digi-Key | 445-173057-1-ND | VLS6045EX-6R8M | TDK | 1 | 1 | 343072 | 0.46 | 0.46
 |  |  |  |  |  |  |  |  |  |  |  |  | 54.585

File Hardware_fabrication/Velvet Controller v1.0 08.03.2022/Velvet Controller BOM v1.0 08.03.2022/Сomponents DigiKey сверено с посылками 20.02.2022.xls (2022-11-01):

 |  |  | Для закупа на 'DigiKey
# | Category | Designator | Value | Digi-Key Part Number | Manufacturer | Comment | Description | Quantity
1 | Schottky Rectifier | D1, D2 | 3 A | SS34-E3/57T |  |  | Schottky Rectifier | 10
2 | Inductors, Coils, Chokes | L2 | 68µH | SRR1210-680MDKR-ND | Bourns Inc. | SRR1210 | Magnetic-Core Inductor | 20
3 | TVS - Diodes | TVS |  | 497-11379-1-ND | STMicroelectronics | (EMC_POWER) | TVS DIODE 30.8VWM 64.3VC DO201 | 20
4 | Tantalum Capacitors | C34 | CAP TANT 10UF 10% 16V 1206 | F931C106KAA | KYOCERA AVX | Capacitor Polarized | CAP TANT 10UF 10% 16V 1206 | 20
5 | Tantalum Capacitors | C24 | 16V, 1uF | 293D105X9016A2TE3 | Vishay Sprague | Capacitor Polarized | CAP TANT 1UF 10% 16V 1206 | 5
6 | Filters | L3 | 400 mA | BLM18AG102SN1D | Murata Electronics North America | Inductor | FERRITE BEAD 1 KOHM 0603 1LN | 40
7 | Button | PB1-PB3 |  | B3F-1000 | OMRON | Push Button | Push-Button Switch SPDT | 20 | 1
8 | Oscillator | Y2 | CRYSTAL 32.7680KHZ 12.5PF SMD | ECS-.327-12.5-34B-TR | ECS International |  | CRYSTAL 32.7680KHZ 12.5PF SMD | 16
9 | RF/IF and RFID | GPRS/GSM | COM.GSM MODULE (SIM800C) | 2221-M031-D-ND | M5Stack Technology Co., Ltd. | SIM800C | COM.GSM MODULE (SIM800C) | 6
10 | CRD Micro SIM | XS1 |  | 693022010811 | Wurth Electronics | WE-Card Connectors | WR-CRD Micro SIM_Hinge_8 pins | 10
11 | Wi-Fi module | M1 | SMD MODULE W/IPEX ANT | ESP32-S2-MINI-1U-N4 | Espressif System | ESP32-S2-MINI-1U _Module | SMD MODULE W/IPEX ANT CONNECTOR | 20
12 | Cable | A3 |  | CABLE 348 RF-150-A-1 | GradConn | CABLE 348 RF-150-A-1 | CBL ASSY MHF1-SMA 5.906" | 5
13 | Cable | A4 | CBL ASSY MHF1-RP SMA 5.906" | CABLE 197 RF-150-A-4 | GradConn | CABLE 197 RF-150-A-4 | CBL ASSY MHF-RP SMA RG178 5.906" | 5
14 | Interconnects USB |  |  | ‎732-5962-1-ND‎ (https://www.digikey.com/product-detail/en/614104150121/732-5962-1-ND/5047551?itemSeq=383072066) | Würth Elektronik | USB 2.0 | CONN RCPT USB2.0 TYPEA 4POS R/A | 5
15 | Transistors - Bipolar | Q1 | NPN 45V 500MA | SBC817-16LT3G | onsemi | SBC817-16LT3G | TRANS NPN 45V 500MA SOT23 | 20
16 | Memory Card | Memory Card microSD |  | AP-MSD256ISI-1T | Apacer | MicroSD_Card | MEMORY CARD MICROSD 256MB SLC | 5
17 | PC Card Sockets (https://www.digikey.com/en/products/filter/memory-connectors-pc-card-sockets/414) |  |  | 1051620001 | Molex |  | 1.45H MICRO SD HEADER WITH D/C P | 5
18 | Capacitors | C20 | 1000 pF (500V) | CL31B102KGFNFNE | Samsung Electro-Mechanics | Capacitor | CAP CER 1000PF 500V X7R 1206 | 55 | 20
19 | Ceramic Capacitors |  | 0.047UF 50V | C0603C473K5RAC7867 | Kemet |  | CAP CER 0.047UF 50V X7R 0603 |  | 20
20 | Alum Capacitors | C24 | 10µF (35V) | ESC106M035AC3AA | Kemet | Capacitor | CAP ALUM 10UF 20% 35V RADIAL | 30
21 | Alum Capacitors | C25 | 47µF (35V) | UPS1V470MED | Nichicon | Capacitor | AP ALUM 47UF 20% 35V RADIAL | 10 | 2
22 | Discrete Semiconductor Products | D12 (SMA) |  | SMAZ16-13-F | Diodes Incorporated | D Zener 16V | DIODE ZENER 16V 1W SMA | 20
23 | Discrete Semiconductor Products | D13, D14 (SMA) | 1.7 V @ 1 A | US1K-TP | Micro Commercial Co | Diode | DIODE GEN PURP 800V 1A DO214AC | 20
24 | Discrete Semiconductor Products (https://www.digikey.com/en/products/category/discrete-semiconductor-products/19) | D15 (DO-214AC, SMA) |  | SMAZ20-13-F | Diodes Incorporated | D Zener 20V | DIODE ZENER 20V 1W SMA | 20
25 | Relays | DA18 (Solid State Relay) | 0 V ~ 60 V | LCA715STR | IXYS Integrated Circuits Division | LCA715STR | SSR RELAY SPST-NO 2.2A 0-60V | 10
26 | Circuit Protection | GDT1 | 420V 5KA | GTCA28-421M-R05 | Littelfuse Inc. | Gas Discharge Tube | GDT 420V 5KA 2 POLE | 10 | 20
27 | TVS - Varistors, MOVs (https://www.digikey.com/en/products/filter/tvs-varistors-movs/141) |  | AC 250 VAC; DC 320 VDC; Voltage min 351 | B72214S0251K101 | EPCOS Inc | Res Varistor | VARISTOR 390V 4.5KA DISC 14MM | 10
28 | AC DC Converters (https://www.digikey.com/en/products/filter/ac-dc-converters/923) | AC-DC | 12V - - - 5.83A 90 ~ 264 VAC Input | CBM70S120 | Cincon Electronics Co. LTD | AC-DC ($80.11) | AC/DC CONVERTER | 1
29 | OP Amps, Buffer Amps (https://www.digikey.com/en/products/filter/linear-amplifiers-instrumentation-op-amps-buffer-amps/687) | U8 |  | BA10358F-E2 | Rohm Semiconductor | BA10358F-E2 | IC OPAMP GP 2 CIRCUIT 8SOP | 10
30 | Integrated Circuits | U9 | Input 8 V ~ 50 V | VIPER22ASTR-E | STMicroelectronics | VIPER22 | IC OFFLINE SWITCH FLYBACK 8SOIC | 10
31 | Transistors MOSFET | Q10, Q11, Q12, Q13 |  | AUIRFZ24NS | Infineon Technologies |  | MOSFET N-CH 55V 17A DPAK | 20
32 | Temperature Sensors | Temperature Sensor Digital |  | MAX31820PARMCR+ | Maxim Integrated |  | SENSOR DIGITAL -55C-125C TO92-3 | 10
33 | Discrete Semiconductor Products | D11 |  | MB6S-TP | Micro Commercial Co | Diodes - Bridge Rectifiers (https://www.digikey.com/en/products/filter/diodes-bridge-rectifiers/299) | BRIDGE RECT 1P 600V 500MA MBS- | 20
34 | Filters | L4 |  | RN152-6-02-3M9 | Schaffner EMC Inc. | (EMC_POWER) | CMC 3.9MH 6A 2LN TH | 6
35 | PTC Resettable Fuses (https://www.digikey.com/en/products/filter/ptc-resettable-fuses/150) |  |  | LVR100S-240 | Littelfuse Inc. |  | PTC RESET FUSE 240V 1A RADIAL | 6
36 | TVS - Diodes | D7 |  | SMF05C.TCT | Semtech Corporation | (GSM) | TVS DIODE 5VWM 12.5VC SC70-6 | 16
37 | Connectors | J2 |  | 901-10112 | Amphenol RF | (GSM) | CONN SMA JACK STR 50 OHM PCB | 6
38 | Optoisolators - Transistor (https://www.digikey.com/en/products/filter/optoisolators-transistor-photovoltaic-output/903) |  |  | LTV-817S-TA1 | Lite-On Inc. |  | OPTOISOLATR 5KV TRANSISTOR 4-SMD | 20
39 | Diodes | DIODE SCHOTTKY |  | VS-30BQ040HM3/9AT | Vishay General | (EMC_POWER) | DIODE SCHOTTKY 40V 3A DO214AB | 10
40 | DC DC Switching Regulators (https://www.digikey.com/en/products/filter/pmic-voltage-regulators-dc-dc-switching-regulators/739) |  |  | LM2576-12WU | Microchip Technology |  | IC REG BUCK 12V 3A TO263-5 | 10
41 | Tvs Diode |  |  | ESDA6V1-5SC6Y | STMicroelectronics | (GPS) | 11.4V Clamp 7A (8/20µs) Ipp Tvs Diode Surface Mount SOT-23-6 | 10
42 | AC DC Converters (https://www.digikey.com/en/products/filter/ac-dc-converters/923) |  |  | EPM30-120-BE-0F0 | Astrodyne TDI |  | AC/DC ENCAPSULATED MED 12V, 30W | 4
43 | TVS - Diodes (https://www.digikey.com/en/products/filter/tvs-diodes/144) | (GSM) |  | ESDA6V1-5W6 | STMicroelectronics |  | TVS DIODE 3VWM SOT323-6 | 5
44 | Capacitors | C28, C29, C30 | 0.1UF 50V | C0603C104K5RAC7867 | Kemet | Capacitor, 0603, 50V | CAP CER 0.1UF 50V X7R 060 | 40 | 120
45 | Chip Resistor | R2, R4 | RES 1K OHM 5% 1/10W 0603 | RMCF0603JT1K00 | Panasonic | Res1 | Chip Resistor | 40
46 | Chip Resistor | R3 | 2.2K OHM | ERJ-3GEYJ222V | Panasonic | Res1 | RES SMD 2.2K OHM 5% 1/10W 0603 | 40
47 | Ceramic Capacitors | C33, C35 | CAP CER 0.1UF 50V X7R 0603 | CL10B104JB8NNNC | Samsung | Capacitor | Cap Ceramic 0.1uF 50VDC X7R 10% SMD 0603 Paper T/R | 40
48 | Ceramic Capacitors |  | 12PF 50V | C0603C120J5GAC7867 | Kemet |  | CAP CER 12PF 50V C0G/NP0 0603 | 40
49 | Ceramic Capacitors |  | 18PF 50V | C0603C180K5GAC7867 | Kemet |  | CAP CER 18PF 50V C0G/NP0 0603 | 40
50 | Ceramic Capacitors | C14 | 25V, 2.2uF | CL21A225KAFNNNG | Samsung | Capacitor | Chip Capacitor Nonpolar | 40
51 | Ceramic Capacitors | C25 | 50V, 10nF | CL10B103KB8WPNC | Samsung | Capacitor | Chip Capacitor Nonpolar | 40
52 | Resistor | R6, R8, R9 | 330 OHM | ERJ-3EKF3300V | Panasonic | Res2 | RES SMD 330 OHM 1% 1/10W 0603 | 50 | 40
53 | RES SMD | R12 | 22 OHM | RMCF0603FT22R0 | Stackpole Electronics Inc |  | RES 22 OHM 1% 1/10W 0603 | 80
2 | Resistor |  | 0 OHM | RC0603JR-070RL | YAGEO |  | RES 0 OHM JUMPER 1/10W 0603 | 40
55 | Capacitors | C31 | 22PF 50V | C0603C220K5GAC7867 | Kemet | Cap | CAP CER 22PF 50V C0G/NP0 0603 | 40
56 | Resistors | R39 | 10K OHM | RCG060310K0JNEA | Vishay Dale | Res1 | RES SMD 10K OHM 5% 1/10W 0603 | 40 | 80 | ERJ-3GEYJ103V
57 | Resistors | R73, R74, R75, R76, R77 (75 V) | 47K OHM | RMCF0603FT47K0 | Stackpole Electronics Inc | Res1 | RES 47K OHM 1% 1/10W 0603 | 40
58 | Alum Capacitors | C19 | 680µF (35V) | EEU-FM1V681B | Panasonic Electronic Components | Capacitor | CAP ALUM 680UF 20% 35V RADIAL | 40
59 | Filters | L3, L6 (0.236" Dia (5.99mm) 5A | 900 OHM | FB20022-4B-RC | Bourns Inc. | Inductor | FERRITE BEAD 900 OHM RADIAL 1LN | 20
60 | Resistors | R66 | 3.83K OHM | RC0603FR-073K83L | Stackpole Electronics Inc. | Res3 | RES 3.83K OHM 1% 1/10W 0603 | 40
61 | Resistors | R67 | 10K OHM | RMCF0603FT10K0 | Stackpole Electronics Inc. | Res4 | RES 10K OHM 1% 1/10W 0603 | 40
62 | Resistors | R68 | 3.6K OHM | RMCF0603JT3K60 | Stackpole Electronics Inc. | Res5 | RES 3.6K OHM 5% 1/10W 0603 | 40
63 | Resistors | R69 | 1.96K OHM | RMCF0603FT1K96 | Stackpole Electronics Inc. | Res6 | RES 1.96K OHM 1% 1/10W 0603 | 40
64 | Resistors | R70 | 1.5K OHM | RMCF0603FT1K50 | Stackpole Electronics Inc. | Res7 | RES 1.5K OHM 1% 1/10W 0603 | 40 | 60
65 | Resistors | R38 | 2.2K OHM | ERJ-3GEYJ222V | Panasonic | Res1 | RES SMD 2.2K OHM 5% 1/10W 0603 | 48 | 60
66 | Resistors | R63, R64 | 330K OHM | RC0603FR-07330KL | Yageo | Res1 | RES 330K OHM 1% 1/8W 0603 | 40
67 | Resistors | R65 | 16.2K | RC0805FR-0716K2L | Yageo |  | RES 16.2K OHM 1% 1/8W 0603 | 40 | 80
68 | Ceramic Capacitors (https://www.digikey.com/en/products/filter/ceramic-capacitors/60) |  | 0.1UF 50V | C0603C104K5RAC7013 | KEMET |  | CAP CER 0.1UF 50V X7R 0603 | 40

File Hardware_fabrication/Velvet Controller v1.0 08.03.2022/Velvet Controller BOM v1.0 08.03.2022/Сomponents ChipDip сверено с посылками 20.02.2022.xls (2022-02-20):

 |  | Доп список ChipDip
# | Категория | Артикул | Модель, серия, наименование | Производитель | Описание | Количество
1 | Transistors MOSFET | 8006236454 | AUIRFR4292TRL | Infineon Technologies | Полупроводниковые приборы\Дискретные полупроводниковые приборы\Транзисторы\МОП-транзистор | 10
2 | Transistors MOSFET | 8000734823 | IRFR430APBF | Vishay | Одиночные MOSFET транзисторы корпус: D-Pak, инфо: Полевой транзистор, N-канальный, 500 В, 5 А, 110Вт | 10
3 | Diodes | 9000307000 | 1N5819HW-7-F | Multicomp | Диод Шоттки 40В 1А [SOD-123] | 10
4 | (ICs) Linear - Amplifiers | 8001887138 | AD8541ARTZ-REEL | Analog Devices Inc. | Операционный усилитель | 10
5 | Integrated Circuits | 8002870206 | LM2596S-12/NOPB | Texas Instruments | DC-DC Преобразователи | 20
6 | Ceramic Capacitor | 8601925538 | CL31B103KGFNNNE | Samsung Electro-Mechanics | Конденсаторы керамические SMD. 10000PF, 500V, 1206 | 20 | 30
7 | Inductor | 8005898772 | VLS252012T-2R2M1R3 | TDK Corporation | Inductors, Coils, Chokes\Fixed Inductors, 2.2ВµH Shielded Wirewound Inductor 1.58A 126mOhm Max Nonstandard | 20
8 | Ceramic Capacitor | 8000499436 | CL10B104KB8NNNС | Samsung Electro | керам ЧИП конд 0603 X7R 0.1мкФ +10% 50В | 100 | 300 | CL10B104KB8NNNC
9 | МОП-транзистор, P Канал | 8000094149 (https://www.chipdip.ru/product/si3493ddv-t1-ge3) | Vishay Siliconix | МОП-транзистор, P Канал, 20 В, 8 А | SI3493DDV-T1-GE3 (VT1) | 10
10 | 40В 1А/25А | 9000442595 (https://www.chipdip.ru/product/1n5819-2) | onsemi | Диод Шоттки | 1N5819 (D10) | 10 | 20
11 | 3.3V | 8007934653 (https://www.chipdip.ru/product0/8007934653) | ON Semiconductor (https://www.chipdip.ru/catalog/ic-stabilizers?p.0=ON+Semiconductor) | Стабилизаторы линейные | LM1117MPX-33NOPB, 3.3V (U10) | 10 | 30
12 | TVS LXES15AAA1-153 | 8001945444 (https://www.chipdip.ru/product1/8001945444?from=suggest_product) | Murata | Корпус DFN2 0402 | (для GSM) | 5
13 | 'электролитический конденсатор | 9000536858 |  | Nichicon Corp. (https://www.chipdip.ru/manufacturer/nichicon) | электролитический конденсатор, Radial Can - SMD, 470 мкФ, 35 В, | 20
14 | 'электролитический конденсатор | 9000471195 |  | Panasonic (https://www.chipdip.ru/manufacturer/panasonic) | электролитический конденсатор, Radial Can - SMD, 330 мкФ, 35 В | 20
15 | PTC Resettable Fuses (https://www.digikey.com/en/products/filter/ptc-resettable-fuses/150) | 8002397953 |  | Bel Circuit Protection (https://www.chipdip.ru/manufacturer/bel-circuit-protecti) | PTC Resettable Fuse 1.85A(hold) 3.7A(trip) 33VDC 100A 1.5W 2.5s 0.04Ohm | 10
16 | Fixed Inductors (https://www.digikey.com/en/products/filter/fixed-inductors/71) | SRR1208-330YL, 33 мкГн |  | Bourns (https://www.chipdip.ru/manufacturer/bourns) | SRR1208-330YL, 33 мкГн, Индуктивность SMD | 10 | 10
17 | Резисторы | 8001788944 |  | Yageo (https://www.chipdip.ru/manufacturer/yageo) | Резисторы, 3 кОм, Корпус SMD 0603 | 40 |  | CR-03JL7
18 | DC/DC преобразователи | 8001927708 | LM2575D2T-5R4G | ON Semiconductor (https://www.chipdip.ru/manufacturer/on-semiconductor) | импульсные TO2636 | 20
19 | Voltage Regulators | LM1117MPX-3.3/NOPB | LM1117MPX-3.3/NOPB | Texas Instruments (https://www.chipdip.ru/manufacturer/texas-instruments) | стабилизатор напряжения | 20
20 | Pin Header | 61300411121 | 61300411121 | Wurth Elektronik (https://www.chipdip.ru/manufacturer/wurth) | вертикальный 2.54 мм, 1 ряд(-ов), 4 контакт(-ов) | 10 | 100
21 | Микроконтроллер 32-Бит, | STM32F407VGT6 |  | ST Microelectronics (https://www.chipdip.ru/manufacturer/st-microelectronics) | Cortex-M4 + FPU, 168МГц, 1МБ Flash, LQFP-100 | 20
22 | Кварц | ABM3-8.000MHZ-D2Y-T | ABM3 | Abracon (https://www.chipdip.ru/manufacturer/abracon) | Мини керамический кристалл | 15 | 12
23 | Kерамические конденсаторы | 8006229280 | C3216X7T2W104K160AA | TDK (TDK-Lambda) (https://www.chipdip.ru/manufacturer/tdk) | 1206 450V 0.1uF X7T 10% T: 1.6mm | 50
24 | Capacitance | 8002013639 | EKXG401ELL470ML25S | Nippon (https://www.chipdip.ru/manufacturer/nippon) | 47uF, 400V, Aluminum Electrolytic Capacitors | 15
25 | Fixed Inductors (https://www.digikey.com/en/products/filter/fixed-inductors/71) | 8004156451 | SRR1260-221K | Bourns (https://www.chipdip.ru/manufacturer/bourns) | 220ВµH Shielded Wirewound Inductor 1.38A 380mOhm | 20 | 40
26 | Fixed Inductors (https://www.digikey.com/en/products/filter/fixed-inductors/71) | 8003102635 | RLB1314-471KL | Bourns (https://www.chipdip.ru/manufacturer/bourns) | 470ВµH Unshielded Wirewound Inductor 460mA 510mOhm | 20
27 | электролитический конденсатор | 9000471195 | EEE1VA331P | Panasonic (https://www.chipdip.ru/manufacturer/panasonic) | Can - SMD, 330 мкФ, 35 В, Серия S | 20
28 | Часы реального времени | 8005193543 | DS3231M+TRL | Maxim Integrated Products (https://www.chipdip.ru/manufacturer/maxim) | Часы реального времени | 10
29 | МОП-транзистор | SI3493DDV-T1-GE3 | SI3493DDV-T1-GE3 | Vishay (https://www.chipdip.ru/manufacturer/vishay) | МОП-транзистор, P Канал, 20 В, 8 А, 0.02 Ом, TSOP | 10
30 | Конденсатор | T491A106M004AT | T491A106M004AT | Kemet Electronics (https://www.chipdip.ru/manufacturer/kemet) | 10UF, 4V, CASE A | 40

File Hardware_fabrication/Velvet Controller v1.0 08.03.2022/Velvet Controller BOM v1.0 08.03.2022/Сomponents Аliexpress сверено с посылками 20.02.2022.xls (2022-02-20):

Для закупа с АлиExpress
Проект
Дата создания
# | Category | Designator | Voltage | Сайт для покупки | Manufacturer | Comment | Description | Quantity
1 | Led | D3-D5 |  | https://aliexpress.ru/item/32288219403.html?sku_id=53752783397 | Vishay Lite-On | LED | Led 0603 | 20 |  | MC
2 | Header | P1 |  | https://aliexpress.ru/item/4000044912363.html?spm=a2g2w.productlist.0.0.73f49705Nagvf2 |  | SWD | Header, 6-Pin | 6
3 | Антенна | A2 |  | https://store.rakwireless.com/products/lora-antenna | RAK | 2dBi SubG Antenna | 2dBi SubG Antenna | 10
4 | Антенна | A3 |  | https://store.rakwireless.com/apps/omega-search/?options%5Bprefix%5D=last&q=3dBi+SubG+Antenna | RAK | 3dBi SubG Antenna | 3dBi SubG Antenna | 10
5 | Антенна | A4 |  | https://aliexpress.ru/item/33039586869.html?spm=a2g2w.productlist.0.0.49ed4386NCs4tg | EBYTE | TX915-FPC-4510 | TX915-FPC-4510 868~930MHz adhesive antenna | 10 |  | LoRA
6 | LoRa модуль | U5 |  | https://store.rakwireless.com/products/wisduo-lpwan-module-rak3172?variant=40014759297222 | RAK | RAK3172 | LPWAN Module | 10 | 15
7 | Capacitors | C18, C26 | 100n (50V) | https://aliexpress.ru/item/32882507397.html?sku_id=65555187576 | Samsung Electro-Mechanics | Capacitor | CAP CER 0.1UF 50V X7R 0603 | 10
8 | Capacitors | C21 | 10000 pF (500V) | https://aliexpress.ru/item/32880444134.html?spm=a2g2w.productlist.0.0.3a4423927yBLil | Samsung Electro-Mechanics | Capacitor | CAP CER 10000PF 500V X7R 1206 | 10
9 | Inductors, Coils, Chokes | L1 | 2.2µH | https://aliexpress.ru/item/1005002608240827.html?sku_id=12000021374738657 | TDK Corporation |  | FIXED IND 2.2UH 1.3A 155MOHM SMD | 20 |  | EMC_POWER
10 | 1 | BAT1 |  | https://aliexpress.ru/item/33003345552.html?sku_id=67044621657 | Altium Limited |  | Multicell Battery | 5
11 | Temper. Sensors | Temperature Sensor Digital |  | https://aliexpress.ru/item/1005001906657940.html?spm=a2g2w.productlist.0.0.210344d5Es2iKT | Maxim Integrated | В корпусе из нержав |  | 4 |  | MOSFET
12 | RFID считыватель |  |  | https://aliexpress.ru/item/32848525319.html?item_id=32848525319&sku_id=65317543739 | CHAFON |  | CF-MU904 | 5
13 | RFID антенна |  |  | https://aliexpress.ru/item/32643791108.html?scm_id=1007.13339.169870.0&scm-url=1007.13339.169870.0 |  |  |  | 5

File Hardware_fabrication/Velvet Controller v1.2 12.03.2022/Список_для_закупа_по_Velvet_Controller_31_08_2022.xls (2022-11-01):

Для дополнительного закупа от 31 августа 2022
Проект
Дата создания
# | Наименование | Manufacturer Product Number | Voltage | Сайт для покупки | Manufacturer | Quantity
1 | Электролитический конденсатор. SMD. Radial Can - SMD | 35TZV330M10X10.5 | 330 мкФ, 35 В | Digi-Key (https://www.digikey.com/en/products/detail/rubycon/35PJV180MVB8X10-5/15293848) |  | 50
2 | Электролитический конденсатор. SMD. Radial Can - SMD | EEE-TC1V391UV | 390 мкФ, 35 В | Digi-Key (http://www.digikey.com/) | Panasonic El | 50
3 | 2-позиционная клеммная колодка | EBAFA-02-D |  | Digi-Key (https://www.digikey.com/en/products/detail/phoenix-contact/1715721/260631?s=N4IgTCBcDaIIwHY4FYFjiAugXyA) | Adam Tech | 100
4 | USB - micro B USB 2.0 Receptacle Connector 5 Position Through Hole | USB3145-30-1-A |  | Digi-Key (https://www.digikey.com/en/products/detail/gct/USB3145-30-1-A/9859647) | GCT | 10
5 | Конденсатор керамика. Корпус 0603 | 06035A330FAT2A | 33pF, 50 V | Digi-Key (https://www.digikey.com/en/products/detail/kyocera-avx/06035A330FAT2A/1599793) | KYOCERA AVX | 50
6 | Конденсатор керамика. Корпус 0603 | 06035A100JAT2A | 10pF, 35 V | Digi-Key (https://www.digikey.com/en/products/detail/kyocera-avx/06035A100JAT2A/563273) | KYOCERA AVX | 50
8 | МОП-транзистор P-CHANNEL, 6-TSOP | SI3429EDV-T1-GE3 | 20 V 8A (3,000 In Stock) | https://www.digikey.com/en/products/detail/vishay-siliconix/SI3429EDV-T1-GE3/6595032 | Вишай Силиконикс | 20
9 | Предохранитель самовостанавливающийся | 0ZCF0185FF2C | 250 V 3 A | Digi-Key (https://www.digikey.com/en/products/detail/littelfuse-inc/TRF600-150-2/1114125) | Littelfuse Inc. | 10
10 | Держатель для SD карты. CONN MICRO SD CARD | 5025700893 |  | Digi-Key (https://www.digikey.com/en/products/detail/molex/5025700893/1866792) | Molex | 10
11 | DC-DC преобразователь LM2596, корпус TO-263-5 | LM2575WU | 1.23V 1 Output 1A (300 In Stock) | https://www.digikey.com/en/products/detail/microchip-technology/LM2575WU/1027667 | Microchip Technology | 20
12 | DC-DC преобразователь AP1501-50K5G-13, корпус TO-263-6 | AP1501-50K5G-13 | 5V 1 Output 3A (1,690 In Stock) | https://www.digikey.com/en/products/detail/diodes-incorporated/AP1501-50K5G-13/4249616 | Diodes Incorporated | 20
13 | Двухсторонний кабель с разъемами RP-SMA MHF4 Female (IPEX4) | CB1.13-IPX4L-SARF3GT-4IN |  | Digi-Key | Lighthorse Techn | 10
14 | Модуль RTC DS3231M | Артикул 13870 |  | https://radiomart.kz/moduli-vremeni/3870-modul-rtc-ds3231-dlya-raspberry-pi-8537109100.html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 |  | 10

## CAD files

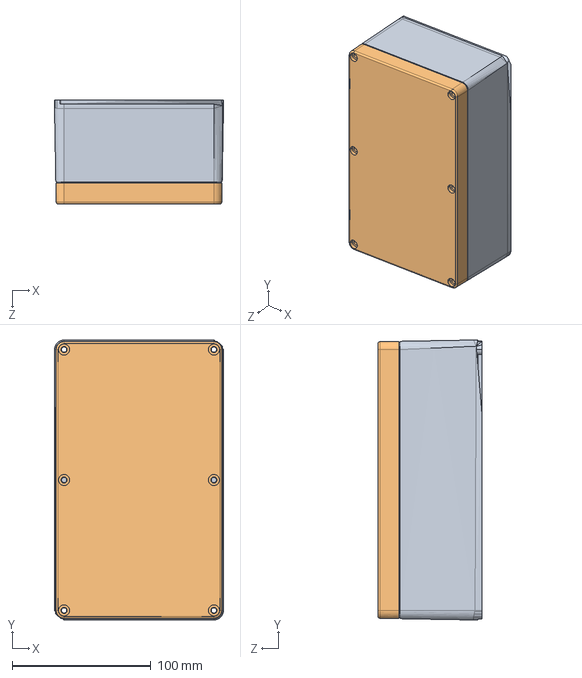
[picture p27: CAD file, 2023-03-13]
3D/G373C/G373C.SLDASM
121.9 x 201.9 x 75.0 mm
G269MF-IP67 G373MF-IP67-BASE^g2691mf-ip67-g3735mf-ip67(2)_G373C
G269MF-IP67 G373MF-IP67-COVER^g2691mf-ip67-g3735mf-ip67(2)_G373C

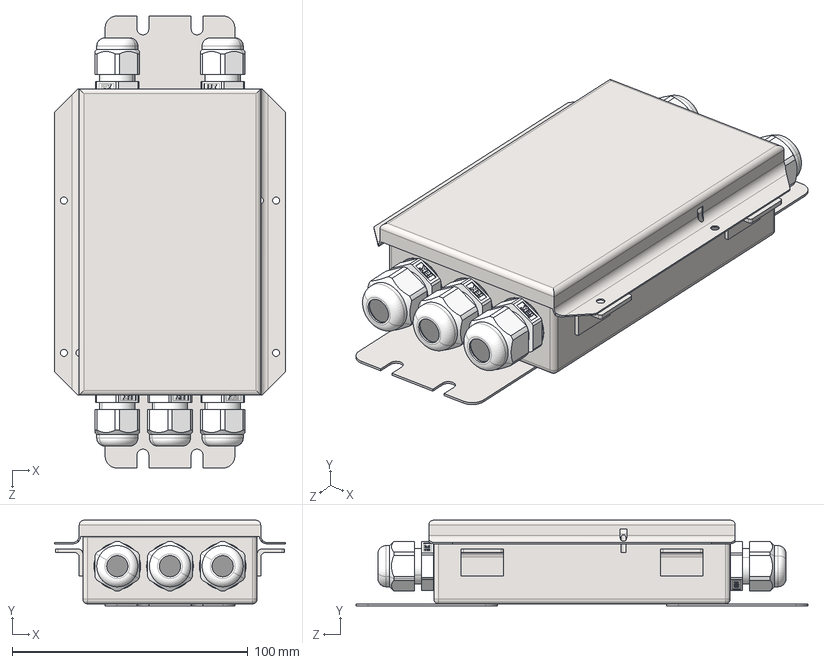
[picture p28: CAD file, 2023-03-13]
3D/Балансир/step/Балансир_MAIN.STEP
98.0 x 36.3 x 191.7 mm
扻豵鵨
Êðûøêà
Ñàëüíèê PG9 äèàìåòð ïðîâîäíèêà 6-7ìì IP54 ÈÝÊ x 5
Ïëàòà áàëàíñèðà
terminal_blocks_a-tb500t202sb.stp x 15
Trimpot_3296W.step x 4

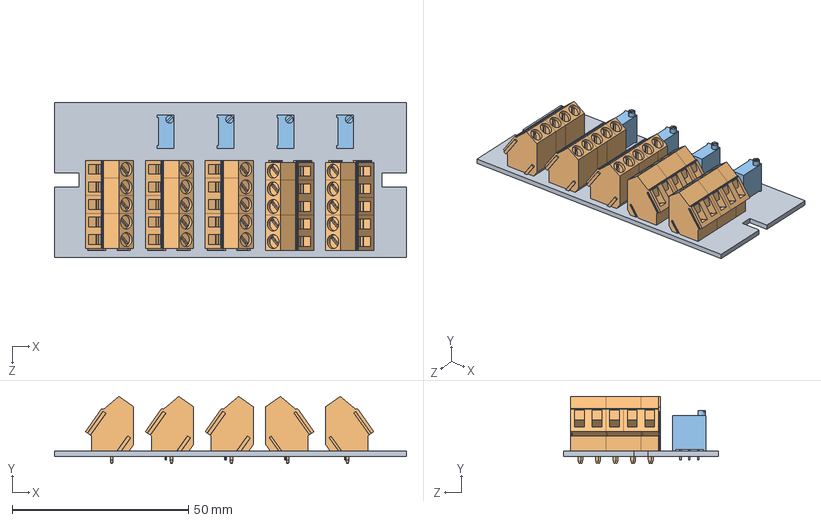
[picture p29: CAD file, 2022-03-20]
3D/Балансир/Плата балансира.SLDASM
100.0 x 19.1 x 44.0 mm
Плата балансира
terminal_blocks_a-tb500t202sb.stp x 15
Trimpot_3296W.step x 4

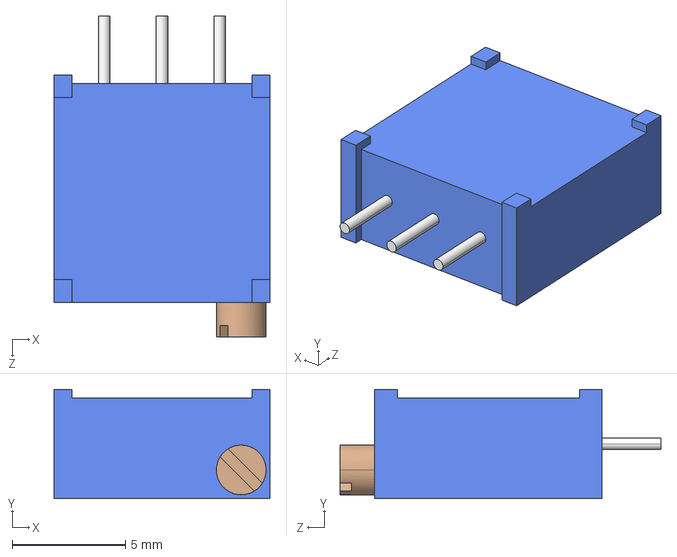
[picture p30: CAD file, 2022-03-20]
3D/Балансир/Electrical Parts/Trimpot_3296W.STEP
9.53 x 4.83 x 14.1 mm

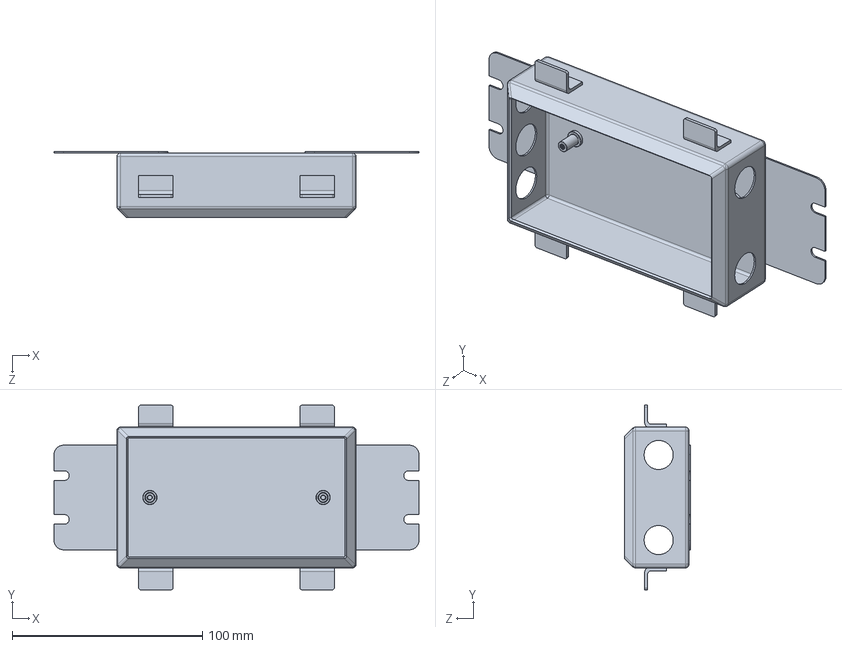
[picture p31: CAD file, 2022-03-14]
3D/Балансир/Mechanical Parts/Корпус.SLDPRT
191.8 x 97.0 x 34.8 mm

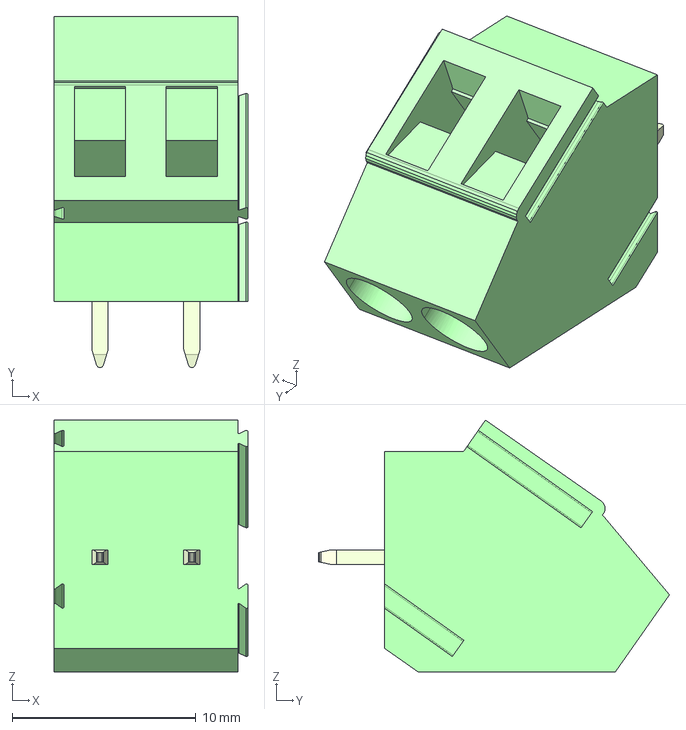
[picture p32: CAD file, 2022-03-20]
3D/Балансир/Electrical Parts/terminal_blocks_a-tb500t202sb.stp
10.6 x 19.1 x 13.7 mm

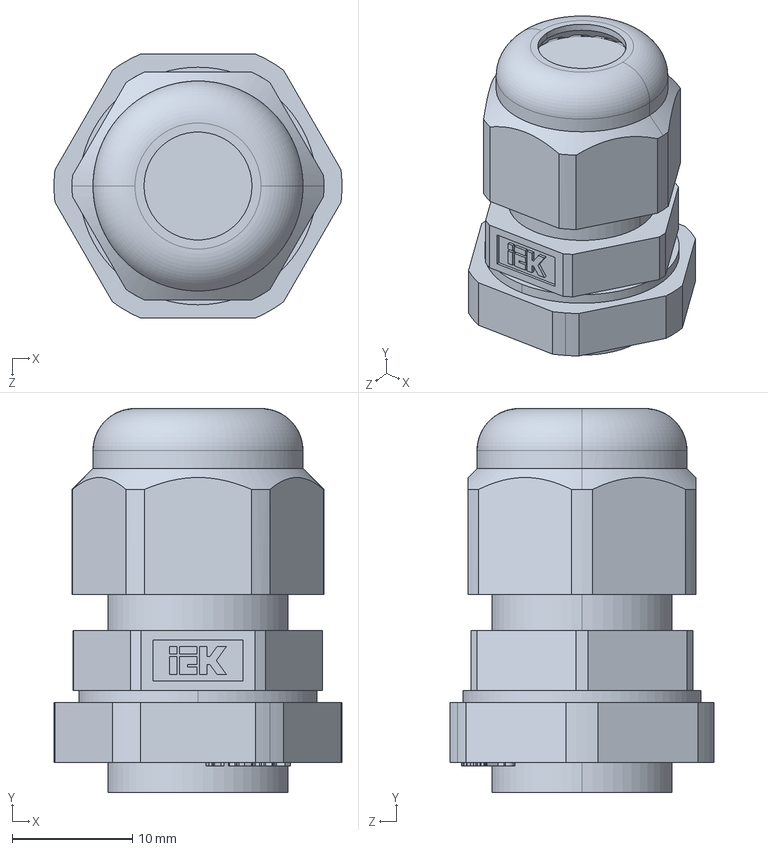
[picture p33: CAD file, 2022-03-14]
3D/Балансир/Mechanical Parts/Сальник PG9 диаметр проводника 6-7мм IP54 ИЭК.SLDPRT
24.0 x 32.0 x 22.0 mm

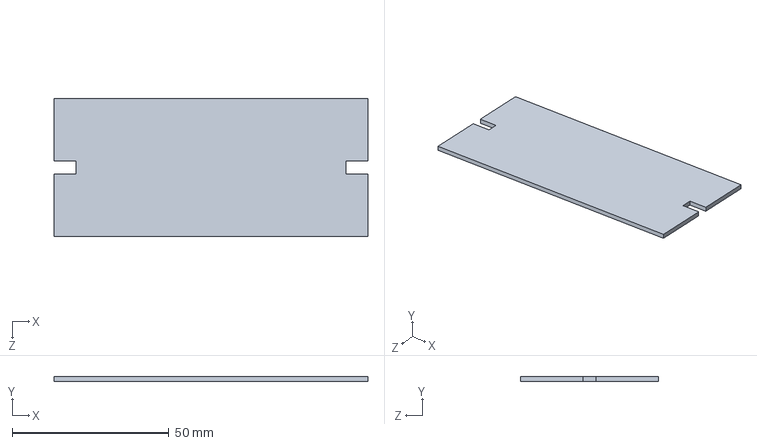
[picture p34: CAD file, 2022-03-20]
3D/Балансир/Electrical Parts/Плата балансира.SLDPRT
100.0 x 1.60 x 44.0 mm

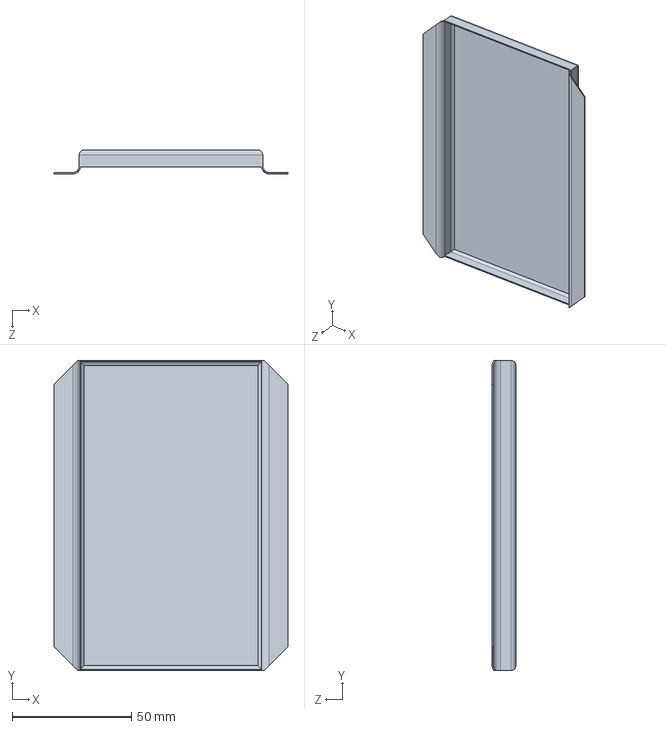
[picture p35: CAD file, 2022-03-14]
3D/Балансир/Mechanical Parts/Крышка.SLDPRT
98.0 x 130.0 x 10.0 mm

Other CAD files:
3D/Балансир/Балансир_MAIN.SLDASM

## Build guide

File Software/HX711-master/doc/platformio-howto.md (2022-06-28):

# PlatformIO howto

https://platformio.org/

List installed platforms

    platformio platform list

List available boards

    platformio boards

Run specific build

    platformio ci --board=megaatmega2560 --lib="." examples/HX711_full_example

Run specific environment

    platformio run --environment lopy4

Build all environments

    platformio run

"Make clean" for all environments

    platformio run -t clean

Dump specific build environment

    platformio run --environment lopy4 --target envdump

See slot `CPPDEFINES`.

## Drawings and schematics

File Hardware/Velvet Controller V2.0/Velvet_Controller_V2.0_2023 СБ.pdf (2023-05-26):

### DA2p

VD19io | VD20io | VD21io | VD22io

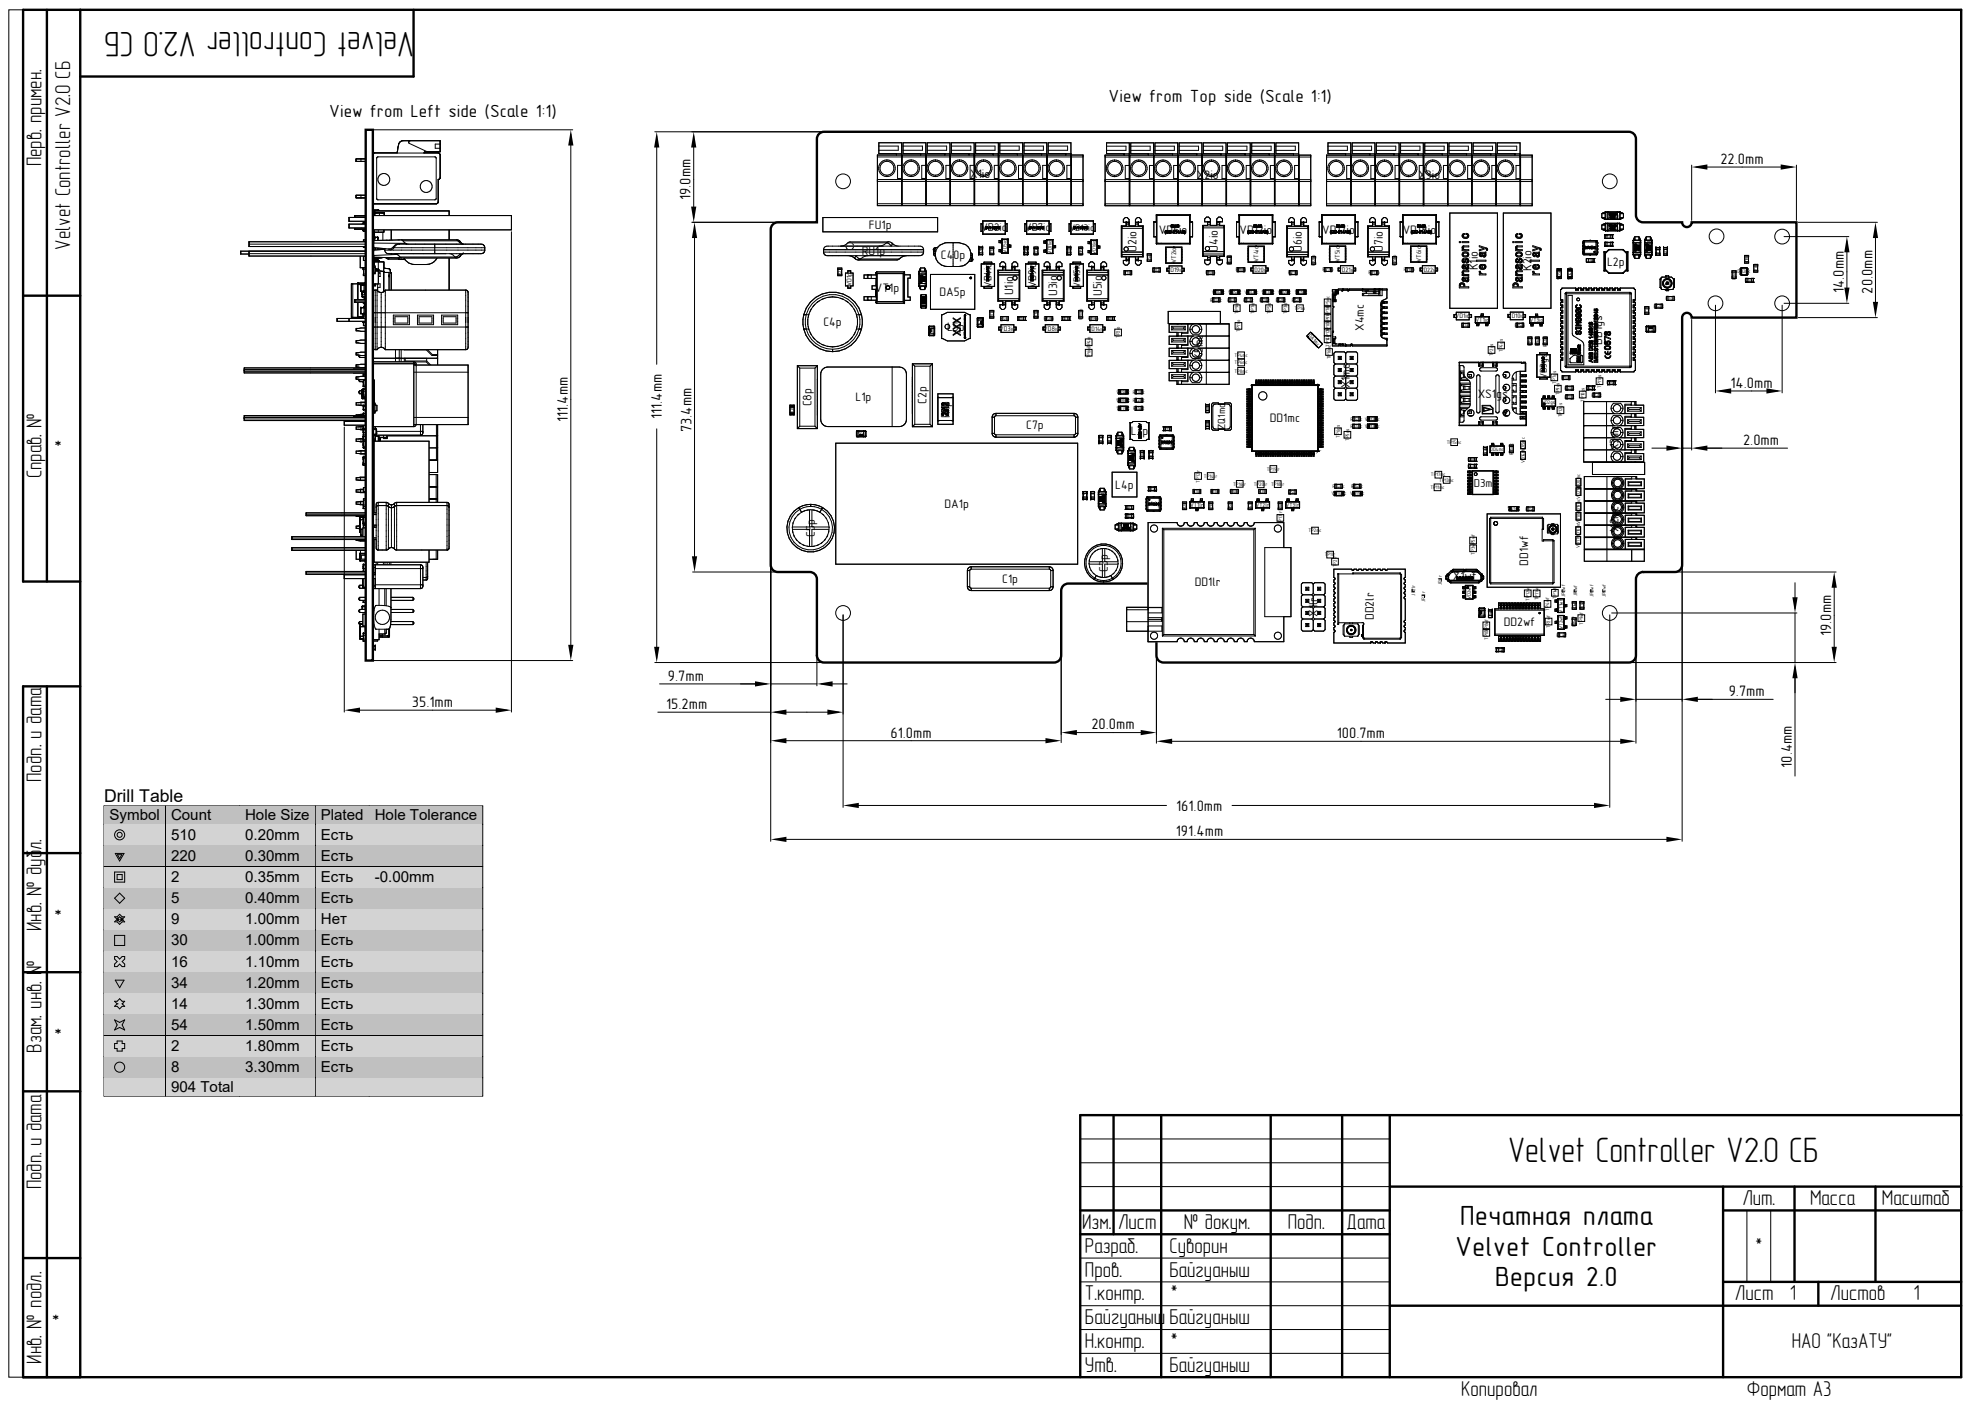
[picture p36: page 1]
R24io R⁹lr; VD⁹io; Пров.; Байгуаныш; Копировал; Утв.; Н.контр.; Т.контр.; Лист; № докум.; Разраб.; Изм.; Подп. Дата; Формат А3; Листов; Лит.; Масса Масштаб; Суворин; НАО "КазАТУ"; Байгуаныш Байгуаныш; Symbol Count 510 220 2 5 9 30 16 34 14 54 2 8 904 Total; Hole Size 0.20mm 0.30mm 0.35mm 0.40mm 1.00mm 1.00mm 1.10mm 1.20mm 1.30mm 1.50mm 1.80mm 3.30mm; Plated Есть Есть Есть Есть Нет Есть Есть Есть Есть Есть Есть Есть; Hole Tolerance; Drill Table; Печатная плата Velvet Controller Версия 2.0

Инв. № подл. Инв. № дубл. Подп. и дата Взам. инв. № Подп. и дата Перв. примен. Справ. №

Velvet Controller V2.0 СБ

View from Top side (Scale 1:1)

View from Left side (Scale 1:1)

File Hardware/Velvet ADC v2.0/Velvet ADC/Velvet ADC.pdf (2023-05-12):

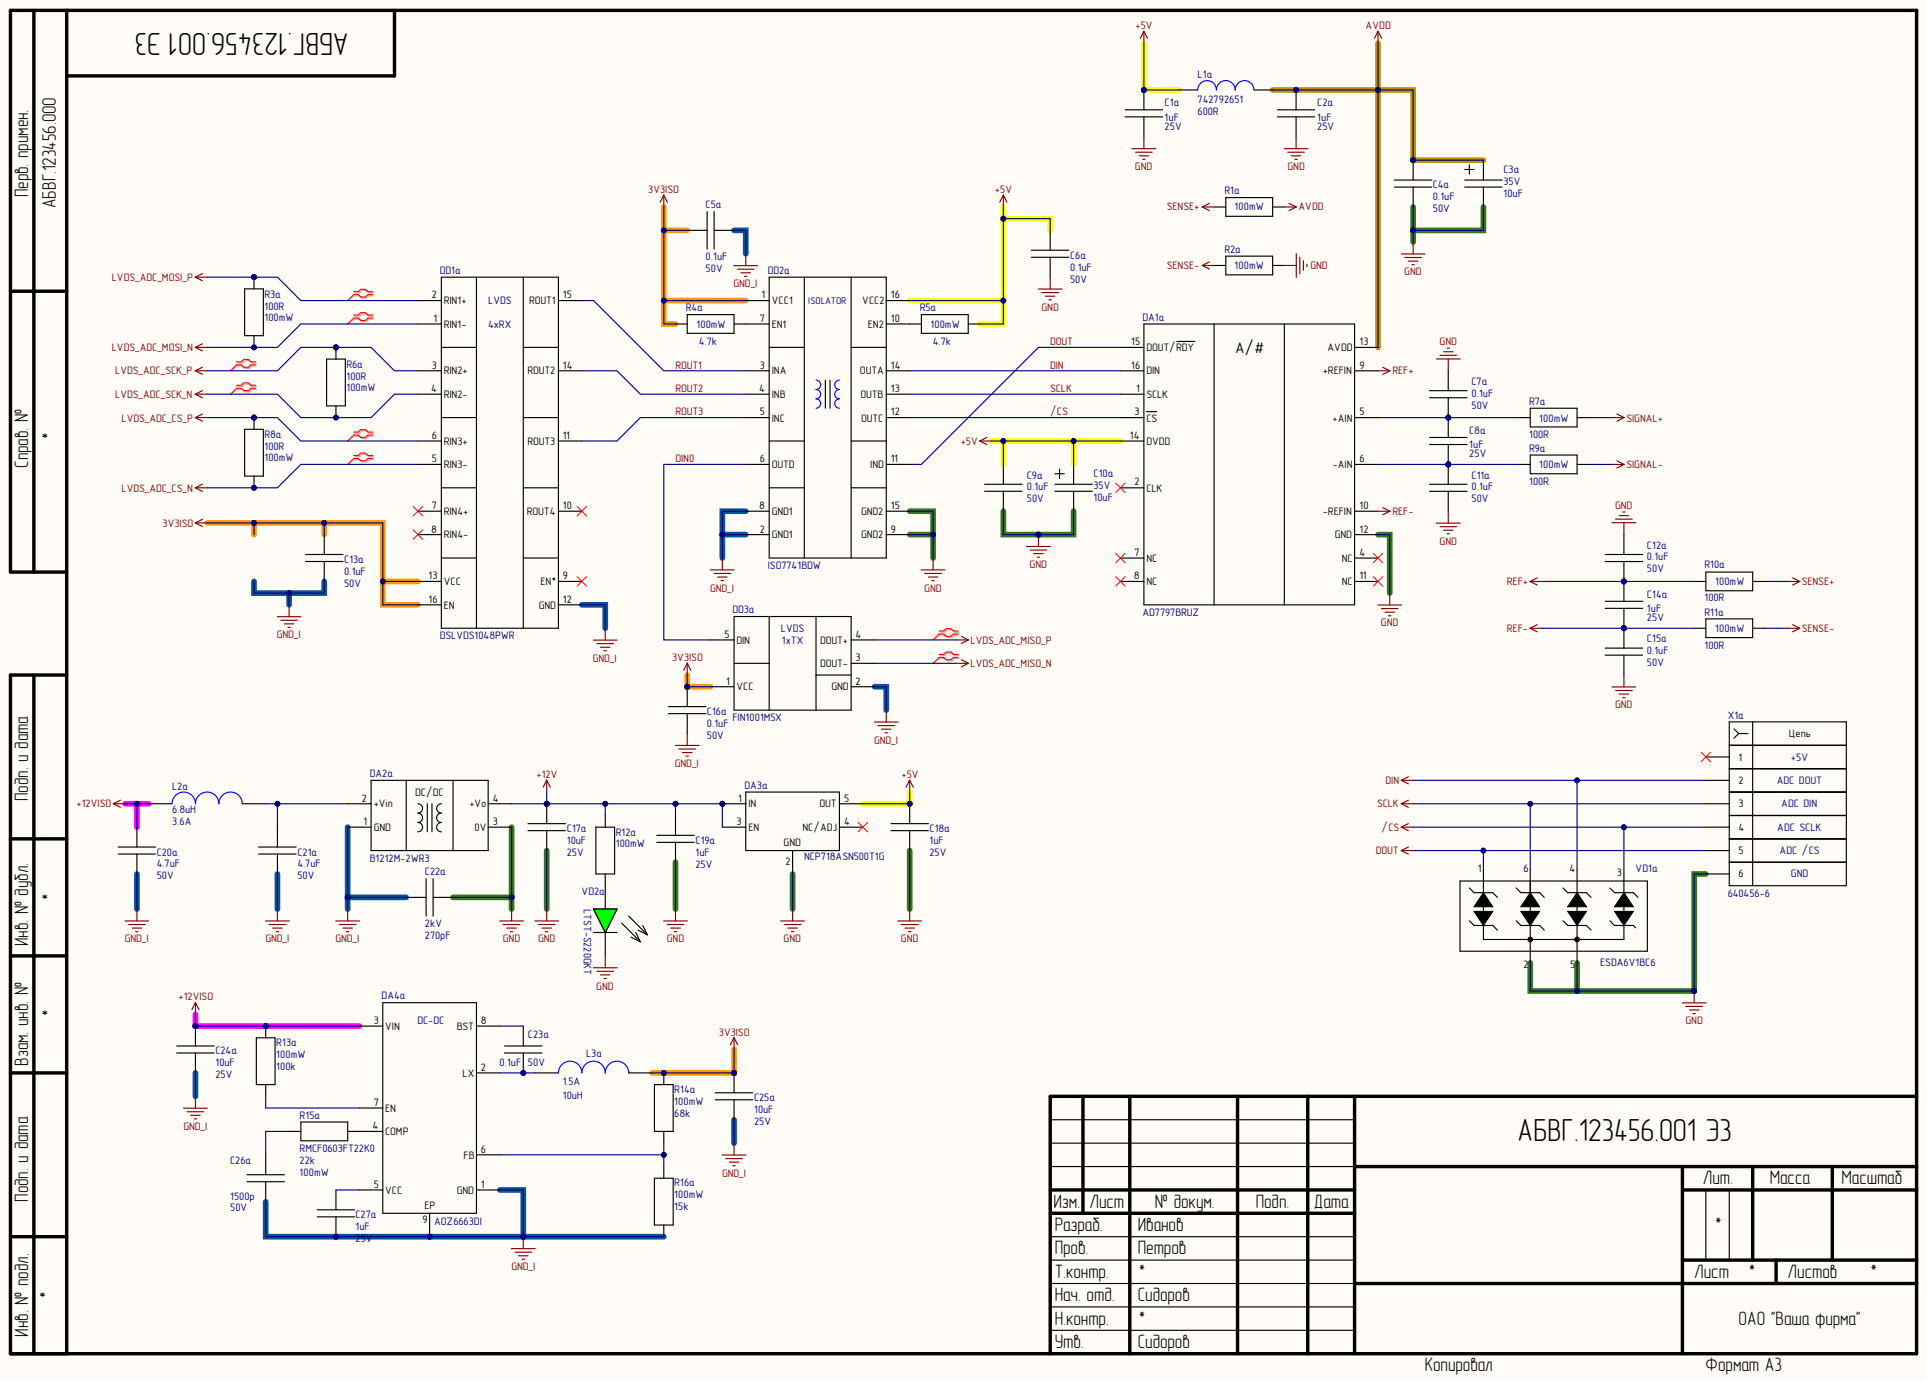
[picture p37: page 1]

Инв. № подл. Инв. № дубл. Подп. и дата Взам. инв. № Подп. и дата Перв. примен. Справ. №

Цепь

2 | ADC DOUT

4 | ADC SCLK

5 | ADC /CS

6 | GND

АБВГ.123456.001 Э3

Лит. | Масса | Масштаб

Нач. отд. | Сидоров | ОАО "Ваша фирма"
Н.контр. | *
Утв. | Сидоров

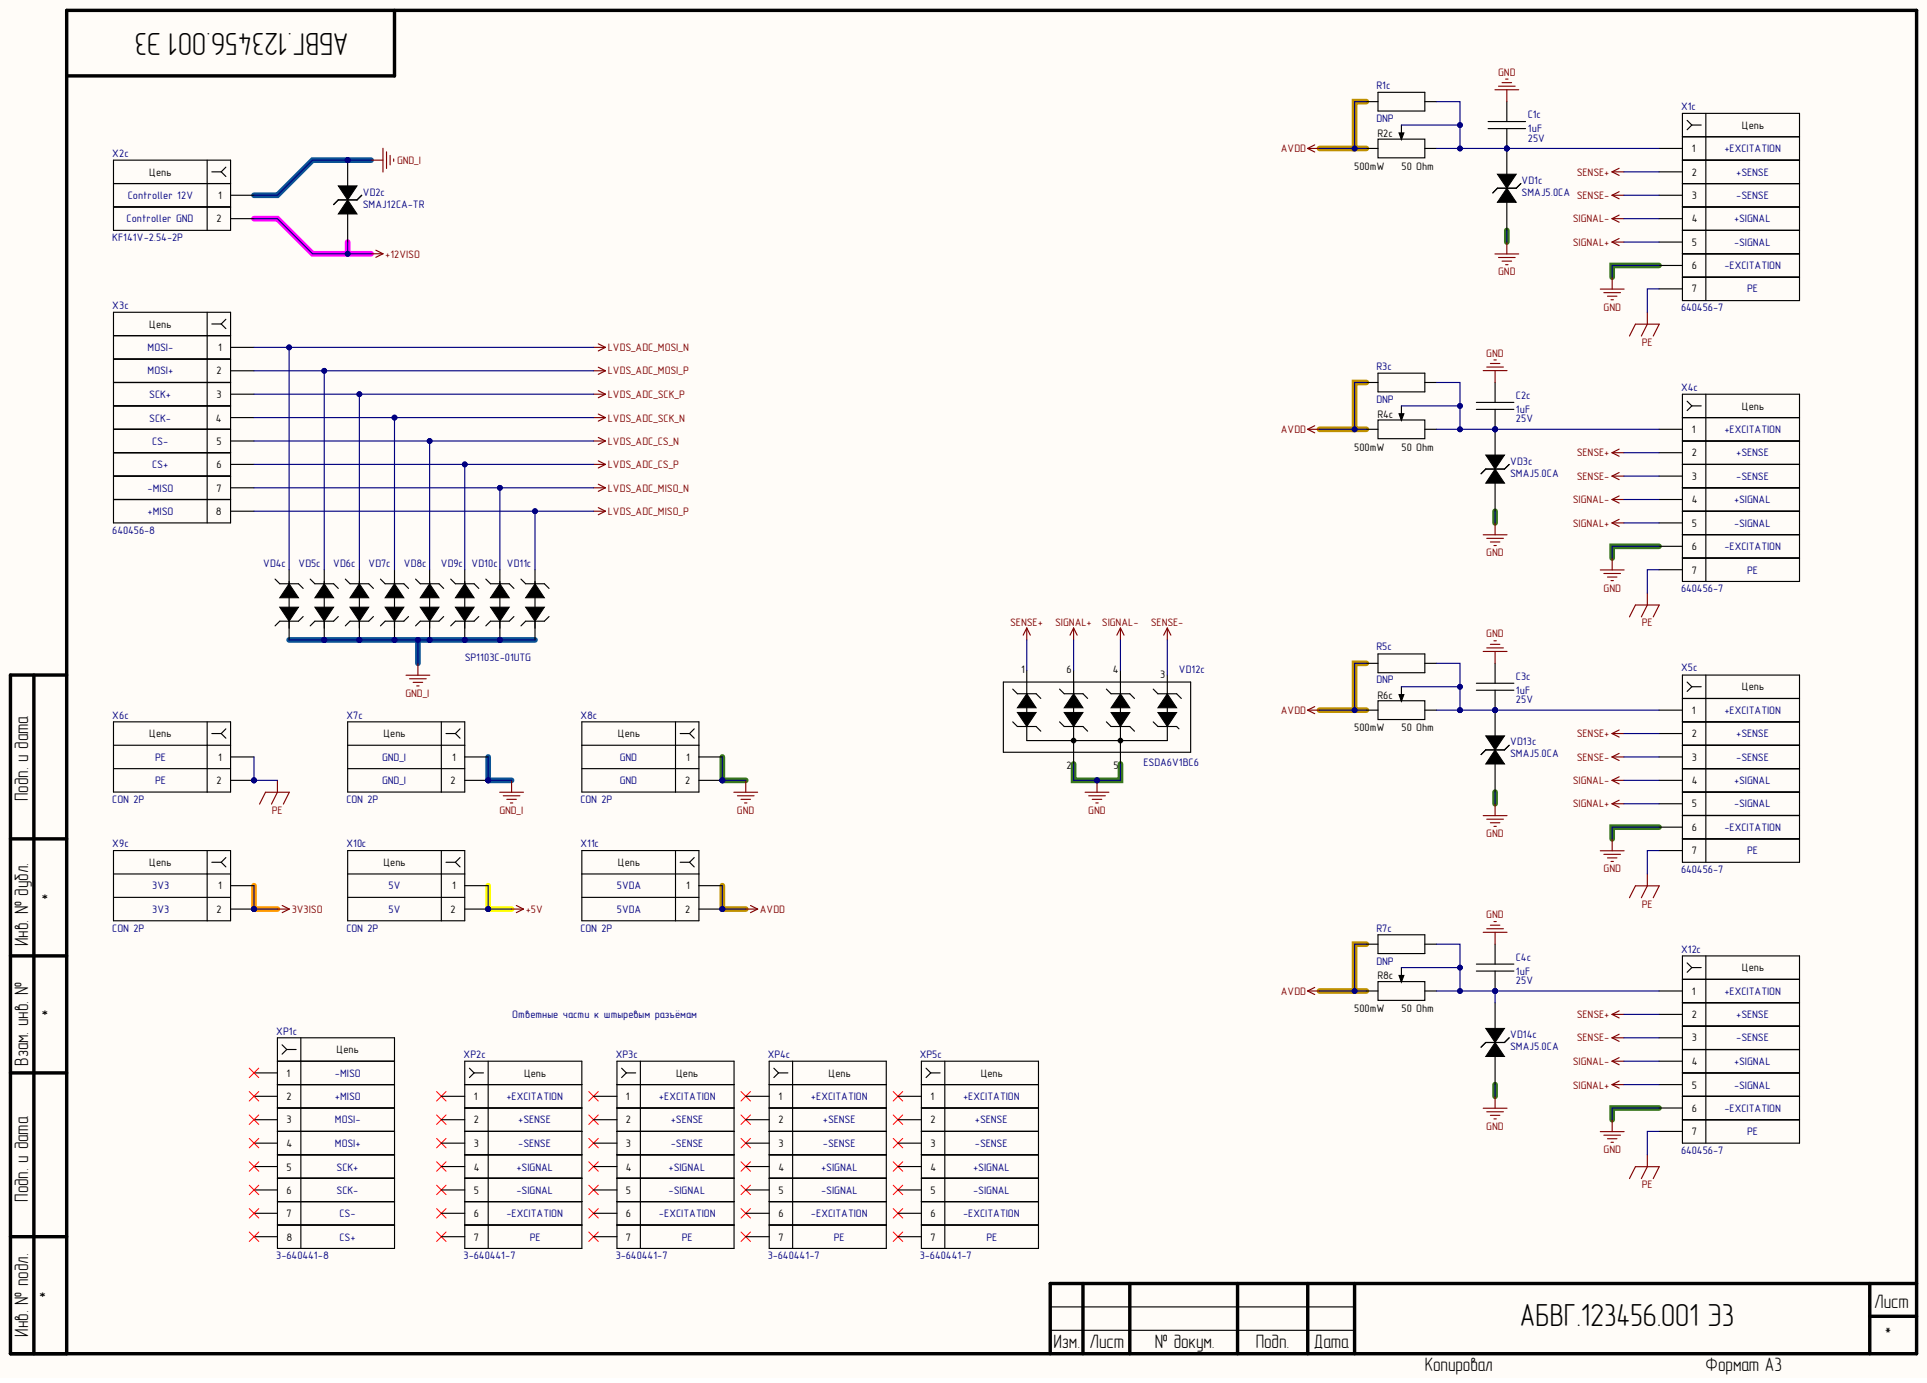
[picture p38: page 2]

Цепь

12 | +EXCIT A TIO N

SIGNAL+ SIGNAL- SIGNAL+ SIGNAL- SIGNAL+ SIGNAL-

-SIG N A L

-EXCIT A TIO N

+EXCIT A TIO N

+SEN S E

34567 | +SIG N A L

-SEN S E

-MIS O

+MIS O

Инв. № подл. Инв. № дубл. Подп. и дата Взам. инв. № Подп. и дата

АБВГ.123456.001 Э 3 | Лист *

Из м . | Лист | № докум . | Подп . | Дата

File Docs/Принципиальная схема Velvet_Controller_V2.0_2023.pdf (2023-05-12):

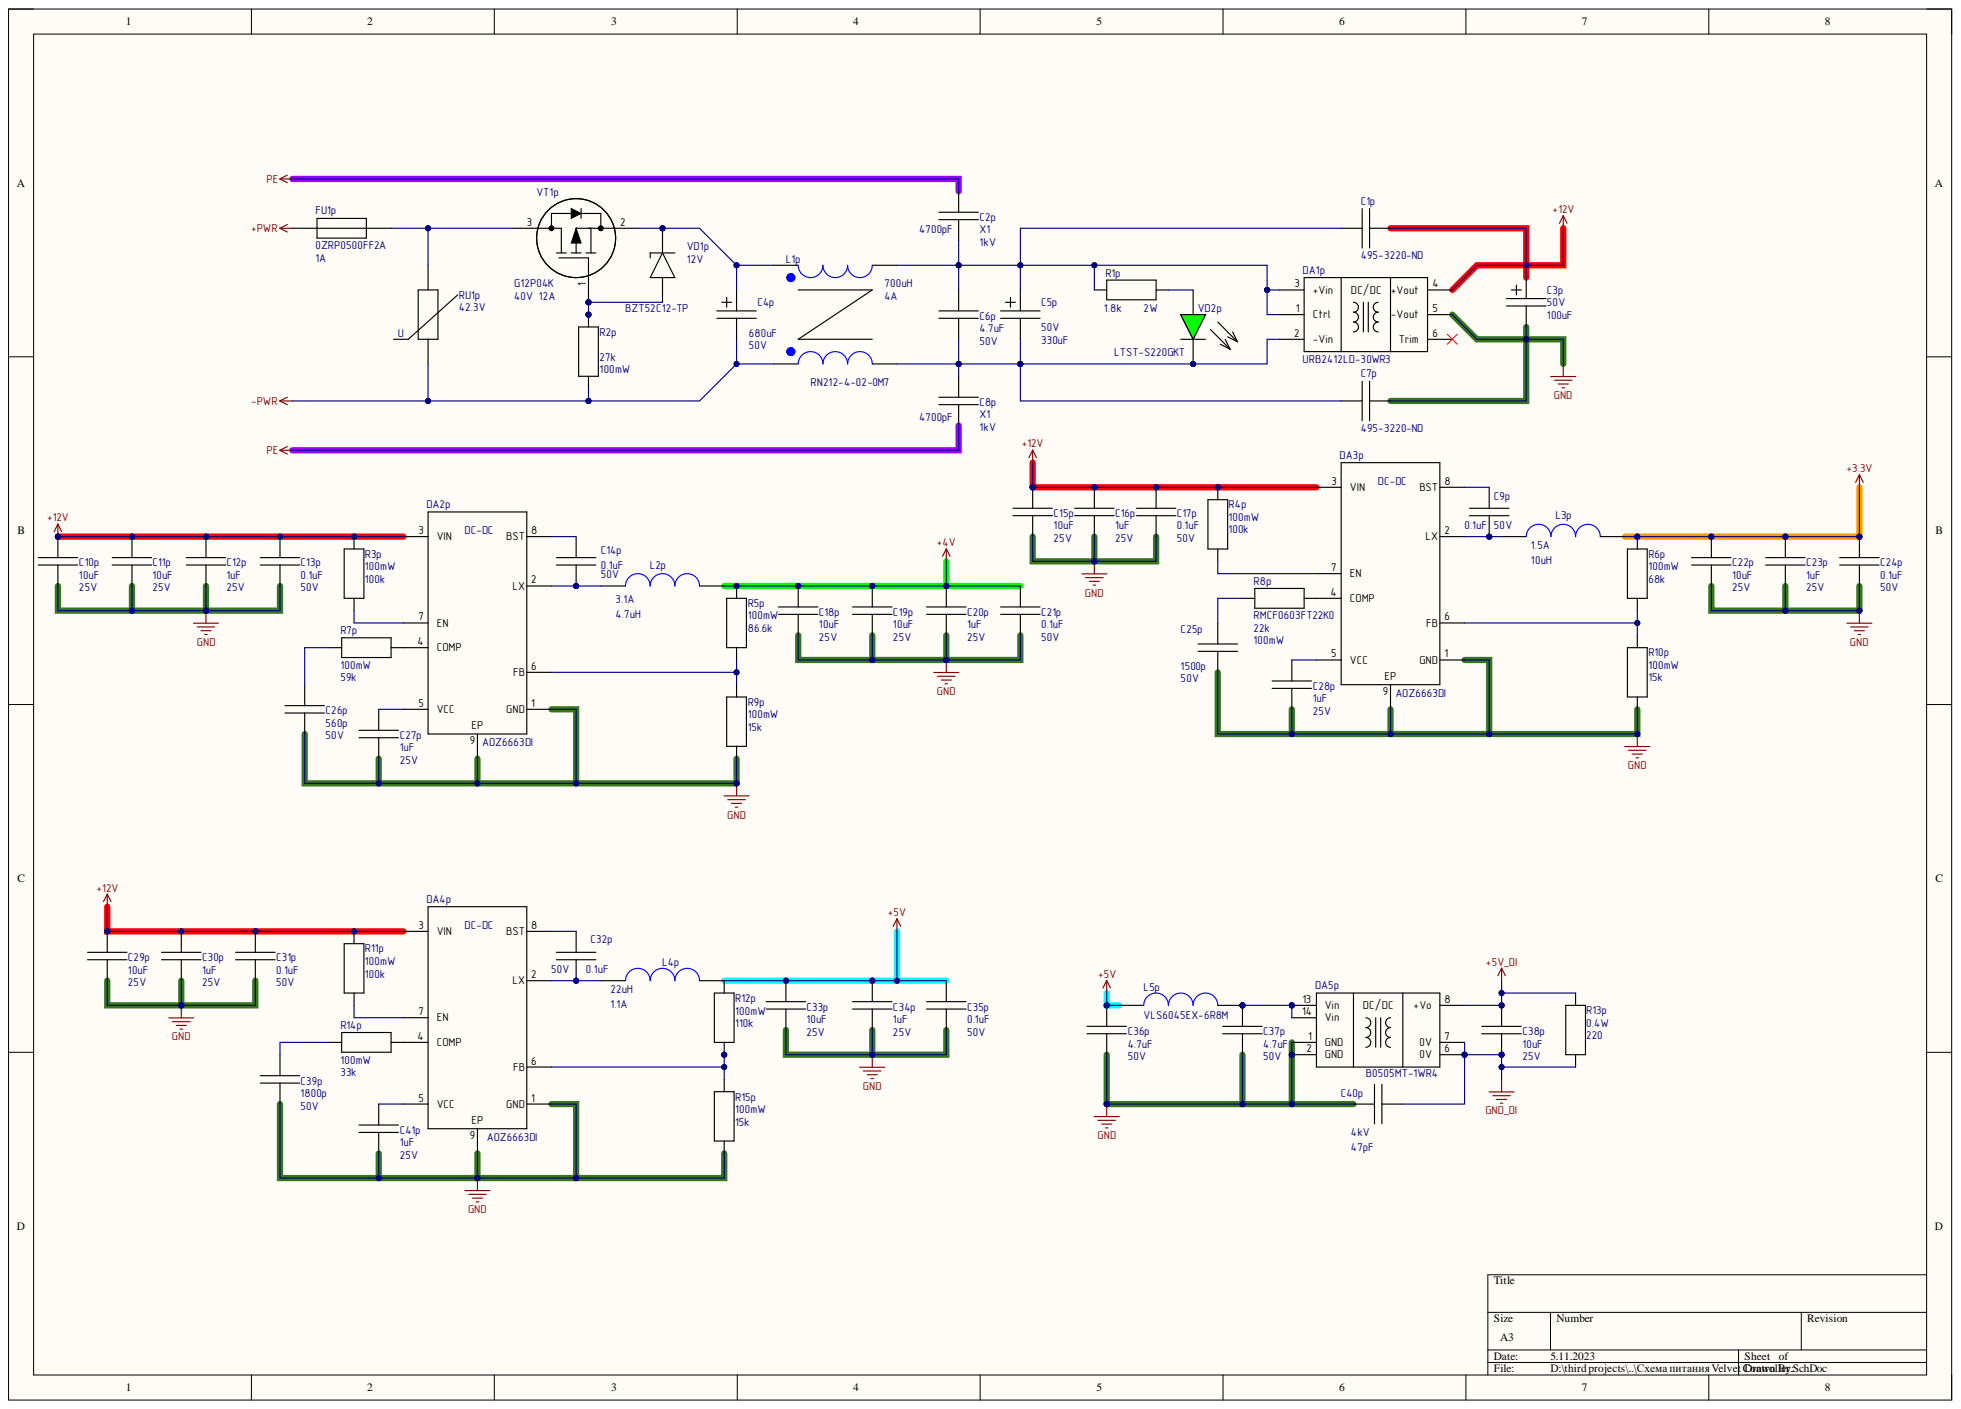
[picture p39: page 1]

+ Vin Ctrl -Vin | DC | /DC | + V o u t -V o u t Trim

5 0 V | LTST-S2 2 0 G K T

Vin GND GND | DC | /DC | + V o 0 V 0 V

CDont rawrol n Blery:.Sch

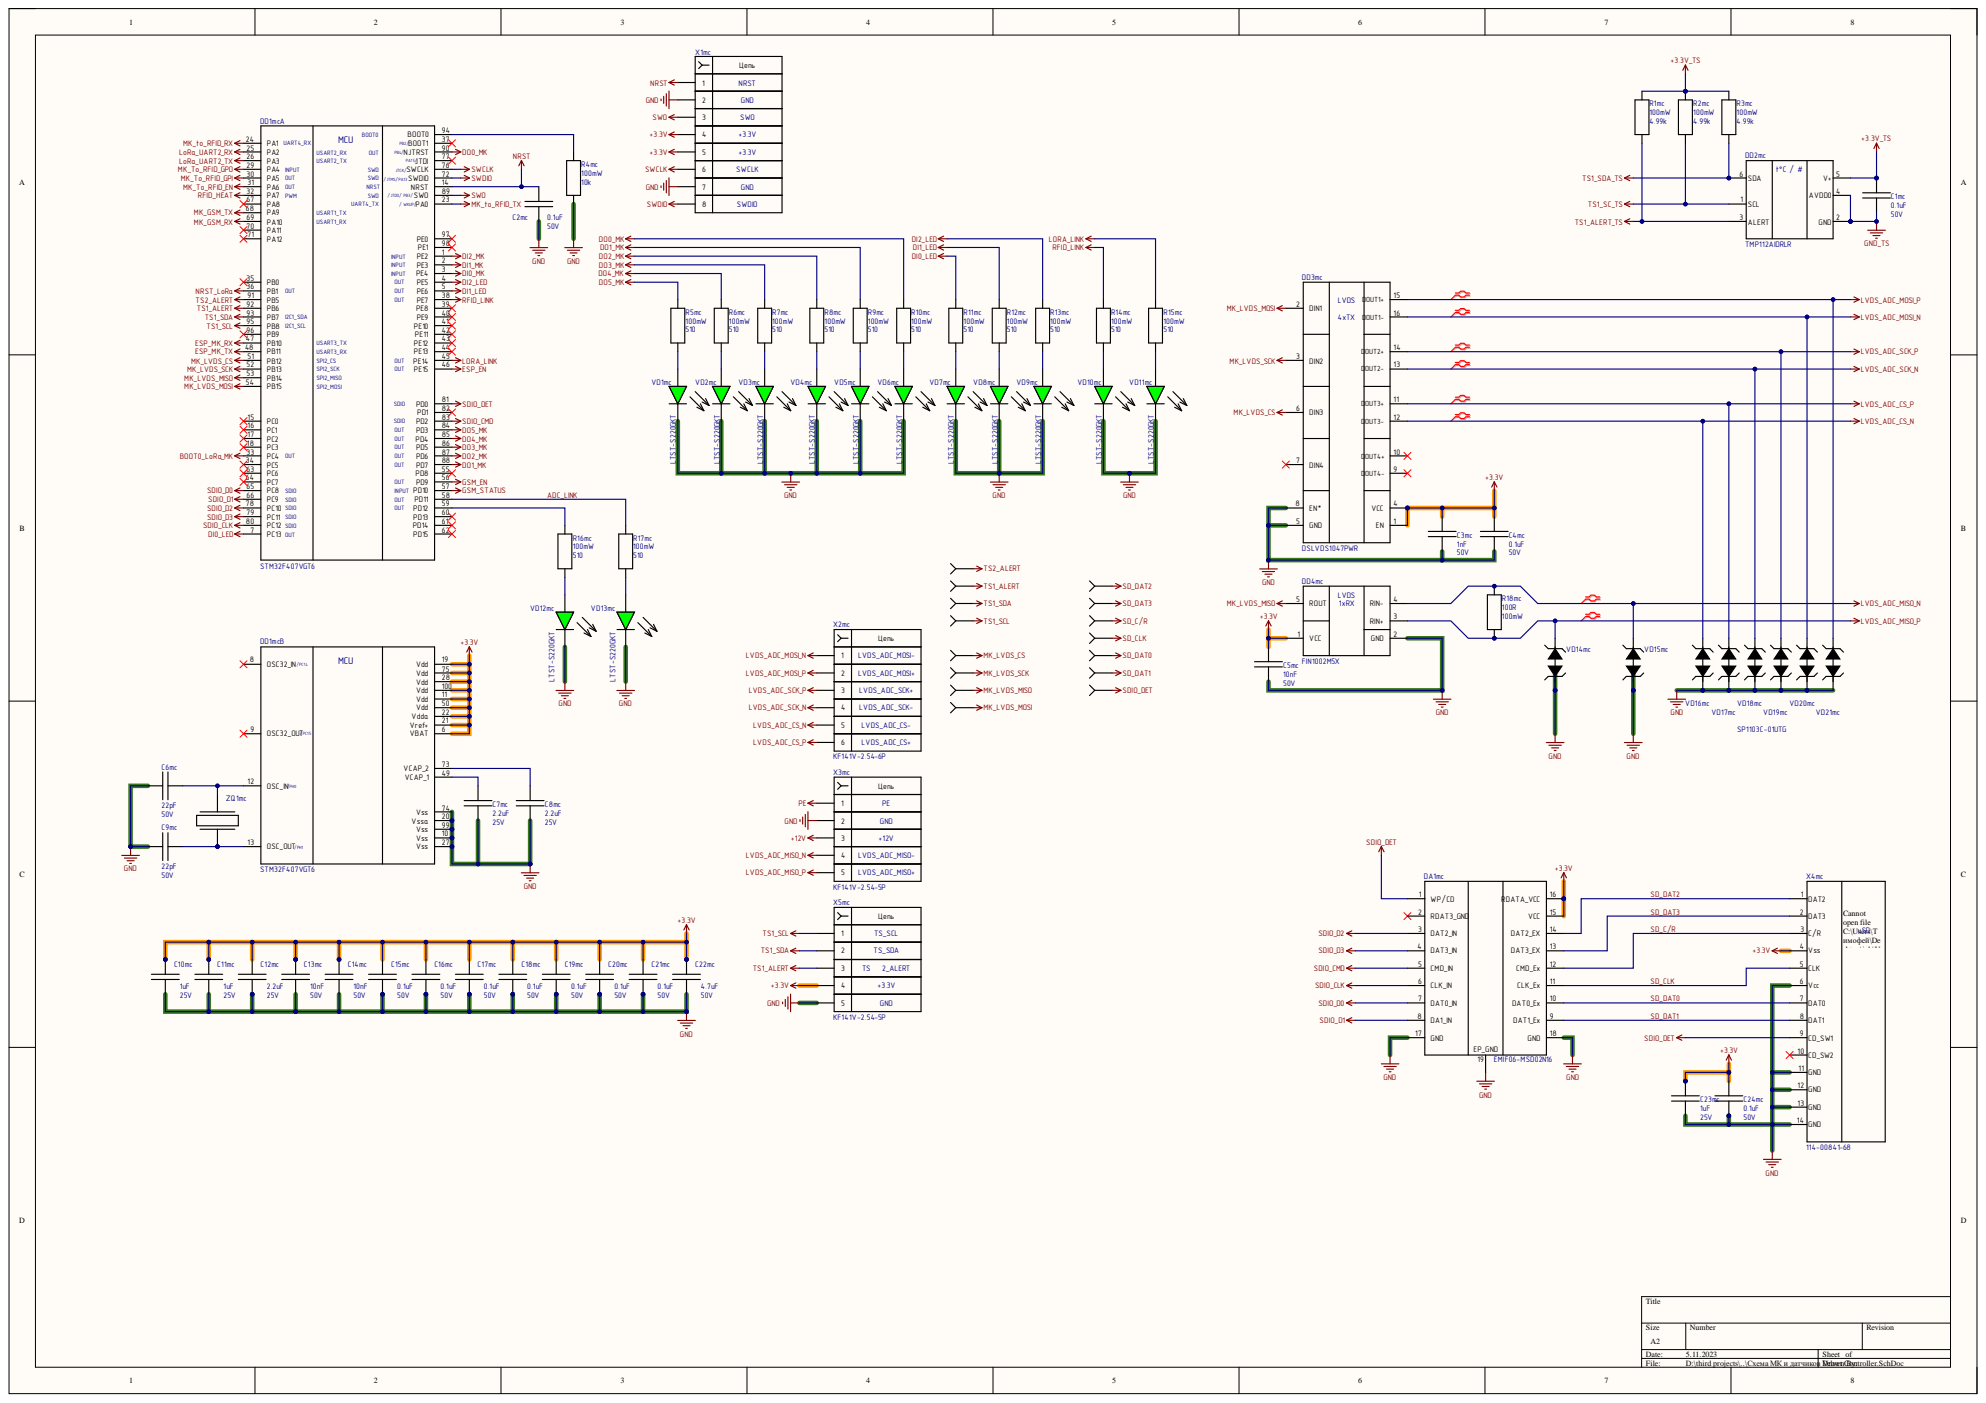
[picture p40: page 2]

NRST

Цепь

GND

SWO

LVDS 1xRX | RIN- | 4 ROUT 5

4 | LVDS_ADC_SCK-

5 | LVDS_ADC_CS-

OSC_OUT 13

4 | LVDS_ADC_MISO-

5 | LVDS_ADC_MISO+

1 | TS_SCL

2 | TS_SDA

3 | TS 2_ALERT

SD_CLK | Vcc 6

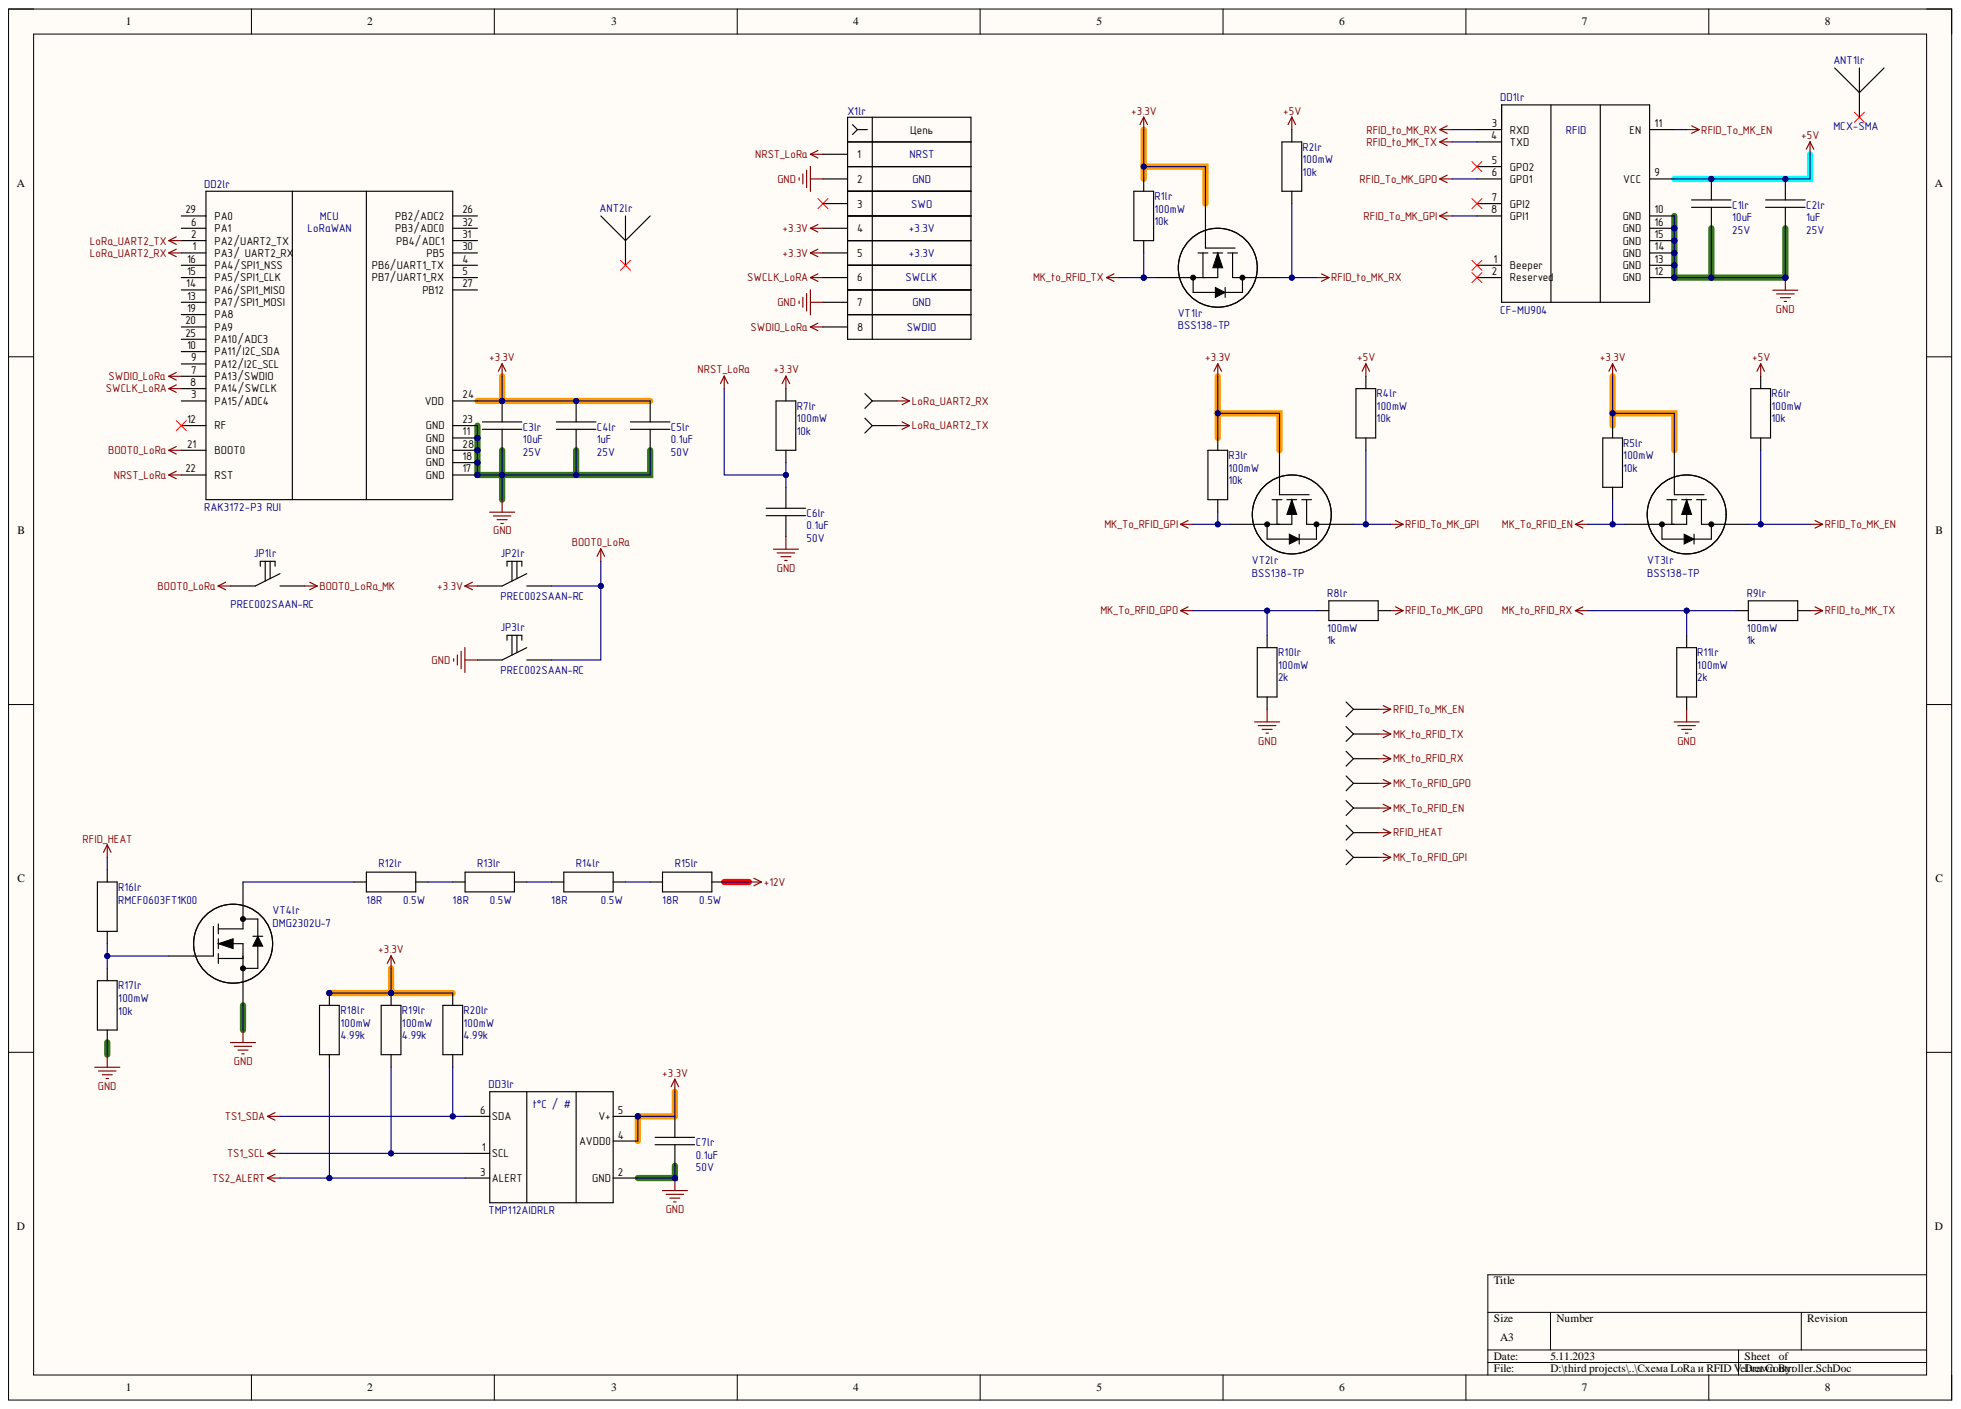
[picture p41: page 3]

Цепь

1 | NRST

2 | GND

7 | GND

8 | SWDIO

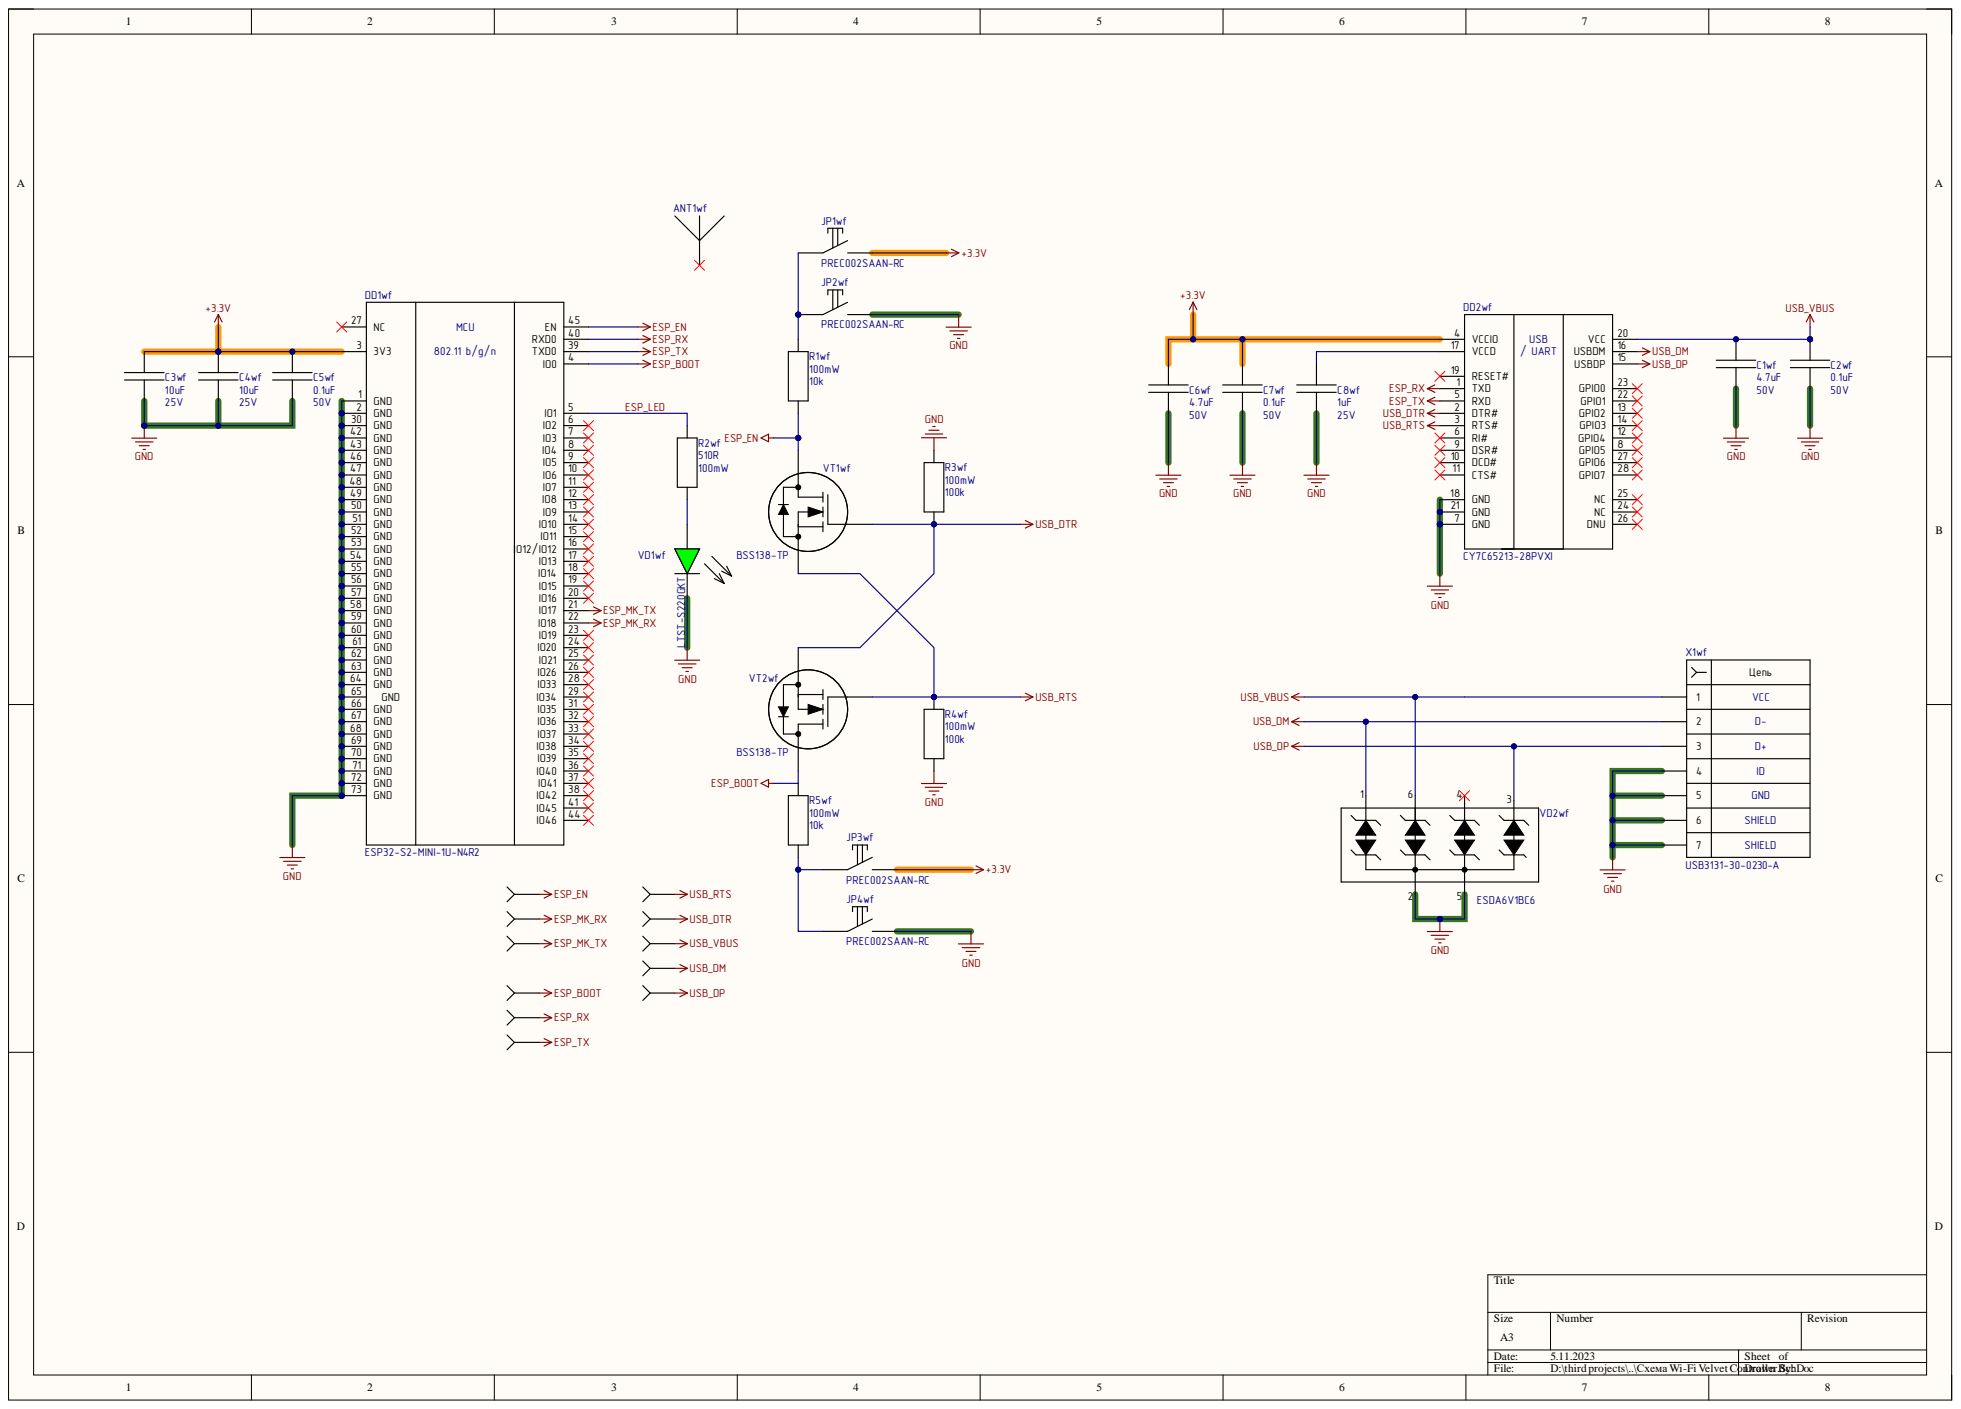
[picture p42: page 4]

V C CIO V C C D RESE T # TX D RX D DTR# RTS# RI# DC D # # 11 CTS GND GND | USB / UART | V C C USBDP GPIO1 GPIO2 GPIO4 GPIO5 GPIO6 GPIO7 NC DNU | 8 DSR#

3 0 | | 6
GND 42 | 7

5 2 | 1 5
5 3 | 1 6
5 4 | 1 7

5 6 | 1 9
5 7 | 2 0
5 8 | 2 1 2 2 2 3

6 1 | 2 4
6 2 | 2 5

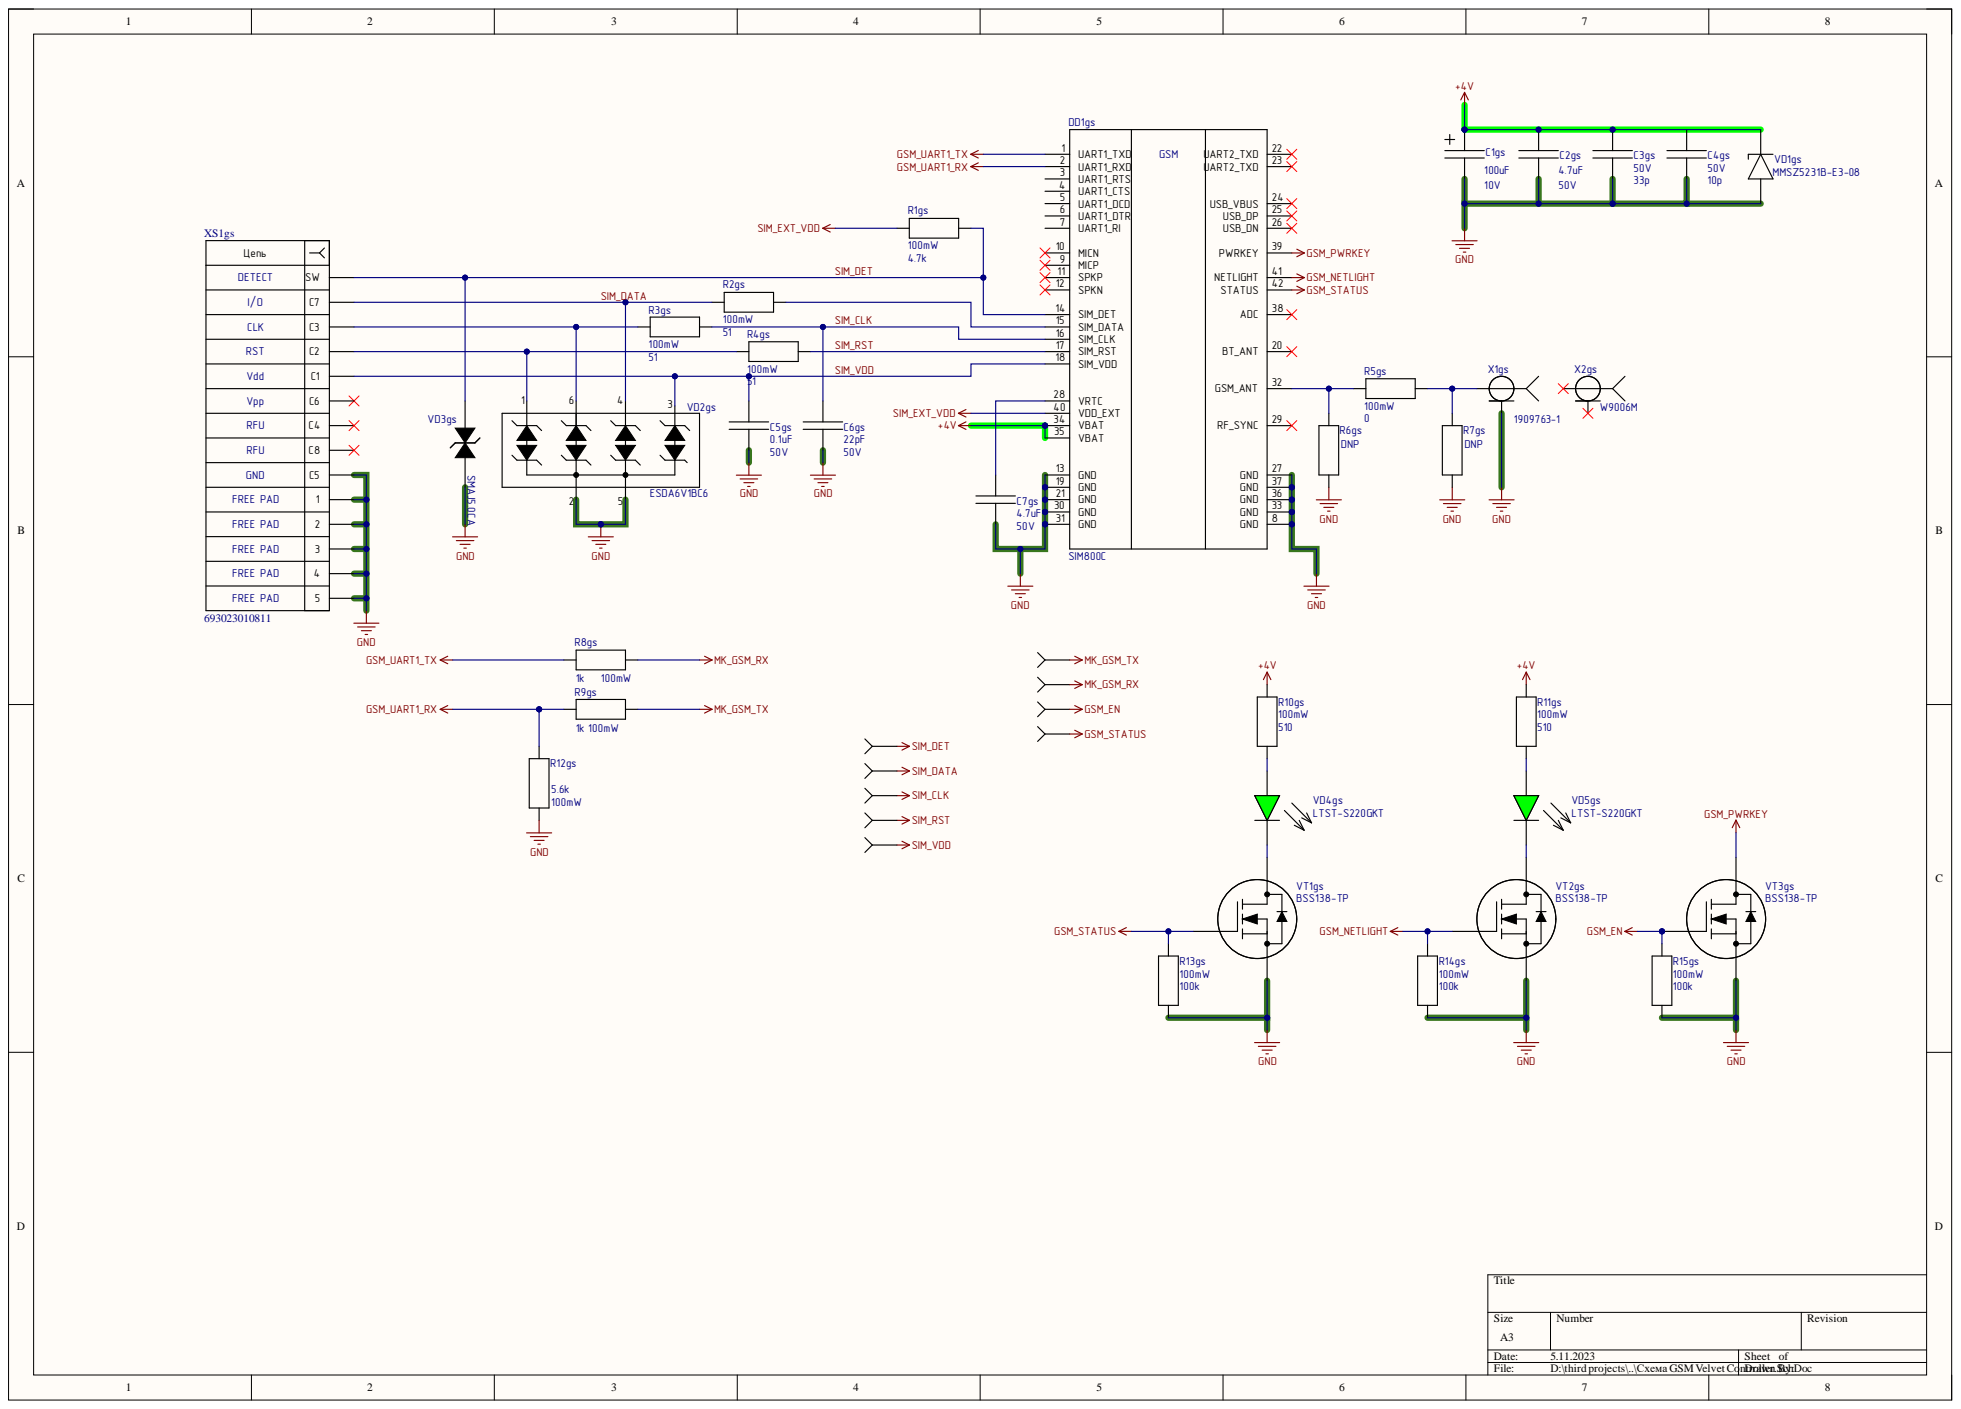
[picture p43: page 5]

UART1_TX D UART1_RX D UART1_RTS UART1_CTS UART1_DC D UART1_DTR UART1_RI MIC N MIC P SPKN T 14 SIM_DE SIM_DATA SIM_C L K SIM_RST VRTC T 40 VDD_E X VBA T VBA T GND GND GND GND GND | GSM | UART2_TX D UART2_TX D USB_VBUS USB_DP USB_DN PWRKE Y NETLIGH BT_ANT GSM_ANT RF_SYNC GND GND GND GND

R3 g s | SIM_C L K

RST Vdd | C 2 | | 10 0 m W | SIM_RST 1 7

FRE E PA D
FRE E PA D | 453

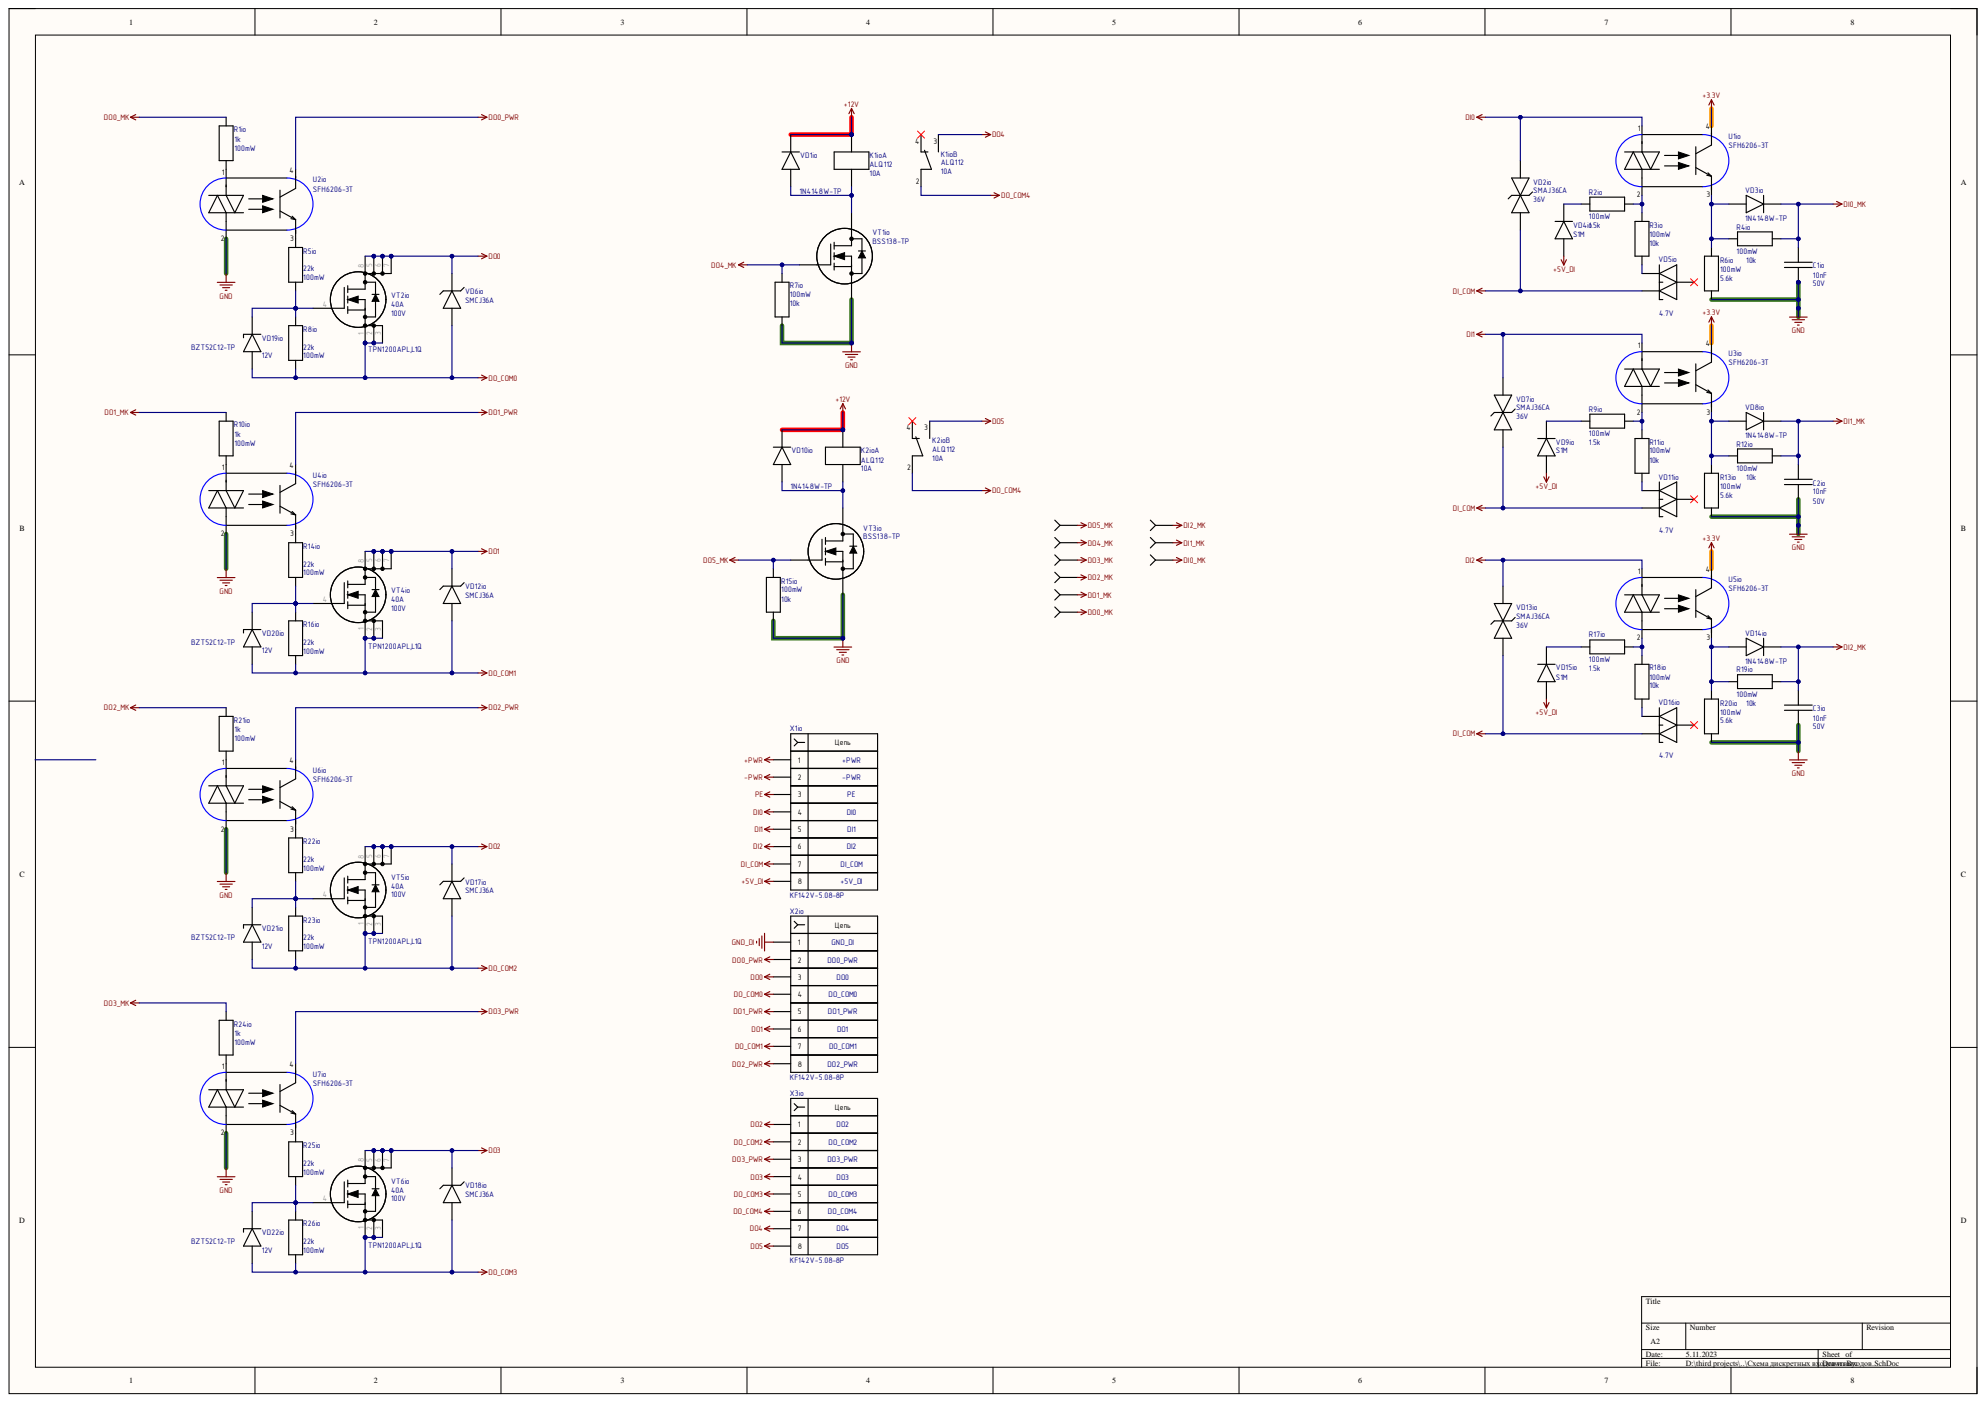
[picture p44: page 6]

ходов Drawn и вBыy:ходов

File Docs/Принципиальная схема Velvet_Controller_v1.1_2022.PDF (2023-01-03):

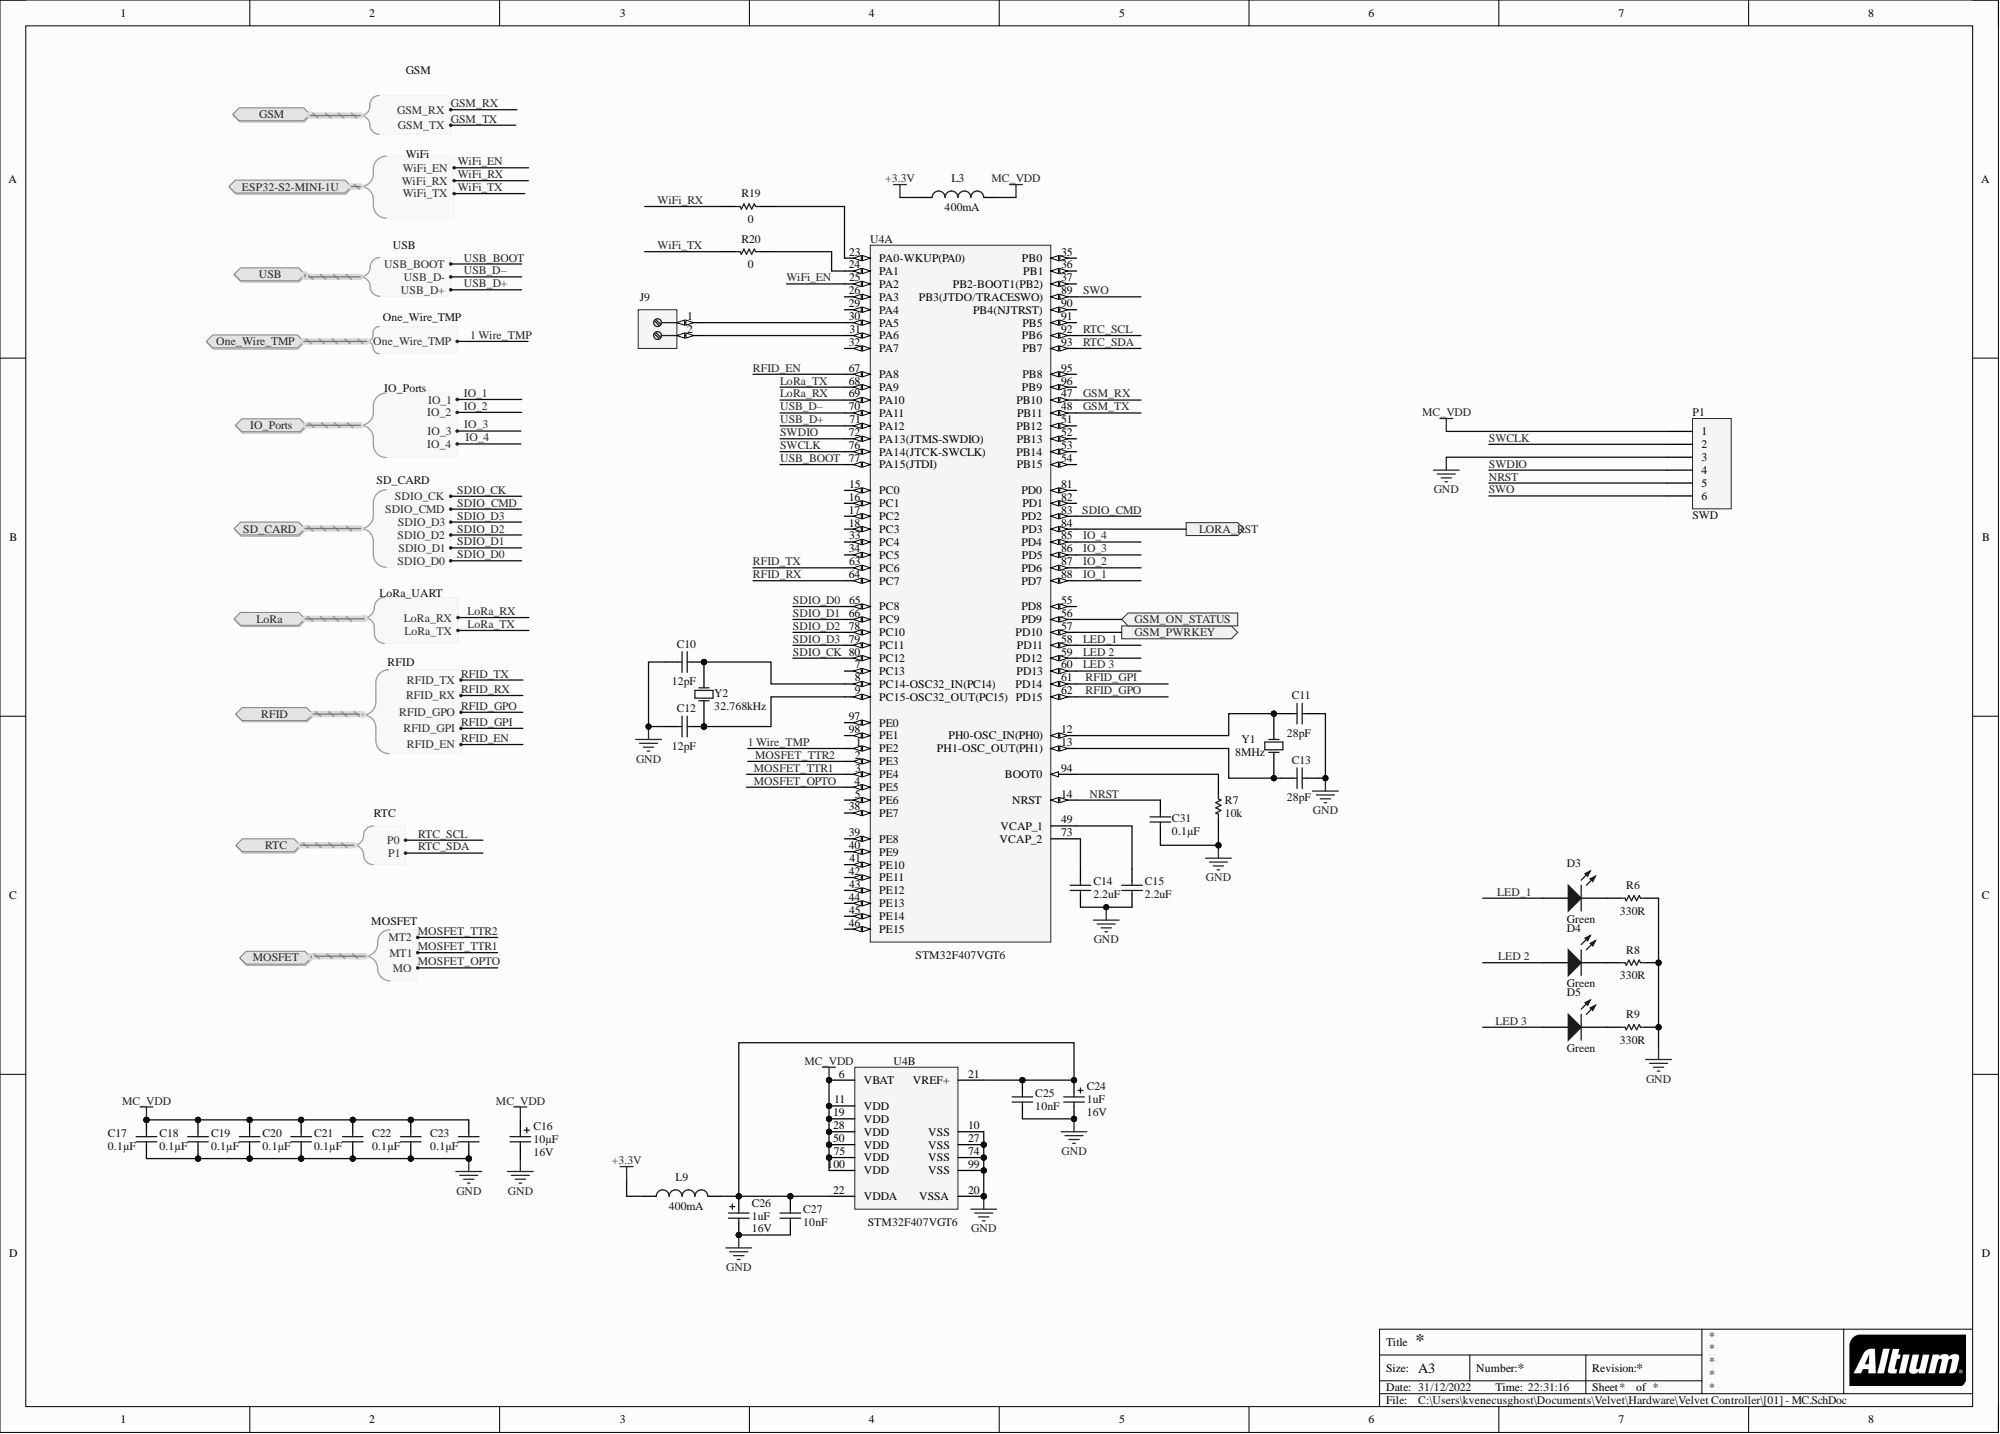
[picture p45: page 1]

PC15-OSC32_OUT(PC15) 9

32.768kHz | PE0 97

C:\Users\kvenecusghost\Documents\Velvet\Hardware\Velvet Controller\[01] - MC.SchDoc

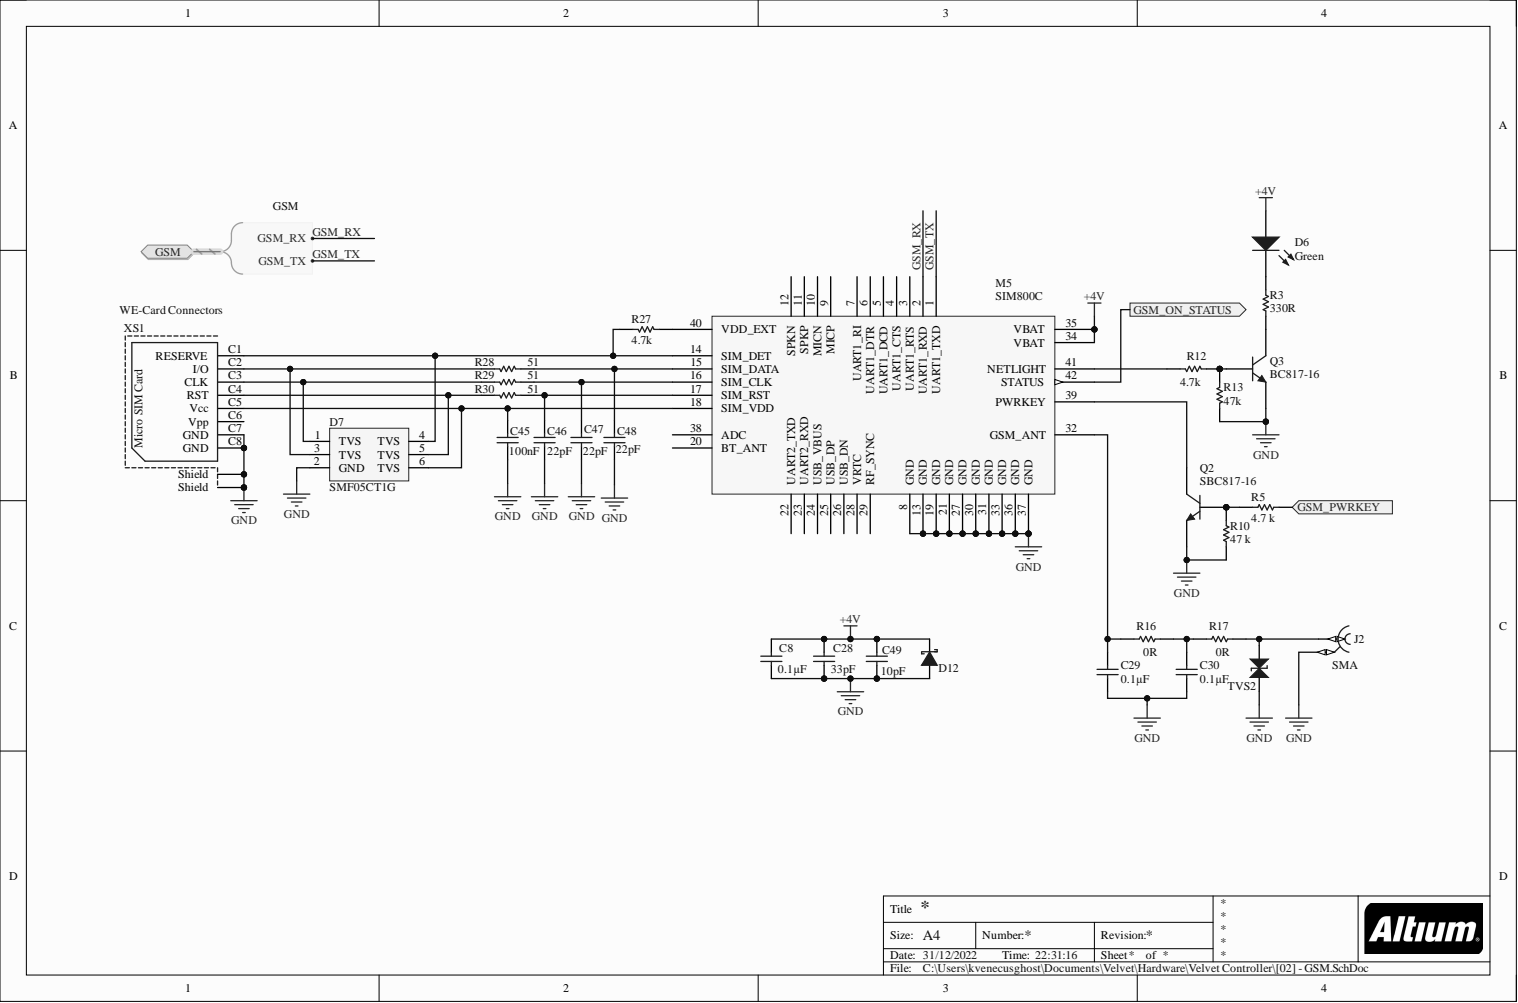
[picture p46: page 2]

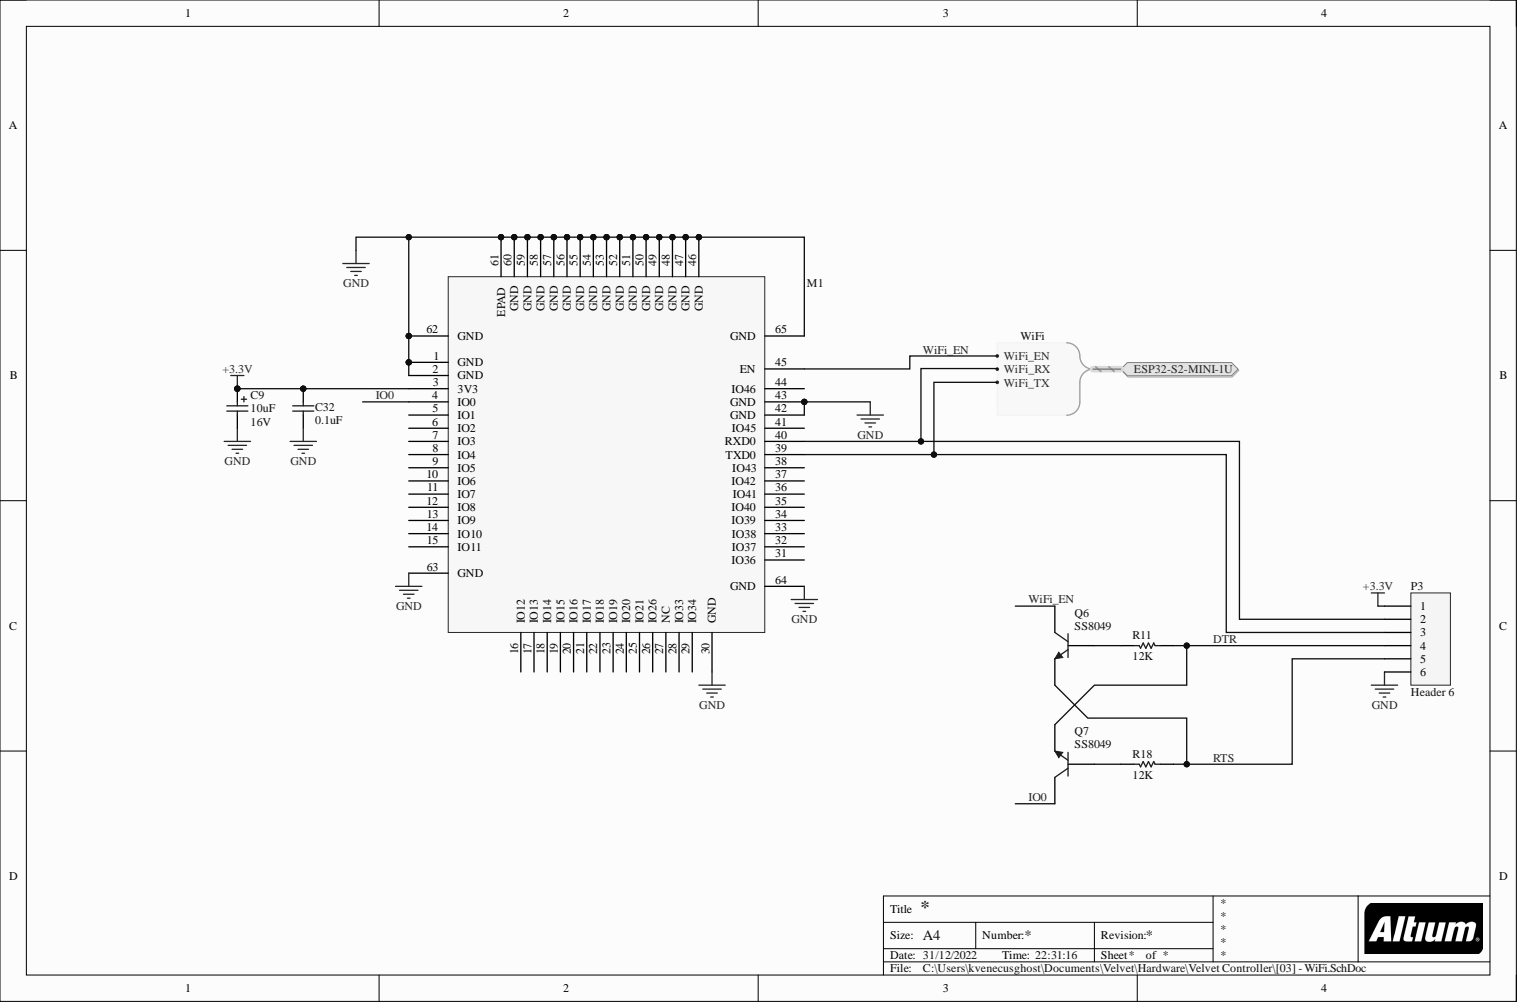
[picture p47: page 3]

GND 46 GND 47 GND 48 GND 49 GND 50 GND 51 GND 52 GND 53 GND 54 GND 55 GND 56 GND 57 GND 58 GND 59 GND 60 EPAD 61



C:\Users\kvenecusghost\Documents\Velvet\Hardware\Velvet Controller\[05] - Sensors.SchDoc



DAT2 1
CD/DAT3 2
CMD 3

C:\Users\kvenecusghost\Documents\Velvet\Hardware\Velvet Controller\[07] - SD.SchDoc



C:\Users\kvenecusghost\Documents\Velvet\Hardware\Velvet Controller\[09] - EMC-Power.SchDoc


1 5
1 4
1 3
1 2 | RFID _E N


C:\Users\kvenecusghost\Documents\Velvet\Hardware\Velvet Controller\[11] - MOSFET.SchDoc


C:\Users\kvenecusghost\Documents\Velvet\Hardware\Velvet Controller\[12] - RTC.SchDoc


C:\Users\kvenecusghost\Documents\Velvet\Hardware\Velvet Controller\Velvet_Controller_v1.1_2022.SchDoc

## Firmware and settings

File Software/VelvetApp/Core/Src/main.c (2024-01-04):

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
/* Includes ------------------------------------------------------------------*/
#include "main.h"
#include "cmsis_os.h"

/* USER CODE BEGIN Includes */
#include "appInit.h"
#include "app.h"
#include "esp.h"
#include "rfid.h"
#include "adc.h"
/* USER CODE END Includes */

IWDG_HandleTypeDef hiwdg;

TIM_HandleTypeDef htim6;

UART_HandleTypeDef huart4;
UART_HandleTypeDef huart6;
DMA_HandleTypeDef hdma_uart4_rx;
DMA_HandleTypeDef hdma_usart6_rx;

/* Definitions for sendMsg */
osThreadId_t sendMsgHandle;
const osThreadAttr_t sendMsg_attributes = {
  .name = "sendMsg",
  .stack_size = 128 * 4,
  .priority = (osPriority_t) osPriorityBelowNormal7,
};
/* Definitions for readWeight */
osThreadId_t readWeightHandle;
const osThreadAttr_t readWeight_attributes = {
  .name = "readWeight",
  .stack_size = 128 * 4,
  .priority = (osPriority_t) osPriorityNormal,
};
/* Definitions for readRfid */
osThreadId_t readRfidHandle;
const osThreadAttr_t readRfid_attributes = {
  .name = "readRfid",
  .stack_size = 128 * 4,
  .priority = (osPriority_t) osPriorityNormal1,
};
void SystemClock_Config(void);
static void MX_GPIO_Init(void);
static void MX_DMA_Init(void);
static void MX_IWDG_Init(void);
static void MX_UART4_Init(void);
static void MX_TIM6_Init(void);
static void MX_USART6_UART_Init(void);
void sendMsgToESPTask(void *argument);
extern void readWeightTask(void *argument);
extern void readRfidTask(void *argument);

/**
  * @brief  The application entry point.
  * @retval int
  */
int main(void)
{
  /* USER CODE BEGIN 1 */
	//SCB->VTOR = 0x08020000;
  //SCB->VTOR = 0x0800E000;  
  __HAL_RCC_GPIOA_CLK_DISABLE();
  __HAL_RCC_GPIOB_CLK_DISABLE();
  __HAL_RCC_GPIOC_CLK_DISABLE();
  __HAL_RCC_GPIOD_CLK_DISABLE();
  HAL_RCC_DeInit();
  HAL_DeInit();
  __enable_irq();
  /* USER CODE END 1 */

  /* MCU Configuration--------------------------------------------------------*/

  /* Reset of all peripherals, Initializes the Flash interface and the Systick. */
  HAL_Init();

  /* Configure the system clock */
  SystemClock_Config();

  /* Initialize all configured peripherals */
  MX_GPIO_Init();
  MX_DMA_Init();
  MX_IWDG_Init();
  MX_UART4_Init();
  MX_TIM6_Init();
  MX_USART6_UART_Init();
  /* USER CODE BEGIN 2 */
	__HAL_DBGMCU_FREEZE_IWDG();
	initApp();
  /* USER CODE END 2 */

  /* Init scheduler */
  osKernelInitialize();

  /* USER CODE BEGIN RTOS_MUTEX */
  /* add mutexes, ... */
  /* USER CODE END RTOS_MUTEX */

  /* USER CODE BEGIN RTOS_SEMAPHORES */
  /* add semaphores, ... */
  /* USER CODE END RTOS_SEMAPHORES */

  /* USER CODE BEGIN RTOS_TIMERS */
  /* start timers, add new ones, ... */
  /* USER CODE END RTOS_TIMERS */

  /* USER CODE BEGIN RTOS_QUEUES */
  /* add queues, ... */
	const osMessageQueueAttr_t espSendQueue_attributes = {
  .name = "espSendQueue"
	};
	const osMessageQueueAttr_t espReceiveQueue_attributes = {
  .name = "espReceiveQueue"
	};
	const osMessageQueueAttr_t rfidReceiveQueue_attributes = {
  .name = "rfidReceiveQueue"
	};
	const osMessageQueueAttr_t adcQueue_attributes = {
  .name = "adcQueue"
	};
	/* Create the queue(s) */
  /* creation of espSendQueue */
  espSendQueueHandle = osMessageQueueNew (5, sizeof(uint8_t), &espSendQueue_attributes);
  /* creation of espReceiveQueue */
  espReceiveQueueHandle = osMessageQueueNew (2, sizeof(uint8_t), &espReceiveQueue_attributes);
  /* creation of rfidReceiveQueue */
  rfidReceiveQueueHandle = osMessageQueueNew (2, sizeof(uint8_t), &rfidReceiveQueue_attributes);
  /* creation of adcQueue */
  adcQueueHandle = osMessageQueueNew (3, sizeof(uint8_t), &adcQueue_attributes);
  /* USER CODE END RTOS_QUEUES */

  /* Create the thread(s) */
  /* creation of sendMsg */
  sendMsgHandle = osThreadNew(sendMsgToESPTask, (void*) &huart4, &sendMsg_attributes);

  /* creation of readWeight */
  readWeightHandle = osThreadNew(readWeightTask, NULL, &readWeight_attributes);

  /* creation of readRfid */
  readRfidHandle = osThreadNew(readRfidTask, (void*) &huart6, &readRfid_attributes);

  /* USER CODE BEGIN RTOS_THREADS */
  /* add threads, ... */
  /* USER CODE END RTOS_THREADS */

  /* USER CODE BEGIN RTOS_EVENTS */
  /* add events, ... */
  /* USER CODE END RTOS_EVENTS */

  /* Start scheduler */
  osKernelStart();
  /* We should never get here as control is now taken by the scheduler */
  /* Infinite loop */
  /* USER CODE BEGIN WHILE */
  while (1)
  {		
    /* USER CODE END WHILE */

    /* USER CODE BEGIN 3 */
  }
  /* USER CODE END 3 */
}

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
/* USER CODE BEGIN Header_sendMsgToESPTask */
/**
  * @brief  Function implementing the sendMsg thread.
  * @param  argument: Not used
  * @retval None
  */
/* USER CODE END Header_sendMsgToESPTask */
__weak void sendMsgToESPTask(void *argument)
{
  /* USER CODE BEGIN 5 */
  /* Infinite loop */
  for(;;)
  {
    osDelay(1);
  }
  /* USER CODE END 5 */
}

/**
  * @brief  Period elapsed callback in non blocking mode
  * @note   This function is called  when TIM1 interrupt took place, inside
  * HAL_TIM_IRQHandler(). It makes a direct call to HAL_IncTick() to increment
  * a global variable "uwTick" used as application time base.
  * @param  htim : TIM handle
  * @retval None
  */
void HAL_TIM_PeriodElapsedCallback(TIM_HandleTypeDef *htim)
{
  if (htim->Instance == TIM1) {
    HAL_IncTick();
  }
  /* USER CODE BEGIN Callback 1 */
	if (htim->Instance == TIM6) {
		checkTasksTimeout();    
  }
  /* USER CODE END Callback 1 */
}

/**
  * @brief  This function is executed in case of error occurrence.
  * @retval None
  */
void Error_Handler(void)
{
  /* USER CODE BEGIN Error_Handler_Debug */
  /* User can add his own implementation to report the HAL error return state */
  __disable_irq();
  while (1)
  {
  }
  /* USER CODE END Error_Handler_Debug */
}

#ifdef  USE_FULL_ASSERT
/**
  * @brief  Reports the name of the source file and the source line number
  *         where the assert_param error has occurred.
  * @param  file: pointer to the source file name
  * @param  line: assert_param error line source number
  * @retval None
  */
void assert_failed(uint8_t *file, uint32_t line)
{
  /* USER CODE BEGIN 6 */
  /* User can add his own implementation to report the file name and line number,
     ex: printf("Wrong parameters value: file %s on line %d\r\n", file, line) */
  /* USER CODE END 6 */
}
#endif /* USE_FULL_ASSERT */

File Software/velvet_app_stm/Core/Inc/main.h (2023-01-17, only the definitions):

#define T_SENSOR_Pin GPIO_PIN_2
#define T_SENSOR_GPIO_Port GPIOE
#define DRUGS_PUMP_Pin GPIO_PIN_3
#define DRUGS_PUMP_GPIO_Port GPIOE
#define PAINT_PUMP_Pin GPIO_PIN_4
#define PAINT_PUMP_GPIO_Port GPIOE
#define WIFI_TX_Pin GPIO_PIN_0
#define WIFI_TX_GPIO_Port GPIOA
#define WIFI_RX_Pin GPIO_PIN_1
#define WIFI_RX_GPIO_Port GPIOA
#define WIFI_EN_Pin GPIO_PIN_2
#define WIFI_EN_GPIO_Port GPIOA
#define GSM_TX_Pin GPIO_PIN_10
#define GSM_TX_GPIO_Port GPIOB
#define GSM_RX_Pin GPIO_PIN_11
#define GSM_RX_GPIO_Port GPIOB
#define GSM_ON_STATUS_Pin GPIO_PIN_9
#define GSM_ON_STATUS_GPIO_Port GPIOD
#define GSM_PWRKEY_Pin GPIO_PIN_10
#define GSM_PWRKEY_GPIO_Port GPIOD
#define LED1_Pin GPIO_PIN_11
#define LED1_GPIO_Port GPIOD
#define LED2_Pin GPIO_PIN_12
#define LED2_GPIO_Port GPIOD
#define LED3_Pin GPIO_PIN_13
#define LED3_GPIO_Port GPIOD
#define RFID_GPI_Pin GPIO_PIN_14
#define RFID_GPI_GPIO_Port GPIOD
#define RFID_GPO_Pin GPIO_PIN_15
#define RFID_GPO_GPIO_Port GPIOD
#define RFID_TX_Pin GPIO_PIN_6
#define RFID_TX_GPIO_Port GPIOC
#define RFID_RX_Pin GPIO_PIN_7
#define RFID_RX_GPIO_Port GPIOC
#define RFID_EN_Pin GPIO_PIN_8
#define RFID_EN_GPIO_Port GPIOA
#define LORA_TX_Pin GPIO_PIN_9
#define LORA_TX_GPIO_Port GPIOA
#define LORA_RX_Pin GPIO_PIN_10
#define LORA_RX_GPIO_Port GPIOA
#define LORA_RST_Pin GPIO_PIN_3
#define LORA_RST_GPIO_Port GPIOD
#define RTC_SCL_Pin GPIO_PIN_6
#define RTC_SCL_GPIO_Port GPIOB
#define RTC_SDA_Pin GPIO_PIN_7
#define RTC_SDA_GPIO_Port GPIOB

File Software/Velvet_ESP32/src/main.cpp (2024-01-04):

/**
 * @mainpage ESP32_STM_UART
 * @brief Проект ESP32_STM_UART предназначен для реализации протокола общения между микроконтроллерами ESP32 и STM32
 * с использованием интерфейса UART. Проект содержит файлы ESP32_STM_UART.h и Settings_ESP.h.
 * @section structure Структура проекта
 * * main.cpp
 * * ESP32_STM_UART.h
 * * ESP32_STM_UART.cpp
 * * Settings_ESP.h
 * @section protocol Протокол общения
 * Протокол общения между устройствами STM и ESP32 описан в документации проекта.

 * @details Протокол общения между устройствами представляет собой набор команд, передаваемых по UART. Команды от STM32
 * содержат определенные значения, указывающие на тип команды и ее параметры. Команды от ESP32 являются ответами на
 * соответствующие команды от STM32 и содержат информацию о выполнении команды и ее результатах.
 * В библиотеке ESP32_STM_UART реализованы методы для обработки входящих команд, отправки их на STM32, а также для
 * обработки ответов от STM32. Кроме того, библиотека содержит дополнительные методы для работы с UART, такие как
 * настройка скорости передачи данных и установка пинов для подключения интерфейса UART.
 * Для работы с библиотекой необходимо создать объект класса ESP32_STM_UART и вызвать методы для обработки команд и
 * отправки ответов. Подробная документация по каждому методу доступна в соответствующих файлах с исходным кодом.
*/
/**

 * @file main.cpp
 * @brief Главный файл проекта ESP32_STM_UART. Точка входа в программу
 * @details В функции setup() происходит инициализация устройств и настройка параметров UART. В функции loop()
 * происходит обработка входящих команд и отправка ответов на STM32.
 * 
*/
#include <Arduino.h>
#include <WiFi.h>
#include "ESP32_STM_UART.h"
#include "Settings_ESP.h"
#include <HTTPClient.h>
#include <Update.h>

const char* ssid = "R";     //TODO: Заменить SSID;
const char* password = "12121957"; //TODO: Заменить пароль;
bool debug_flag = true; //TODO: В случае теста флаг - true; в продакшн флаг - false;
String serialNumber = String(ESP.getChipRevision());

//HardwareSerial Serial2(2);
uint32_t uartBaudRate = 115200; 

/**
 * @brief Создает экземпляр ESP32_STM_UART для обработки сообщений.
 * @param Serial2 Аппаратный последовательный порт, используемый для общения.
 * @param uartBaudRate Скорость передачи данных в бод (baud rate) для последовательного порта.
 */

ESP32_STM_UART stmUart(Serial2, uartBaudRate);

/**
 * @brief Настраивает начальные параметры, такие как последовательный порт и подключение Wi-Fi.
 */
void setup() {
    Serial2.begin(uartBaudRate, SERIAL_8N1, 12, 13);
    Serial.begin(uartBaudRate);
    print_debug(debug_flag, String("Ready"));
    //WiFi.begin(ssid, password);
    /**
     * @brief Подключение к wi-fi retries раз
    */
    int retries = 5;
    
    while (WiFi.status() != WL_CONNECTED && retries > 0) {
        delay(500);
        WiFi.begin(ssid, password);
        if (WiFi.status() == WL_CONNECTED) {
            print_debug(debug_flag, String("Wifi connected"));
        }
        retries--;
        print_debug(debug_flag, String("Wi-Fi not connected!"));
    }
        /**
         * @brief Не удалось подключиться к Wi-Fi, здесь можно добавить обработку ошибок
        */ 
        // Serial.println("Не удалось подключиться к Wi-Fi");
    
    print_debug(debug_flag, String("Wi-Fi connected!"));
}

// void sendcmd(uint8_t result) {
//   uint8_t response[8] = {0x01, result, 0x00, 0x00, 0x00, 0x00, 0x00, 0x00};
//   Serial2.write(response, sizeof(response));
// }

/**
 * @brief Основной цикл программы, обрабатывает входящие сообщения через stmUart.
 */
void loop() {
    //print_debug(debug_flag, String("We are in loop"));
    stmUart.processIncomingMessage();
    //stmUart.sendcmd(0x02);
    //delay(200);
}

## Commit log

2022-01-30 Репозиторий для гитхаб
    [40x40x10 DC Fan v1.step.SLDPRT, 91420A177.step.SLDPRT, 92000A114.step.SLDPRT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]
2022-01-30 Добавил АС-DC и EMI фильтр в библиотеку компонентов
2022-02-06 Почистил лишнее. Переименовал файлы.
    [40x40x10 DC Fan v1.step.SLDPRT, 91420A177.step.SLDPRT, 92000A114.step.SLDPRT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]
2022-02-06 переименовал папки
    [40x40x10 DC Fan v1.step.SLDPRT, 91420A177.step.SLDPRT, 92000A114.step.SLDPRT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]
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2022-02-18 Разделил файлы на 2 репозитрия
    [Velvet_v1.1-2021(revised for PCB).PrjPcb, Схема блока GSM.SchDoc, Схема блока IO_Ports.SchDoc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]
2022-02-20 Сверил BOM с посылками 20.02.2022
    [Сomponents ChipDip сверено с посылками 20.02.2022.xls, Сomponents DigiKey сверено с посылками 20.02.2022.xls, Сomponents Аliexpress сверено с посылками 20.02.2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]
2022-02-28 Исправил баг с потерей шеалы
2022-02-28 Добавил проект от Каната
    [Blue Tractor-2021.SchLib, Blue Tractor_v1.1-2021.PrjPCB, Blue Tractor_v1.1-2021.SchDoc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]
2022-03-08 Добавил гербера от Каната
    [Blue Tractor_v3.3-2022.GBL, Blue Tractor_v3.3-2022.GBO, Blue Tractor_v3.3-2022.GBP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]
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2022-03-08 Рефактор расположения папок. Изменил Readme. Обязательно к ознакомлению и следованию
    [Blue Tractor_v3.3-2022.GBL, Blue Tractor_v3.3-2022.GBO, Blue Tractor_v3.3-2022.GBP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]
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2022-03-10 Добавил папку с проектом от Каната
    [Velvet_Controller_v1.1_2022.GBL, Velvet_Controller_v1.1_2022.GBO, Velvet_Controller_v1.1_2022.GBP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]
2022-03-10 Почистил папку Hardware. Перенес гербера в Hardware Release. Добавил правило на годичные кольца.
    [Blue Tractor-2021.SchLib, Blue Tractor_v1.1-2021.PrjPCB, Blue Tractor_v1.1-2021.SchDoc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]
2022-03-12 Исправлены зазор годовых колец в печатной плате; Добавлена папка History в Игнор
    [Velvet_Controller_v1.1_2022.PrjPCB]
2022-03-12 Добавил Gerber файлы после исправления годовых колец
    [Velvet_Controller_v1.1_2022.GBL, Velvet_Controller_v1.1_2022.GBO, Velvet_Controller_v1.1_2022.GBP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]
2022-03-13 Заменил конденсаторы в Velvet ADC
    [Схема модуля АЦП.SchDoc]
2022-03-14 Добавил корпус балансира
    [Корпус.SLDPRT]
2022-03-14 Добавил сборку балансира
    [Балансир_MAIN.SLDASM, Корпус.SLDPRT, Крышка.SLDPRT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]
2022-03-19 Добавил модель платы балансира
    [Trimpot_3296W.STEP, terminal_blocks_a-tb500t202sb.stp, Балансир_MAIN.SLDASM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]
2022-03-20 Отредактировал структуру папок Velvet Controller v1.2
    [Velvet_Controller_v1.1_2022.GBL, Velvet_Controller_v1.1_2022.GBO, Velvet_Controller_v1.1_2022.GBP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]
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2022-04-04 Расположил компоненты на плате
    [Schlib.SchLib, Velvet ADC module.PcbDoc, Velvet ADC module.PrjPcb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]
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2022-04-24 Добавил LDO как меру снижения помех по питанию
    [Schlib.SchLib, Velvet ADC module.PcbDoc, Velvet ADC module.PrjPcb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]
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2022-08-30 Добавил альтернативы для недостоющих компонентов в BOM
    [Velvet ADC v1 BOM.xlsx, Схема модуля АЦП.SchDoc]
2022-10-02 Добавлены перемычки и посадочные для постоянных резисторов вместо потенциометров, пересобраны гербера
    [Files Description.xls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]
2022-11-01 Bom corrected
    [Velvet ADC v1 BOM.xlsx, Сomponents DigiKey сверено с посылками 20.02.2022.xls, Список_для_закупа_по_Velvet_Controller_31_08_2022.xls]
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2023-02-07 step файл корпуса балансира
    [Балансир_MAIN.STEP]
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2023-04-09 DEVELOPMENT-182: Разработка принципиальной схемы Velvet Controller 2.0
    [Velvet_Controller_V1.2_2023.PrjPcb, Схема GSM Velvet Controller.SchDoc, Схема LoRa и RFID Velvet Controller.SchDoc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]
2023-04-09 Добавил схему в .pdf. Перенс файлы проекта v2.0 в новую папку Velvet\Hardware\Velvet Controller V2.0
    [Velvet_Controller_V1.2_2023.PrjPcb, Схема GSM Velvet Controller.SchDoc, Схема LoRa и RFID Velvet Controller.SchDoc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]
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2023-04-27 Исправления приняты
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2023-05-12 DEVELOPMENT-224: Разработка печатной платы Velvet Controller #12
    [BOM Velvet Controller V2.0.xlsx, Velvet_Controller_V1.2_2023.PrjPcb, Спецификация работы микроконтроллера STM32 Velvet controller V2.0.xlsx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]
2023-05-12 DEVELOPMENT-193: Разработка принципиальной схемы Velvet ADC v2.0 (#15)
    * ПДФ схемы АЦП
    * Актуализировал схему АЦП
    * Удалил Velvet ADC v3.0, почистил Velvet ADC v2.0
    * Актуализировал схему АЦП
    ---------
    [BOM Template GOST Single Supplier.xlsx, BOM Velvet ADC module VLVA-01.xlsx, BOM_GOST_MULTIPLE_SUPP.xlsx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]
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2023-05-26 DEVELOPMENT-248: Выходные файлы для производства Velvet Controller (#20)
    * Добавлен altium bom, в ПП и схему добавлен другой разъём для uSIM
    * "Добавить тестовые пады на все цифровые провода.
    Добавить логотип КазАТУ на печатной плате
    Разместить рядом с логотипом название и версию: Velvet Controller v2.0
    Разместить поле для шести-символьного серийного номера: S/N: XX-XX-XX. Вместо XX необходимо разместить белые прямоуго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
    [BOM Velvet Controller V2.0.xlsx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]
2023-05-28 DEVELOPMENT-249: Выходные файлы Velvet ADC v2.0 (#22)
    * DEVELOPMENT-249: Выходные файлы Velvet ADC v2.0
    * герберы платы АЦП
    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
    [BOM Velvet ADC V2.0.xlsx]
2023-06-02 DEVELOPMENT-205: Считывание данных с RFID (#17)
    * Код считывания данных с RFID
    * Код считывания данных с RFID
    * произведён рефакторинг кода по части замечаний
    * произведён рефакторинг кода
    * Удалил лишние файлы
    * Добавил временные файлы проектов STM в гитигнор
    * Рефакторинг кода
    * Удалил ADC, поправил другие файлы
    * Убрал extern для очередей
    Дефинишн перенёс с заголовочные файлы
    * Исправил о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
    [VelvetApp.ioc, esp.c, hx711.c]
2023-06-27 DEVELOPMENT-166: Считывание данных с АЦП HX711 (#18)
    * DEVELOPMENT-166: Отправка данных по WIFI
    Код считывания данных с RFID
    Код считывания данных с RFID
    произведён рефакторинг кода по части замечаний
    произведён рефакторинг кода
    Отправка данных по WiFi
    * Исправлены конфликты
    Проект собирается
    * Добавлена очередь для работы с АЦП
    * Delete VelvetApp.uvguix.user
    Это файл лэйаута в uVision. Он не обязателен и у каж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
    [adc.c, esp.c, main.c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]
2023-12-03 DEVELOPMENT-261: Составить план работ для Velvet v2.1 * Поправил наименование документов
    [План работ Velvet v2.1.xlsx]
2023-12-04 DEVELOPMENT-194: Разработка печатной платы Velvet ADC (#26)
    * Залил актуальный проект АЦП
    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
    [ADC.SchDoc, BOM Velvet ADC V2.0.xlsx, Connectors.SchDoc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]
2023-12-16 DEVELOPMENT-262: Разработка технического задания Velvet v2.1 (#27)
    * DEVELOPMENT-262: Разработка технического задания Velvet v2.1
    * DEVELOPMENT-262: Техническое задание Velvet v2.1
    [План работ Velvet v2.1.xlsx]
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2024-01-04 DEVELOPMENT-261: Составить план работ для Velvet v2.1 Незначительные правки
    [План работ Velvet v2.1.xlsx]
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

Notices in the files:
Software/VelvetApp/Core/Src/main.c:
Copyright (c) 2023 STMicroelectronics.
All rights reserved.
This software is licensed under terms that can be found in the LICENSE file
